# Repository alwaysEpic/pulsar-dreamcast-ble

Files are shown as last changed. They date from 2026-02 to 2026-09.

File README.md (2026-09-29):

# Pulsar Dreamcast BLE





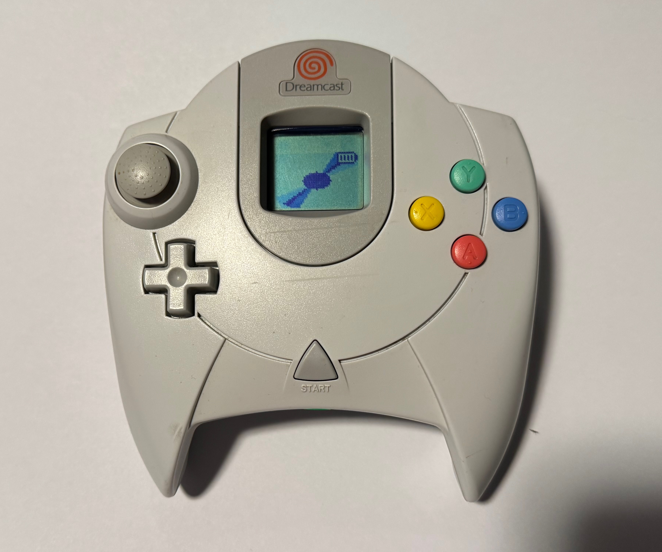
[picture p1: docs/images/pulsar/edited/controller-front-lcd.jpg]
Dreamcast controller with the Pulsar adapter's VMU LCD showing the rotating pulsar


Use your Dreamcast controller wirelessly with any Bluetooth device. Pulsar speaks the Dreamcast's Maple Bus protocol natively and presents itself as a standard Xbox One S BLE gamepad — just plug in, pair, and play.

### ⚡ [**Buy Pulsar — Dreamcast wireless controller adapter**](https://pulsar.alwaysagog.com/buy)

A complete wireless Dreamcast controller, Pulsar on its own, or the parts to build one —
at **[pulsar.alwaysagog.com](https://pulsar.alwaysagog.com/)**. Prefer to build it
yourself? [Start here](docs/build/xiao.md); everything you need is in this repo.

> **Where to get Pulsar firmware.** The only official sources are this repository's
> [Releases](https://github.com/alwaysEpic/pulsar-dreamcast-ble/releases) page and the
> updater at [pulsar.alwaysagog.com/update](https://pulsar.alwaysagog.com/update).
> Firmware ships as `.uf2`, `.hex`, or a signed OTA package — never as a `.zip`, `.exe`, or
> anything you run on a PC. Copies of this repo on other GitHub accounts that offer a
> "download" have been found carrying malware. Don't run them.

## Features

- All Dreamcast inputs: A/B/X/Y, Start, D-pad, analog stick, analog triggers
- Guide/Xbox button via a trigger + Start chord (opens the Steam overlay, Game Bar, etc.)
- Works with any BLE HID host (PC, iOS, Android, Switch, Dreamcast via iBlueControlMod)
- Two switchable identities for broad host compatibility: **Xbox** (default), or a plain **generic BLE HID gamepad** (labeled "Dreamcast" — neutral identity, not controller emulation)
- VMU LCD display: profile splash, rotating pulsar with battery indicator, mode splashes
- Host integration service: a program on the host can draw on the VMU LCD and read and write the docked VMU's saves over BLE — an open, documented protocol ([spec](docs/host_integration.md))
- 60Hz controller polling with continuous BLE reporting
- Pairing persists across power cycles (flash-based bonding)
- Battery powered (~7-8 hrs on 500mAh, ~14-16 hrs on 1000mAh) with sleep/wake support
- 3D-printable VMU-shaped enclosure included

## Compatibility

### Controllers
- Standard Dreamcast controller (first-party tested)

### Hosts

**Tested:**
- Steam Deck (as Xbox gamepad)
- macOS — browser + Steam (as Xbox gamepad)
- Windows — Steam (as Xbox gamepad)
- Linux — xpadneo (as Xbox gamepad)
- Dreamcast (via [iBlueControlMod](https://handheldlegend.com/products/dreamcast-ibluecontrolmod-bluetooth-mod) adapter)

**Should work (untested):**
- iOS, Android (as BLE HID gamepad)
- PlayStation, Nintendo Switch (as generic controller)

## Supported Boards

One firmware, three boards. They play identically; what differs is what they can show you and
how you flash them.

| Board | | Status light | Battery | Rumble | Flashing |
|---|---|---|---|---|---|
| **XIAO** | Hand-wired DIY build — the one this guide walks through | Onboard RGB | Voltage estimate | — | USB (UF2) |
| **Pulsar v1** | Designed carrier with a XIAO mounted on it | 5-LED bar (status + battery) | IP5306 gauge, 4 levels | Yes | Wireless (OTA) |
| **DK** | nRF52840-DK, bench only | Kit LEDs | — | — | Debug probe |

Pulsar v1 runs the same XIAO module as the DIY build, so the two share their silicon — the
carrier adds integrated power management, the LED bar, and a rumble motor around it. Its
fabrication files are not published, but the design is described in the
[bill of materials](docs/bill_of_materials.md) and all three boards' pin assignments are in
[pin mapping](docs/pin_mapping.md).

## Three paths — pick yours

Each board has its own guide, written to be followed start to finish.

| | Guide | For |
|---|---|---|
| 🔧 | **[Build the XIAO adapter](docs/build/xiao.md)** | The hand-wired DIY build. Perfboard, a boost converter, two resistors and two diodes. Soldering required, and it permanently modifies a controller |
| 🧪 | **[Bench setup on an nRF52840-DK](docs/build/dk.md)** | Development and debugging. No soldering, and no permanent change to a controller if you cut an extension cable instead |
| 📦 | **[Install an assembled Pulsar v1](docs/build/pulsar-v1.md)** | You bought one. Photo-by-photo: open the controller, fit Pulsar, route the cable, close it up |

Once it is together, the [user guide](docs/users_guide.md) covers all three boards, and
Pulsar v1 owners have a dedicated [owner's manual](docs/pulsar_v1_manual.md).

## Build Your Own

A summary of the **XIAO** build. The step-by-step version — cable identification, the 5 V
diode-OR, pre-power checks and first-boot behaviour — is in
**[docs/build/xiao.md](docs/build/xiao.md)**.

### What You Need

- Seeed XIAO nRF52840
- Dreamcast controller
- 5V boost converter (for battery mode)
- 2x 10kΩ resistors
- LiPo battery
- USB cable (for UF2 flashing) or debug probe (for development)

See the full [bill of materials](docs/bill_of_materials.md) for details.

### Wiring

Wiring Diagram

Connect SDCKA and SDCKB from the controller cable to the XIAO with 10kΩ pull-ups to 3.3V. The controller needs 5V power via a diode OR circuit (USB + boost converter). See [pin mapping](docs/pin_mapping.md) for the complete wiring reference.

> **Meter your cable before you solder.** The colour-to-pin table is the canonical Maple
> pinout, not a promise about the cable in your hand — third-party and later-revision
> controllers differ, and getting it wrong puts 5 V on a data line. The
> [build guide](docs/build/xiao.md#2-identify-the-cable-conductors) walks through checking
> it with a multimeter, and explains why the diode OR is there and which way round the
> diodes go.

### Flash

Pre-built firmware is available on the [Releases](https://github.com/alwaysEpic/pulsar-dreamcast-ble/releases) page.

**UF2 (recommended — no debug probe needed):**

The XIAO ships with a UF2 bootloader that includes the Nordic SoftDevice. Just double-tap the reset button — the board mounts as a USB drive (`XIAO-BOOT`) — then copy the `.uf2` file:

```bash
cp pulsar-dreamcast-ble-xiao.uf2 /Volumes/XIAO-BOOT/
```

The board auto-resets and runs the firmware.

**SWD (for development — requires J-Link or nRF52840 DK):**

If you need RTT debug logging, flash via SWD instead. The SoftDevice must be flashed separately first — see [flash commands](docs/flash-commands.md) for the full workflow.

### Pair and Play

1. Power on the adapter — it starts advertising immediately
2. On your host device, scan for **"Xbox Wireless Controller"**
3. Pair and you're done — bonding is saved automatically

**Sync button:**
- Short press → wake / request reconnect
- Hold 2s → pairing mode (keeps the current bond until a new host pairs)
- Hold 3.5s **while holding the controller's Start** → firmware update (OTA) mode
- Tap, tap, then hold 3.5s → the same update mode, no controller needed
- **Tap once, then hold 3.5s → browser configuration mode ([remap your buttons](docs/users_guide.md#remapping-buttons-from-your-browser))**
- Hold 7s → sleep (`BYE` splash, then powers off)
- Triple-press → switch profile (Xbox ⇄ Dreamcast identity)

**Guide / Xbox button:** pull both triggers and hold Start (~⅓ second) to send the Guide button — opens the Steam overlay / Big Picture, the Xbox Game Bar, etc. Works on both profiles.

The VMU LCD shows the active profile on connect, a rotating pulsar with battery indicator while in use, a home icon when you press the Guide chord, and splashes for pairing (`SYNC`) and sleeping (`BYE`).

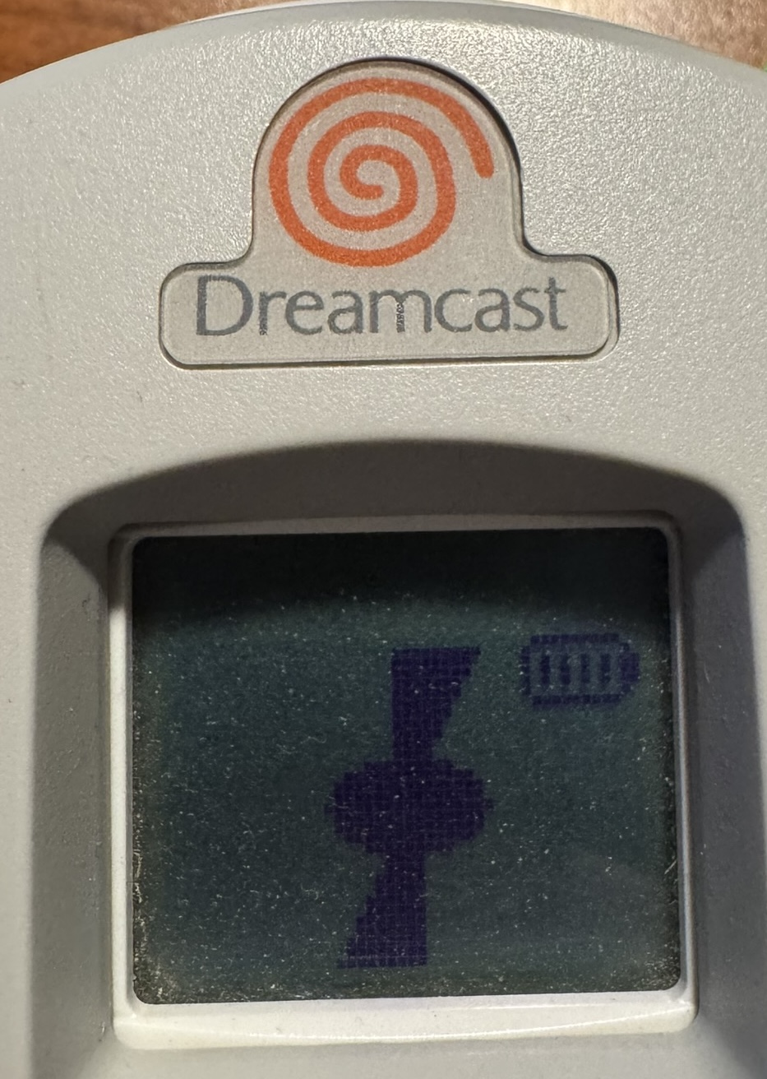
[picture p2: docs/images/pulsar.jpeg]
Rotating pulsar animation on the VMU LCD


See the [user guide](docs/users_guide.md) for all screens, profile choice, and troubleshooting.

### Enclosure

A 3D-printable VMU-shaped case is included in [`hardware/enclosure/`](hardware/enclosure/). See [hardware/enclosure/README.md](hardware/enclosure/README.md) for print tips and attribution.

<table>
  <tr>
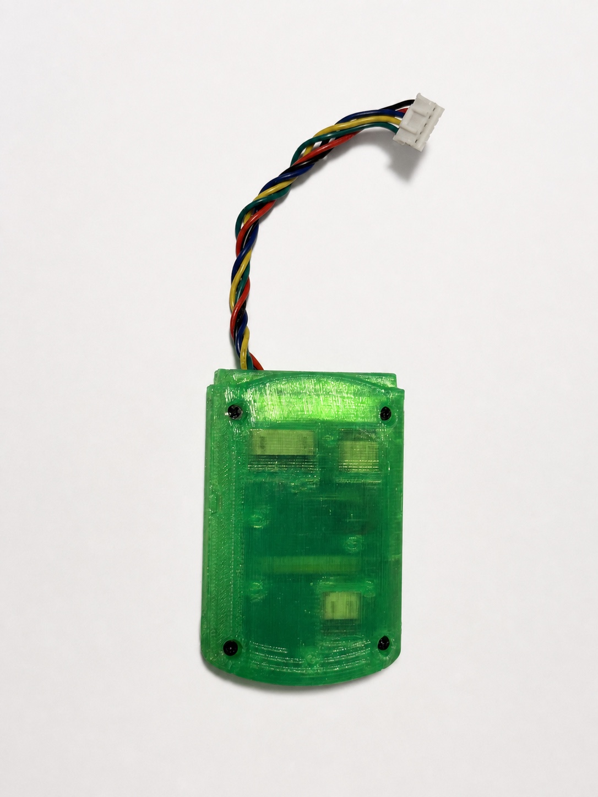
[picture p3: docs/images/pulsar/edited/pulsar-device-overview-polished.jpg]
Assembled Pulsar adapter, front
    <td></td>
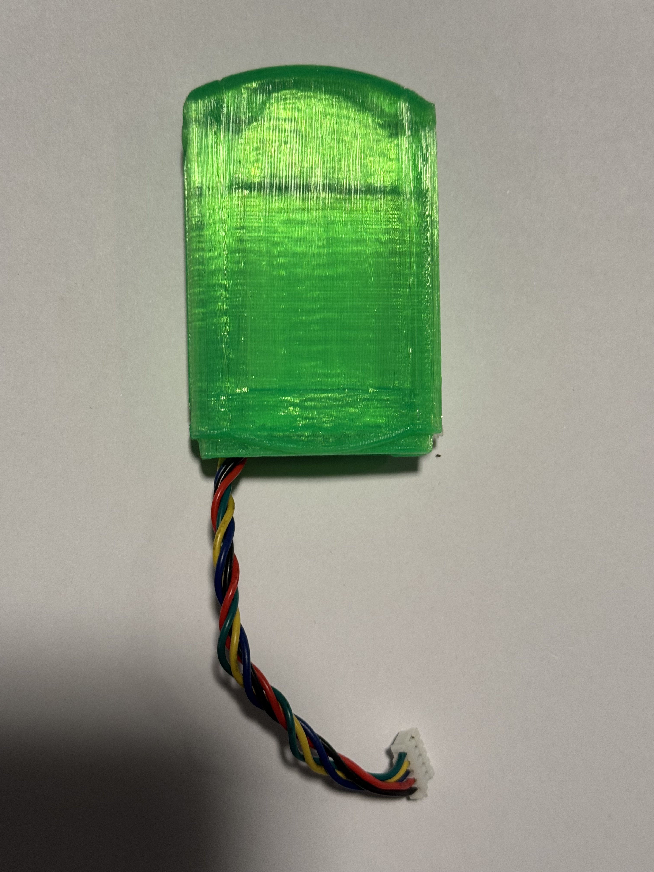
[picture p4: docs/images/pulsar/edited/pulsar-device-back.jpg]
Assembled Pulsar adapter, back with controller cable
    <td></td>
  </tr>
  <tr>
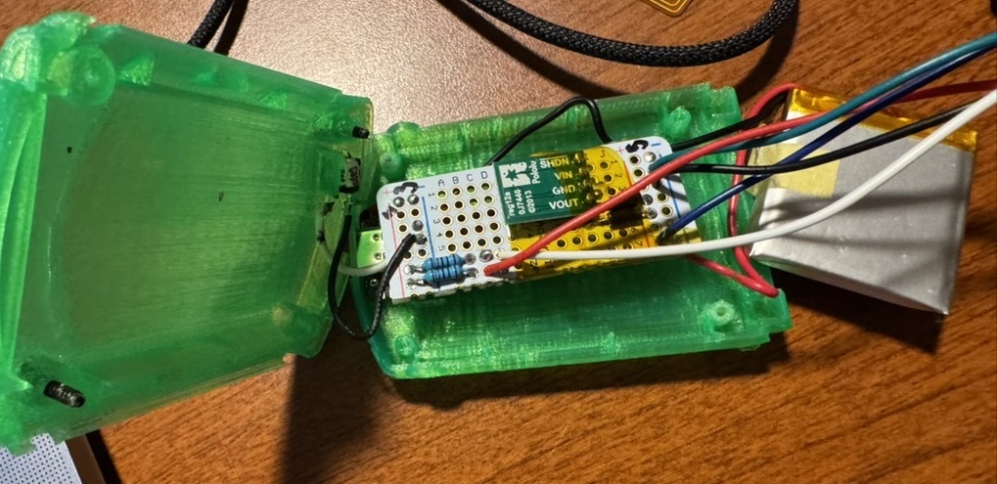
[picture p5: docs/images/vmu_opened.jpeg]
Inside the enclosure
    <td></td>
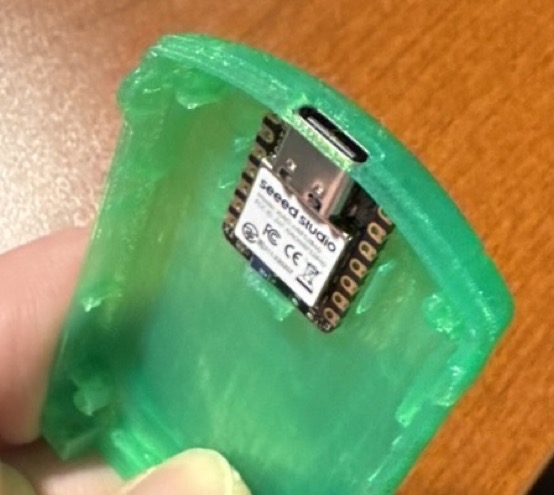
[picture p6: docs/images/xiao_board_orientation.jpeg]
XIAO board orientation
    <td></td>
  </tr>
</table>

## For Developers

### Building from Source

Requires Rust stable with `thumbv7em-none-eabihf` target:

```bash
rustup target add thumbv7em-none-eabihf
cargo install cargo-embed
```

**XIAO** (must use `--release` — debug builds break Maple Bus timing):
```bash
# Production
cargo embed --release --no-default-features --features board-xiao

# Development (with RTT debug logging)
cargo embed --release --no-default-features --features board-xiao,rtt
```

**DK** (RTT always enabled):
```bash
cargo embed --release
```

**Pulsar v1** (ships as a signed OTA package; SWD is for bring-up only):
```bash
cargo build --release --no-default-features --features board-pulsarv1
```

Each board has a start-to-finish guide under [`docs/build/`](docs/build/).

### Testing

The `maple-protocol` crate is pure Rust with no embedded dependencies — tests run on the host:

```bash
cd maple-protocol && cargo test
```

### Architecture

The project is split into two crates:

- **`maple-protocol/`** — Pure protocol library: controller state parsing, packet construction, Xbox HID report generation. No hardware dependencies, fully host-testable.
- **`src/`** — Firmware: Maple Bus GPIO bit-banging, BLE stack (Nordic SoftDevice S140), board support, button handling, power management.

The GPIO implementation bulk-samples both data lines at ~7.9 MS/s (≈4 samples per 500 ns bit) to capture the 2 Mbps Maple Bus protocol, then decodes in software. This is an nRF52840-specific approach — other chips (e.g., RP2040 with PIO) could implement the same protocol differently. See [maple_bus_protocol.md](docs/maple_bus_protocol.md) for the full protocol reference.

### Running Checks

```bash
./scripts/ci.sh
```

Runs formatting, the protocol tests, clippy for all three boards, every release build, and
then checks each ELF's timing invariants. `./scripts/check.sh [dk|xiao|pulsarv1]` is the ~2 s
inner loop to run after every change; `ci.sh` is the gate before a commit.

## Documentation

[`docs/MOC.md`](docs/MOC.md) indexes everything. The main entries:

| Document | Description |
|---|---|
| [Build guides](docs/build/) | One per board: [XIAO](docs/build/xiao.md), [DK](docs/build/dk.md), [Pulsar v1](docs/build/pulsar-v1.md) |
| [User Guide](docs/users_guide.md) | Using the adapter, across all three boards |
| [Owner's Manual](docs/pulsar_v1_manual.md) | For an assembled Pulsar v1 |
| [Bill of Materials](docs/bill_of_materials.md) | Parts list for building your own |
| [Pin Mapping](docs/pin_mapping.md) | Complete wiring reference for all three boards |
| [Flash Commands](docs/flash-commands.md) | Flashing and debugging cheat sheet |
| [Maple Bus Protocol](docs/maple_bus_protocol.md) | Protocol reference and implementation details |
| [Host Integration](docs/host_integration.md) | The BLE service a host uses to drive the VMU's screen and saves |
| [Input Quality Testing](docs/input_quality_testing.md) | Measuring latency and packet loss |
| [Battery Optimization](docs/battery_optimization.md) | Power management strategy |
| [Learnings](docs/learnings.md) | Implementation lessons learned |

## Releases

Pre-built firmware is available on the [Releases](https://github.com/alwaysEpic/pulsar-dreamcast-ble/releases) page. Each release includes:

- **`pulsar-dreamcast-ble-xiao.uf2`** — XIAO firmware, drag-and-drop via UF2 bootloader
- **`pulsar-dreamcast-ble-xiao.hex`** — XIAO firmware, for flashing via J-Link/SWD
- **`pulsar-dreamcast-ble-dk.hex`** — DK firmware, for flashing via J-Link

3D scan archives are also attached to releases.

Pulsar v1 units update over the air from
[pulsar.alwaysagog.com/update](https://pulsar.alwaysagog.com/update); the packages are signed
and the device refuses anything else. There are no other download locations. If a copy of this
repo somewhere else offers a `.zip` or a Windows program, it isn't ours — see the note at the top.

## Contributing

Contributions are welcome! See [CONTRIBUTING.md](CONTRIBUTING.md) for build instructions, project structure, and how to submit changes.

## License

This project is licensed under the [GNU General Public License v3.0 or later](LICENSE). 3D model files have separate licensing — see [hardware/enclosure/README.md](hardware/enclosure/README.md).

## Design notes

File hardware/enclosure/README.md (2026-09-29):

# 3D Models & Enclosure Files

This directory contains 3D models for a VMU-shaped enclosure for the Dreamcast BLE adapter.

## Which shell do I print?

Two different builds live in `Edited_VMU_stls/`, and they are not interchangeable — the
hand-wired XIAO build and the Pulsar v1 carrier are different shapes inside.

| Folder | For | Notes |
|---|---|---|
| `dreamcast_vmu_*.stl` (loose, at the top of `Edited_VMU_stls/`) | **[The hand-wired XIAO build](../../docs/build/xiao.md)** | Front plus three back variants — plain, `_cutout`, and `_w_cutout` — differing in the opening for your wiring. Print the front and whichever back suits how you routed the cable |
| `PulsarFit_703035/` | **Pulsar v1 carrier**, 703035 cell | The baseline fit: a 7.0 × 30 × 35 mm, ~800 mAh pouch. Clearance at the dome crown is ~0.5 mm, so it wants that cell. Ships a `PRINT_PLATE.stl` with the parts laid out |
| `PulsarFit_bigcell/` | **Pulsar v1 carrier**, larger cells | Same rear and plunger; the **front** hollows the dome to a constant 1.0 mm wall, raising crown clearance to ~1.5 mm so taller pouches fit. Includes `pulsar_bigcell.3mf` — the slicer project with orientation, supports and settings the STLs alone do not carry |
| `PulsarFit_bigcell_cable_relief/` | **Pulsar v1 carrier**, big cell, cable-corner relief | ⚠️ **Experimental — not yet fit-tested.** Adds a filleted relief cut at the cable corner of *both* halves, for a pinch between the shell corner and the controller's connector housing. Print it only if you hit that pinch. Includes `pulsar_bigcell_cable_relief.3mf` |

> The cable-relief variant was cut in a live modelling session rather than by the build
> scripts, so re-running `blender_files/build_pulsar_vmu*.py` reproduces the shells
> **without** it. Treat those STLs as the source of truth for that variant.

Every Pulsar-fit family shares the same `pulsar_vmu_button_plunger.stl`.

## Contents

- **`blender_files/`** — Blender source files for the modified VMU enclosure (by alwaysEpic)
- **`Edited_VMU_stls/`** — Modified STL exports ready for printing (by alwaysEpic); see the
  table above for which folder matches your build
- **`VMU_ShellAssembly.step`** — STEP assembly file
- **`pulsar_pcb.stl`**, **`Pulsar.step`** — the carrier board as a mesh/solid, for fit-checking only. Not manufacturing data; no board can be fabricated from them.
- **`cable_hole_plug.stl`** — Cable hole plug by [byt3swap](https://github.com/byt3swap/dreamwave-enhanced) (used with permission)

## Printing Tips

The front and back halves print best at roughly a 45-degree angle with a few supports. This gives cleaner surfaces and avoids overhangs on the curved shell edges.

## Attribution

- **Modified enclosure** (Blender files, edited STLs) by [alwaysEpic](https://github.com/alwaysEpic) — modelled against the VMU scans below. If you use or remix these, please credit the author.
- **VMU 3D scans** by [Wesk](https://bitbuilt.net/forums/threads/dreamcast-vmu-scan.3988/) — the reference this enclosure was built from.
- **Cable hole plug** by [byt3swap](https://github.com/byt3swap/dreamwave-enhanced) — used with permission

## License

These files are **not** covered by the project's GPL-3.0 licence.

The Blender sources and edited STLs are the author's own modelling work — the Pulsar cutouts, pockets, plunger, tolerances, and print splits — and are offered under [CC BY 4.0](https://creativecommons.org/licenses/by/4.0/): use, modify, and redistribute them with attribution.

That grant covers only the author's own modelling work. `cable_hole_plug.stl` is byt3swap's and is included by permission; its terms are theirs, not ours.

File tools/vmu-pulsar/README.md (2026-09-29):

# VMU pulsar animation

The rotating pulsar on the VMU LCD is rendered in Blender and baked to a 1-bit
frame table, `src/vmu/pulsar_frames.rs`. Nothing here runs at build time; the
generated file is committed.

```bash
cd tools/vmu-pulsar
/Applications/Blender.app/Contents/MacOS/Blender -b -P render_pulsar.py -- "$PWD/renders" 12
uv run --with pillow --with numpy python bake_frames.py renders ../../src/vmu/pulsar_frames.rs renders/preview.gif
```

`renders/` is ignored. `preview.gif` plays the frames at the firmware's rate
(~300 ms, `VMU_ANIM_INTERVAL` polls) in VMU LCD colours.

- **Frame count** is `ROTATION_FRAMES` in `src/vmu.rs`. It must match the render,
  and the firmware rate is fixed, so more frames means a slower spin.
- **Geometry** (tilt, beam width, fade) lives in `render_pulsar.py`.
- **Composition** (dither, star disc, sky, flash) lives in `bake_frames.py`.

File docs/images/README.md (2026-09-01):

# Images

Photos of the Dreamcast BLE adapter build.

## Assembly Photos

| File | Description |
|---|---|
| `vmu_front.jpeg` | Enclosure front — controller cable exits bottom |
| `vmu_back.jpeg` | Enclosure back — screw holes visible |
| `vmu_opened.jpeg` | Enclosure opened — perfboard, Pololu boost, pull-up resistors |
| `vmu_opened2.jpeg` | Enclosure opened — alternate angle showing battery and wiring |
| `xiao_board_orientation.jpeg` | XIAO board seated in enclosure front — USB-C and sync button visible |
| `vmu_in_controller.jpeg` | Adapter installed in Dreamcast controller VMU slot — front view |
| `vmu_in_controller2.jpeg` | Adapter installed — side angle showing Dreamcast logo |
| `back_fit.jpeg` | Controller back shell — VMU enclosure fit with wiring routed |
| `vmu_slot_holes.jpeg` | VMU slot closeup — arrow showing cable routing |
| `controller_modification.jpeg` | Controller shell modification — arrows showing trimmed plastic for cable clearance |
| `larger_wiring_example.jpeg` | Perfboard wiring — XIAO, boost converter, battery, controller cable |
| `breadboard_wiring.jpeg` | DK development breadboard — pull-ups and controller cable connections |

## Install Photos

`install/` — the photo-by-photo sequence for
[fitting a Pulsar v1 into a controller](../build/pulsar-v1.md). Same exports the site's
install page uses.

| File | Description |
|---|---|
| `controller-back-screws.webp` | The six screw positions on the controller's back shell |
| `controller-open-cable-connected.webp` | Controller open, original cable still connected |
| `dreamcast-cable-removed.webp` | Original cable and strain relief lifted out |
| `second-accessory-slot.webp` | The empty second accessory slot |
| `pulsar-installed-overview.webp` | Pulsar seated in slot 2, cable routed to the right-hand opening |
| `pulsar-cable-connected.webp` | Pulsar's plug seated in the controller connector — plug orientation |
| `back-cover-cable-guard-before.webp` | Inside of the back shell, cable guard still present |
| `back-cover-cable-guard-removed.webp` | The same shell after a clean break |
| `cable-cover-and-routing.webp` | Printed cable cover fitted around the Pulsar cable |

## Wiring Diagrams

See [`../wiring/`](../wiring/) for the Fritzing diagram and breadboard export.

## Metadata

Every image here is published. **Before adding one, strip its metadata and verify:**

```bash
python3 scripts/image_metadata.py strip docs/images   # lossless — drops APP segments only
python3 scripts/image_metadata.py scan  docs          # exits 1 if any GPS remains
```

Stripping is lossless — JPEG scan data is untouched and only whole APP segments are
dropped, so there is no requantisation. A non-default `Orientation` is preserved; drop it
and the affected images rotate.

**Verify by parsing the file, not by asking an indexer.** On macOS, `mdls -name
kMDItemLatitude` reads the Spotlight index rather than the image and returns `(null)` for
anything Spotlight has not indexed — it will happily report a GPS-laden photo as clean.
The script above parses the containers directly (JPEG APP segments, PNG `eXIf`, WebP
`EXIF`/`XMP `) and exits non-zero when a GPS IFD is present.

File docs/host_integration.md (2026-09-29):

# Host Integration Service

A vendor GATT service that lets a host — a console-side dongle, an emulator,
or a script on a laptop — drive the VMU docked in a Pulsar controller: push
frames to its LCD, and read and write the physical memory card's 512-byte
blocks. It first shipped in firmware **0.6.0**; no earlier release carries it.

This is an *open* vendor characteristic set: anything malformed that arrives
on it is dropped in silence rather than erroring the connection. It exists so
a third party can write a sender without our hardware in the room.

## How to tell it is a Pulsar

Look for the service UUID below in the GATT table after connecting — it is
not advertised, so it will not appear in a scan result, only after connect
and discovery. It is present identically under **both** gamepad personalities
(the Xbox identity and the generic one): they share one GATT table, and the
personality only changes the GAP name, the PnP IDs and the HID report
descriptor. The service, not the identity, is what marks a Pulsar. The third
personality, `Pulsar Configure` (browser remapping), is a different GATT
table and does not carry this service.

## Service and characteristics

| Name | UUID | Properties | Security | Max length |
|---|---|---|---|---|
| `HostService` | `7EDF0001-3536-4A03-82D0-8AB9122016C6` | (primary service) | — | — |
| LCD frame | `7EDF0002-3536-4A03-82D0-8AB9122016C6` | Write Without Response | JustWorks | 192 B |
| VMU storage, up | `7EDF0003-3536-4A03-82D0-8AB9122016C6` | Notify | JustWorks | 132 B |
| VMU storage, down | `7EDF0004-3536-4A03-82D0-8AB9122016C6` | Write Without Response | JustWorks | 132 B |

Security is `JustWorks` — encrypted, unauthenticated — the same level as the
HID report characteristics. A host already bonded as a gamepad gets this for
free. Both down characteristics are Write Without Response, which by the ATT
spec never answers, so **a write on an unencrypted link is dropped in
silence** — there is no error to catch. **Pair the controller with the host
first.**

Only the bonded host may use the service. While a bond exists, a different
device that tries to pair outside the pairing window (the 2-second sync hold)
is disconnected, and nothing it writes to this service is acted on. Nothing
is notified on a link that is not encrypted.

This keeps out devices that merely happen to be in range. It is not
authentication: pairing is Just Works (there is no code to confirm), and the
bonded host is recognised by its Bluetooth address. A device that deliberately
impersonates that address can still pair.

The firmware requests an ATT MTU of 247 on connection; what a link actually
gets depends on the host's stack (some grant less). Two thresholds matter:

- **LCD:** a whole 192-byte frame needs a negotiated MTU of at least 195 to fit
  one write. Below that, use the four-write chunked shape described below.
  Both shapes are always accepted, told apart purely by the write's length —
  a sender never has to announce which one it is using.
- **VMU storage:** every `DATA` notification and every `WRITE` phase is 132
  bytes, so the storage protocol needs an MTU of **at least 135**. It has no
  chunked alternative; on a smaller MTU, do not use it.

## LCD frame channel

The VMU LCD is 48×32 pixels, 1 bit per pixel, 192 bytes total: 32 rows of 6
bytes each, MSB = leftmost pixel, and a set bit is a lit (dark) segment. This
is the same layout the Dreamcast itself puts on the Maple bus in a
`BLOCK_WRITE` to function `0x04` — the payload is exactly what a real console
would send to the VMU's LCD.

**Send the frame unrotated.** The VMU sits upside-down in the controller, and
Pulsar corrects for that in firmware before the frame reaches the physical
screen. A sender that pre-rotates ends up upside-down; frames arriving from a
Maple `BLOCK_WRITE` capture, or drawn upright, are already correct.

### Wire shapes

| Shape | Length | Contents |
|---|---|---|
| Whole frame | 192 bytes | The full frame, row-major, as above. |
| Chunk (×4) | 49 bytes | `[row_offset, chunk[48]]` — one 8-row band. |

`row_offset` is one of `0, 8, 16, 24` and must land on that boundary; a chunk
whose offset is not a multiple of 8, or out of range, is dropped. Offset `0`
starts a new frame — writing it clears whatever partial assembly was in
progress, so a sender that drops a chunk mid-frame resynchronises cleanly on
its next pass instead of ever producing a frame stitched from two sources.
The frame becomes visible only once all four chunks have arrived. Send the
chunks in order, `0` first: a set sent `8, 16, 24, 0` never completes, since the
final `0` starts over. A whole-frame write also discards any partial chunk set.

A write of any other length is dropped and never reaches the screen.

**The host owns the screen from its first frame until the link drops.** The
adapter's own animation stops while a host is drawing and resumes after the
disconnect. One exception: while acked VMU writes are draining onto the card
(below), the firmware overlays a small disk icon on the top-left corner of
whatever is on screen, the host's frame included, and removes it when the
drain ends.

Frames **replace**, they are never queued: sending faster than the display
can draw simply loses the frames in between, which is the right behaviour for
a screen. There is no acknowledgement on this characteristic either way — a
frame can be dropped by the radio, or by the VMU's own CRC on the Maple bus,
and nothing reports it back. Send something recognisable and look at the
screen.

### Sample frame

A small asymmetric test pattern — a border plus a filled block in one
corner — so a rotation mistake anywhere in the chain is visible as the block
landing in the wrong corner. 32 rows of 6 bytes, whole-frame shape:

```
FF FF FF FF FF FF
80 00 00 00 00 01
BF C0 00 00 00 01
BF C0 00 00 00 01
BF C0 00 00 00 01
BF C0 00 00 00 01
BF C0 00 00 00 01
BF C0 00 00 00 01
BF C0 00 00 00 01
BF C0 00 00 00 01
80 00 00 00 00 01   (repeats through row 30)
FF FF FF FF FF FF
```

### Reference sender

`scripts/lcd_push.py` is a standalone `uv`-run script (`bleak` + `pillow`)
that connects, negotiates the shape from the actual negotiated MTU, and
streams either a built-in pattern or a 48×32 image:

```
uv run scripts/lcd_push.py --scan                        # find the controller
uv run scripts/lcd_push.py --connected --pattern corner   # macOS, already paired
uv run scripts/lcd_push.py --address <addr> --png art.png --shape chunks
uv run scripts/lcd_push.py --pattern corner --hex         # dump the bytes, no radio
```

On macOS specifically: pair through System Settings first, then use
`--connected` — a paired controller stops advertising, so `--scan`/`--address`
cannot see it; `--connected` asks the OS for the already-connected device by
service UUID instead.

## VMU storage protocol (v1)

Read and write access to the 512-byte blocks of
the VMU physically docked in the controller, over the `…0003`/`…0004` pair.
Block numbers are one byte, `0`–`255`; `255` is the card's root block and
`254` its FAT, in the standard VMU filesystem layout.

**Byte order.** Every payload on this protocol — a `81 DATA` reply, and a `02
WRITE` request where that exists — carries a block's bytes in **image
order**: the order the VMU's own filesystem lays them out in, which is *not*
the raw word order the Maple bus carries them in (the wire reverses each
32-bit word). The firmware converts once, on the way in and out; a reader
does not need to know the wire order exists.

### Down: `…0004`, Write Without Response

| Op | Bytes | Meaning |
|---|---|---|
| `0x01` READ | `[01, blk]` | Request one block. One outstanding at a time — see below. |
| `0x03` STATUS? | `[03]` | Ask for a `STATUS` notification on demand. |
| `0x02` WRITE | `[02, blk, phase, seq]` + 128 B | One of four phases of a block write — see [Writing a block](#writing-a-block). |

Lengths are exact: `READ` is 2 bytes, `STATUS?` 1 byte, `WRITE` 132 bytes.
Anything else is dropped in silence.

A `READ` sent while one is already outstanding (including while its `DATA`
phases are still going out) is silently refused — nothing is sent back, not
even an error. The rule is the sender's to keep: wait for the fourth `DATA`
(or a `DATA` carrying a non-zero result) before issuing the next `READ`.

A `READ` accepted while the pad is in use is **held, not refused**: it is
served once the pad goes idle, and if input resumes mid-read the firmware
recalls it and serves it again at the next idle. Only a `READ` with no VMU
docked is answered at once (`DATA … NO_VMU`).

### Up: `…0003`, Notify

| Op | Bytes | When |
|---|---|---|
| `0x81` DATA | `[81, blk, phase, result]` + 128 B, or just the 4-byte header when `result != 0` | Four per successful `READ`, phases `0`–`3`; one message with no data on failure. |
| `0x83` STATUS | `[83, proto=1, flags, queue_free, epoch u32 LE, card u32 LE]` (12 bytes) | On subscribe, on request (`03`), and whenever `flags`, `queue_free`, `epoch` or `card` change while connected. On reconnect, a change to `flags` or `queue_free` made while the link was down is announced, but a moved `epoch` or `card` is not — send `03`. |
| `0x82` ACK | `[82, blk, seq, result]` (4 bytes) | Answers a completed four-phase `WRITE`, or a phase that broke the rules (`BAD`). |
| `0x84` WRITTEN | `[84, blk, seq, result]` (4 bytes) | Once per acked `seq`, when its fate is known. One in flight as the link drops can be lost: see [Sessions and reconnects](#sessions-and-reconnects). |

Messages go out in a fixed priority: `STATUS` first, then `ACK`s (and
`WRITTEN … SUPERSEDED`), then other `WRITTEN`s in drain order, then `DATA`.
`STATUS` leads because it is one message and a host may be blocked on it
right after connecting; `DATA` is last because a block's phases wait on
nothing, and the pad is idle by definition while a read is being served.

### `flags` (byte 2 of `STATUS`)

| Bit | Name | Meaning |
|---|---|---|
| 0 | `vmu_present` | A VMU is docked and enumerated. |
| 1 | `enabled` | Always `1` at this revision. Reserved for a future setting that turns the service off; until one exists it carries no information. |
| 2 | `draining` | One or more acked writes are staged or being written and not yet confirmed on the card. Always `0` on builds without the write path. |
| 3 | `idle` | The pad has gone at least 1 second with no button change and no stick or trigger movement past a small deadzone. Reads are served only while this is set. |

### `result` codes

| Code | Name | Meaning |
|---|---|---|
| `0` | OK | |
| `1` | FULL | The `WRITE` was refused: no free queue slot, or the card's fingerprint is not yet known (read blocks `255` and `254` first). |
| `2` | NO_VMU | No VMU is docked. |
| `3` | DISABLED | Reserved for the same future setting as `enabled`; never produced at this revision. |
| `4` | FAILED | `DATA`: the block read failed every attempt the firmware allows. `WRITTEN`: the write could not be confirmed within the firmware's attempts — the card refused a phase or the commit, or the read-back did not match or could not be read. This also ends the current generation (below). |
| `5` | DISCARDED | The generation ended (below) before this READ or WRITE could be answered normally. |
| `6` | SUPERSEDED | A different `seq` for the same block replaced this one while it was still staged; nothing was written under the superseded `seq`. |
| `7` | BAD | A `WRITE` phase broke the assembly rules ([Writing a block](#writing-a-block)). |

### Reading a block

1. Subscribe to `…0003`. A `STATUS` notification follows immediately.
2. Check `flags`: bit 0 (`vmu_present`) must be set, and reads only progress
   while bit 3 (`idle`) is set — put the pad down and leave it alone.
3. Write `[0x01, blk]` to `…0004`.
4. Collect four `81 DATA` notifications, `phase` `0`–`3`, each `result == 0`
   with 128 bytes of payload; concatenate `phase * 128 .. +128` in order to
   reassemble the 512-byte block. A single `DATA` with `result != 0` and no
   payload ends the request instead — inspect the `result` code.
5. Only after that (or after a non-zero-result `DATA`) may the next `READ` be
   issued.

**Generations.** `epoch` moves whenever the docked card is no longer known to
be the one being served: a dock or an undock, the controller being lost, the
link dropping (see [Sessions and reconnects](#sessions-and-reconnects)), the
controller's power going down (including sleep), a write that `FAILED`, or the
firmware being unable to confirm the card is the same one after a write was
interrupted. Its first value after boot is arbitrary. If a generation ends
while a `READ` is outstanding or its `DATA` phases are still going out,
whatever was owed becomes a single `DATA … DISCARDED` rather than silence, so a
sender is never left waiting for a fourth phase that will not come. Staged
writes become `WRITTEN … DISCARDED` the same way.

**The card fingerprint.** `card` in `STATUS` is an FNV-1a 32-bit hash, seed
`0x811C9DC5`, taken over block `255`'s 512 bytes and then block `254`'s, both
in image order — it reads `0` until both blocks have been read (or
written) at least once in the current generation. A
host that wants to know it is talking about the same card it already knows
should compare this against its own hash of the same two blocks, computed
the same way.

### Writing a block

**Which builds write.** Pulsar v1 and XIAO builds serve both reads and
writes. The DK build has no VMU storage path at all: it reports no VMU
(`flags` reads `0x02`), answers every `READ` with `DATA … NO_VMU`, keeps
`queue_free` at `0`, and answers every completed `WRITE` with `ACK … NO_VMU`.
A sender should honour `STATUS` rather than assume either.

To write a block:

1. Send four `02 WRITE` phases for the same block and the same `seq` (a
   sender-chosen byte, one value per block write), phase `0` first and in
   order. Phase `0` always starts a fresh assembly, discarding any half-sent
   one. Resending a phase already received overwrites it. Answered
   `ACK … BAD` and discarded: a phase `≥ 4`; phase `1`–`3` with no assembly
   open, or for a different block or `seq`; a phase that skips ahead.
2. Once all four phases are in, the block is staged and answered
   `ACK … OK` — or refused: `NO_VMU` if nothing is docked, `FULL` if the
   queue has no room, is not open, or the card's fingerprint is not yet known
   (read blocks `255` and `254` first).
3. A resend of a `(block, seq)` the firmware still holds — a retry after a lost
   `ACK` — is acknowledged again without being staged twice. A `WRITE` for a
   block that is still staged under a different `seq` replaces it in place,
   keeping its position in the drain order; the replaced `seq` receives
   `WRITTEN … SUPERSEDED` immediately, and the new one its own `ACK` and,
   later, its own `WRITTEN`. If the earlier write has already started going to
   the card, the new one is staged separately and drains after it.
4. Staged blocks drain to the physical card in the order they were first
   staged. Each one receives one `WRITTEN` (unless the link drops as it goes
   out; see below): `OK` once the firmware has
   read the block back from the card and it matched, `FAILED` if that could not
   be achieved (which also ends the generation — every other block still
   staged becomes `DISCARDED`), or `DISCARDED` if the generation ends first for
   any other reason.

The queue holds **8** blocks. `queue_free` in `STATUS` is the number of free
slots and is the flow-control signal: never have more acked-but-unwritten
writes in flight than the last `queue_free` allowed. A slot stays occupied
until its `WRITTEN` has been sent.

**Keep a retry timer.** If the firmware's outgoing buffer is full, a completed
`WRITE` can be dropped with no `ACK` at all. Resend the same `(block, seq)`
until it is acked; step 3 makes that safe while the firmware still holds the
block. Once the `ACK` arrives, stop resending: a resend that lands after the
block's `WRITTEN` has gone out is staged again, written a second time (the same
bytes, so the card is unharmed), and answered with a second `ACK` and
`WRITTEN`. A sender should tolerate that pair rather than rely on never
seeing it. The `WRITTEN` is always the answer that counts: an `ACK … OK` for
a resend after a reconnect can be followed by `WRITTEN … DISCARDED`.

### Sessions and reconnects

A dropped link immediately loses what was in flight: an outstanding `READ`, a
half-sent `DATA`, a half-assembled `WRITE` and any undelivered `ACK`s.

Acked writes keep draining onto the card while the link is down, for up to
30 seconds. Once nothing is left to drain (at once, if the queue was empty), or
when the 30 seconds run out, the generation ends: `epoch` moves, `card` reads
`0`, and anything still staged becomes `WRITTEN … DISCARDED`. Every `WRITTEN`
still owed at the drop, whatever its result, is delivered on the next
connection. The exception is one already handed to the radio: a `WRITTEN` in
flight as the link drops can be lost, and it is not sent again.

So on reconnect, read `STATUS` (send `03`, below). An unchanged `epoch` means
the host reconnected while its writes were still draining, and the generation
carried on. A moved `epoch` means read blocks `255` and `254` again before
writing, then resend whatever came back `DISCARDED`, and anything never acked.

Either way, do not wait on `WRITTEN`s for writes acked before the drop. Once
`STATUS` shows `draining` clear, a write that still has no `WRITTEN` has an
unknown fate: read the block back and compare, or resend it. A resend is safe
(step 3 above): the same bytes are written again and answered with a fresh
`WRITTEN`.

`STATUS` is sent when the host *writes* the CCCD to enable notifications. A
host that relies on a subscription restored from the bond may get no `STATUS`
until something changes, so **send `[03]` after every connect**.

## Reference scripts

Both are standalone `uv`-run Python (no project virtualenv needed):

```
uv run scripts/lcd_push.py --connected --pattern corner
uv run scripts/vmu_read.py --connected                      # root + FAT
uv run scripts/vmu_read.py --connected --pull                # the whole used working set
uv run scripts/vmu_read.py --connected --blocks 255 --hexdump
```

`vmu_read.py` shares `lcd_push.py`'s connection handling (including the
macOS `--connected` pairing workaround above), decodes `STATUS`/`DATA`,
verifies the root block parses correctly in image order, and cross-checks its
own computed `card` fingerprint against the firmware's. `--pull` walks the
root block, FAT and directory to fetch those plus every user-area block the
FAT marks as used. Neither script exercises the write path (`02 WRITE`);
there is no public reference writer yet, and the write section above is
specified from the firmware's code and tests.

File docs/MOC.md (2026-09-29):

---
type: moc
created: 2026-08-06
tags: [index, public]
---

Map of content for the documentation tree. One line per doc — read this to locate a doc
rather than preloading the folder.

## Build and use

Three boards, three build paths. Pick the one that matches what you have:

- [`build/xiao.md`](build/xiao.md) — **the DIY build.** Hand-wired XIAO nRF52840: parts,
  identifying the cable conductors, the 5 V diode-OR, pull-ups, pre-power checks, UF2
  flashing, first boot, enclosure
- [`build/dk.md`](build/dk.md) — **the bench build.** nRF52840-DK on a breadboard; no
  soldering, external 5 V, SWD flashing and RTT. What behaves differently on this board
- [`build/pulsar-v1.md`](build/pulsar-v1.md) — **installing an assembled Pulsar v1** in a
  controller, photo by photo. Markdown copy of the site's install guide

- [`pulsar_v1_manual.md`](pulsar_v1_manual.md) — owner's manual for an assembled Pulsar v1:
  connecting a controller, buttons, LEDs, charging, updating. Start here for a shipped unit
- [`users_guide.md`](users_guide.md) — the same ground across all three boards (v1, DIY
  XIAO, DK); the reference the manual defers to
- [`flash-commands.md`](flash-commands.md) — UF2, DFU, and probe recipes; build variants
- [`bill_of_materials.md`](bill_of_materials.md) — parts for the XIAO and Pulsar v1 builds
- [`pin_mapping.md`](pin_mapping.md) — pin assignments across all three boards

## Protocol and firmware

- [`maple_bus_protocol.md`](maple_bus_protocol.md) — the Maple Bus reference, consolidated
  from three sources; the authoritative copy
- [`learnings.md`](learnings.md) — lessons from 2 Mbps bit-banged GPIO on the nRF52840,
  written to generalize beyond this project
- [`input_quality_testing.md`](input_quality_testing.md) — measuring packet loss and
  input latency; the issue #5 investigation end to end
- [`test_plan.md`](test_plan.md) — the full adapter test plan
- [`host_integration.md`](host_integration.md) — the vendor GATT service a host uses
  to drive the docked VMU — LCD frames in both wire shapes, and the VMU storage protocol v1

## Power

- [`battery_optimization.md`](battery_optimization.md) — power strategy on a single-cell
  LiPo; measured active runtimes, calculated standby

## Assets

`images/`, `wiring/`, and `signal_references/` — photos, wiring diagrams, and captured
Maple Bus traces referenced by the docs above.

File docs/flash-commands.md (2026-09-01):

# Flash & Debug Reference

Three boards, three routes. Pick by what you have:

| Board | Feature | How it's flashed |
|---|---|---|
| **XIAO** | `board-xiao` | [UF2 over USB](#uf2-flashing-recommended) — no probe needed. Add `,rtt` for debug logging |
| **DK** | `board-dk` | [SWD](#swd-flashing-development) via the onboard J-Link. Includes `rtt` by default |
| **Pulsar v1** | `board-pulsarv1` | [Signed OTA](#pulsar-v1-signed-ota), or SWD for bring-up |

Release builds are mandatory on all three — debug builds miss the Maple Bus timing window.

## UF2 Flashing (Recommended)

The easiest way to flash the XIAO — no debug probe needed. The XIAO ships with a UF2 bootloader that includes the Nordic SoftDevice S140 v7.3.0.

### Flash Pre-Built Firmware

1. Download the `.uf2` file from [Releases](https://github.com/alwaysEpic/pulsar-dreamcast-ble/releases)
2. Double-tap the reset button on the XIAO — it mounts as `XIAO-BOOT`
3. Copy the file to the drive:
   ```bash
   cp pulsar-dreamcast-ble-xiao.uf2 /Volumes/XIAO-BOOT/
   ```
4. The board auto-resets and runs the firmware

### Build and Flash from Source

```bash
# Build (production — no RTT logging)
cargo build --release --no-default-features --features board-xiao

# Build (development — with RTT debug logging)
cargo build --release --no-default-features --features board-xiao,rtt

# Convert ELF → HEX → UF2
rust-objcopy -O ihex \
  target/thumbv7em-none-eabihf/release/pulsar-dreamcast-ble \
  target/pulsar-dreamcast-ble.hex

python3 uf2conv.py \
  -c -f 0xADA52840 \
  -o target/pulsar-dreamcast-ble.uf2 \
  target/pulsar-dreamcast-ble.hex

# Double-tap reset, then copy
cp target/pulsar-dreamcast-ble.uf2 /Volumes/XIAO-BOOT/
```

**uf2conv.py** is from [Microsoft's UF2 repo](https://github.com/microsoft/uf2/tree/master/utils). Download `uf2conv.py` and `uf2families.json` into the same directory.

### Restore Stock Bootloader

If the bootloader has been overwritten (e.g., by SWD flashing), restore it with a J-Link:

```bash
curl -LO https://github.com/adafruit/Adafruit_nRF52_Bootloader/releases/download/0.10.0/xiao_nrf52840_ble_bootloader-0.10.0_s140_7.3.0.hex

nrfjprog --program xiao_nrf52840_ble_bootloader-0.10.0_s140_7.3.0.hex --chiperase --verify --reset
```

This restores both the UF2 bootloader and SoftDevice S140 v7.3.0 in a single flash.

---

## SWD Flashing (Development)

For development with RTT debug logging. Requires a J-Link probe or nRF52840 DK.

### Environment Setup

```bash
rustup target add thumbv7em-none-eabihf
cargo install cargo-embed
```

### SoftDevice

The Nordic S140 SoftDevice must be flashed once before the application. Download v7.3.0 from [Nordic's website](https://www.nordicsemi.com/Products/Development-software/S140/Download).

```bash
nrfjprog --eraseall
nrfjprog --program s140_nrf52_7.3.0_softdevice.hex --verify
```

### Building & Flashing

**XIAO** — must use `--release` (debug builds break Maple Bus timing):
```bash
# Development (with RTT logging)
cargo embed --release --no-default-features --features board-xiao,rtt

# Production (no RTT — smaller binary, slightly lower power)
cargo embed --release --no-default-features --features board-xiao
```

**DK** (default target, always includes RTT):
```bash
cargo embed --release
```

### Build Only (no flash)
```bash
# DK (includes RTT by default)
cargo build --release

# XIAO development (with RTT)
cargo build --release --no-default-features --features board-xiao,rtt

# XIAO production (no RTT)
cargo build --release --no-default-features --features board-xiao
```

---

## Pulsar v1 (Signed OTA)

Pulsar v1 carries a Nordic Secure DFU bootloader, so it updates wirelessly and only accepts
firmware signed with the project's release key. Building the application is the same as any
other board:

```bash
# Production
cargo build --release --no-default-features --features board-pulsarv1

# With RTT (bring-up only — see the note below)
cargo build --release --no-default-features --features board-pulsarv1,rtt
```

**Putting a unit into update mode:** hold sync past 3.5s with the controller's **Start** held.
Three fast flashes confirm, and it reboots advertising as `PulsarDFU`. It refuses on a low
battery unless charging (`CHRG` on the VMU). The gesture does not clear your pairing.

> **No button or pin-reset entry on this board, and no UF2 volume.** `sdk_config.h` sets both
> `NRF_BL_DFU_ENTER_METHOD_BUTTON` and `NRF_BL_DFU_ENTER_METHOD_PINRESET` to `0`; entry is
> GPREGRET `0xB1` only, written by the firmware gesture. Double-tapping reset does nothing and
> no `XIAO-BOOT` drive appears — that is the design, not a fault. Practically: the gesture
> needs a controller attached (it checks Start), and an absent or invalid application
> auto-enters DFU at power-on, so a failed update recovers itself rather than bricking.

> **The web updater cannot talk to an Adafruit-bootloader board.** Chrome's Web Bluetooth
> blocklist permanently excludes the legacy DFU service UUID (`00001530-…`) by name, so the
> UF2 boards are unreachable from a browser no matter what. Nordic Secure DFU (`0xFE59`) is
> not blocklisted, which is why retail units carry that bootloader instead. XIAO and DK builds
> use UF2 or SWD.

**Browser requirements for the web route.** Web Bluetooth is not universal, and the common
failure is a page that loads fine and never offers a device:

| Browser | Status |
|---|---|
| Chrome / Edge / Opera, Windows or macOS | Works as shipped |
| **Brave** | **Disabled by default** — enable `Web Bluetooth API` in `brave://flags`, then relaunch. Brave gates it deliberately as a privacy decision |
| Chrome on Linux | Requires `chrome://flags/#enable-experimental-web-platform-features`, plus BlueZ 5.41+ |
| Firefox, Safari (incl. iOS/iPadOS) | Not implemented, no workaround in-browser |

Web Bluetooth also requires a secure context and a user gesture, so the page must be served
over HTTPS and the chooser has to be opened by a click.

**Signed packages are produced by the maintainer** and served from the update page. Because
the bootloader verifies a signature, a locally built binary will not install over the air —
use SWD for local work on a Pulsar v1, or a XIAO build for iteration.

> **RTT does not work on this board.** There is no debug probe on a retail unit, so `rtt`
> compiles but you cannot read it. The HID side channels exist for exactly this reason —
> `gauge-debug`, `connparam-debug`, `poll-period-debug`, and `maple-fail-debug` smuggle
> telemetry out through unused report bytes, readable with `scripts/hid_capture.py`. They are
> mutually exclusive; see `Cargo.toml` for the invocation of each.

**Owner builds.** Nothing here prevents you running your own firmware on hardware you own:
the signature check lives in the bootloader, and the bootloader can be replaced over SWD with
one carrying your own key. That route is yours to take — the release key only governs which
firmware the *official* update channel can install.

## Debugging

### RTT (Real-Time Transfer)

RTT logging is gated behind the `rtt` feature flag. The DK board always includes it. For XIAO, add `rtt` to the features list:

```bash
cargo embed --release --no-default-features --features board-xiao,rtt
```

`cargo embed` opens RTT automatically after flashing. To attach to an already-running device:
```bash
probe-rs attach --chip nRF52840_xxAA target/thumbv7em-none-eabihf/release/pulsar-dreamcast-ble
```

### Panic Logging

On panic, the firmware writes the panic message to flash (`0xF1000`) and resets. On the next boot (with RTT enabled), the stored panic is printed and cleared. This helps diagnose crashes without needing to reproduce them with a debugger attached.

### GDB
```bash
probe-rs gdb --chip nRF52840_xxAA target/thumbv7em-none-eabihf/release/pulsar-dreamcast-ble
```

---

## Recovery

### Chip Locked / Unresponsive
```bash
nrfjprog --recover
```

### Re-flash Everything (SWD)
```bash
nrfjprog --eraseall
nrfjprog --program s140_nrf52_7.3.0_softdevice.hex --verify
cargo embed --release
```

### Re-flash Everything (UF2)
Restore the bootloader first (see above), then double-tap reset and copy the `.uf2` file.

### Probe Not Found
- Unplug and replug USB
- Check `probe-rs list` for connected probes
- Kill stale processes: `ps aux | grep -iE 'jlink|probe-rs|nrf' | grep -v grep`

---

## Useful Commands

```bash
# Check connected probes
probe-rs list

# Device info
nrfjprog --deviceversion

# Read flash memory
nrfjprog --memrd 0x00027000 --n 16

# Soft reset
nrfjprog --reset

# Erase app only (preserves SoftDevice, bootloader, and stored data pages).
# Do NOT erase up to 0x100000: 0xF4000+ is the bootloader, 0xFE000 the MBR
# params page, 0xFF000 its settings page — wiping those needs a full reflash.
nrfjprog --erasepage 0x27000-0xF1000
```

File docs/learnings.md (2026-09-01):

# Maple Bus Implementation Learnings

Key lessons from implementing Maple Bus communication on the nRF52840 at 2Mbps. These apply broadly to any high-speed GPIO protocol on a microcontroller.

---

## 1. Bulk Sampling Beats Real-Time Edge Detection

At 2Mbps, each bit lasts 500ns. Trying to detect edges and make decisions within that window is fragile — any function call, branch mispredict, or interrupt can miss data.

**Solution:** Capture raw GPIO samples into a large static buffer as fast as possible, then decode offline. This separates "is the signal there?" from "can we decode it?" and makes debugging much easier.

Bulk sampling runs at the measured ~7.9 Msamples/s, giving ~4 samples per 500ns bit period — enough oversampling to recover edges for post-processing.

## 2. Every Microsecond Counts in the Hot Path

A single `rprintln!()` call costs ~15-20µs via RTT — that's 30-40 bits lost. The controller responds within ~100µs of a request, so any debug logging between TX and RX will miss the entire response.

**Rule:** Zero logging in the TX→RX→decode path. Log before TX and after decode, never in between.

## 3. Function Call Overhead Kills Timing

Returning from a `wait_for_start()` function and then calling `bulk_sample()` introduced enough delay to miss the first clock edges. Even a handful of nanoseconds matters when the controller starts transmitting immediately after the start pattern.

**Solution:** Combine detection and sampling in a single function. The moment the start pattern is detected, begin sampling inline — no function returns, no setup overhead.

## 4. Static Buffers, Not Stack Allocation

Allocating the sample buffer on the stack (`[u32; 24576]` = 24,576 u32 samples = 96 KiB) takes measurable time. By the time the stack frame is set up, the controller's response is already in progress.

**Solution:** Use `static mut` buffers — pre-allocated at link time, zero runtime cost.

## 5. Phase Alignment Is Critical

Maple Bus alternates which line is clock and which is data:
- Phase 1: A falls → sample B
- Phase 2: B falls → sample A

If the first detected edge is B falling instead of A falling, every subsequent bit is shifted by one position. The result looks almost right but every byte is wrong.

**Solution:** After detecting the start pattern, skip any B edges until the first A fall. This guarantees correct phase alignment.

## 6. Release Builds Are Mandatory

Embassy's `Flex::set_high()` / `set_low()` are `#[inline]` wrappers around single OUTSET/OUTCLR register writes. In a release build, these inline to ~1 instruction each. In a debug build, `#[inline]` is ignored — each pin toggle becomes 4+ nested function calls, destroying TX timing. The controller won't recognize the malformed request.

```bash
# Correct — TX timing works:
cargo embed --release --no-default-features --features board-xiao

# Broken — controller won't respond:
cargo embed --no-default-features --features board-xiao
```

This was the root cause of the XIAO board not working — the DK happened to always be built with `--release`.

## 7. Check Wiring with Initial State

Before any communication, read both pins as inputs:
```
Expected idle: A=1, B=0
A=0, B=1 → Wires are swapped
A=0, B=0 → Controller not powered or not connected
A=1, B=1 → Pull-up problem or pin short
```

## 8. Pull-Ups Are Non-Negotiable

Both SDCKA and SDCKB need external pull-ups to 3.3V. 10kΩ works reliably and saves a bit of current over 4.7kΩ. Without external pull-ups, floating lines cause false edge detection and unreliable communication. Internal pull-ups (~13kΩ) are too weak and vary with temperature.

## 9. Ground the Sense Pin

Dreamcast controllers won't respond at all unless the GND/Sense pin (green wire) is connected to ground. This catches people every time.

## 10. Check for Pin Shorts on Perfboard

Flux residue or solder bridges (especially under castellated-pad boards like the XIAO) can short pins to power rails. Symptoms:
- `Initial state A=1 B=1` (B should be 0)
- Board resets when grounding a data wire (shorted directly to 3.3V, not through pull-up)

**Diagnostic:** Short each data wire to GND one at a time. Board stays alive + pin reads LOW = correct (current through pull-up). Board resets = pin shorted to power rail.

## 11. Power Routing Matters

The XIAO's 3.3V regulator can't supply enough current for the boost converter + controller (~200mA+). Feeding the Pololu VIN from the 3.3V rail causes brownouts. The battery must feed the boost converter directly.

## 12. Input Pipeline: Signal, Not Channel

The controller state flows from Maple Bus poll → `Signal` → BLE notify task. Embassy's `Signal` is last-writer-wins (only holds one value), which matches the industry standard for gamepad HID — every major controller (Xbox, PlayStation, Switch Pro, BlueRetro) sends state snapshots, not event queues.

A `Channel` (FIFO queue) was considered but rejected: analog stick jitter fills the queue every poll, and the BLE task would process stale queued states, adding 32-64ms of latency for stick movements. Channels solve a problem that doesn't exist for gamepads.

**Optimizations applied (in order of impact):**

1. **Only signal on change** — reduces the window where a button press can be overwritten by identical idle-state polls. Analog jitter no longer constantly overwrites the signal.
2. **Wake BLE task immediately on state change** — use `select` between timer and signal instead of fixed 8ms sleep, so the BLE task reads new state within ~1ms instead of up to 8ms.

**Future option if needed:** Button edge accumulation — track a bitmask of buttons pressed since the last BLE read, OR it into the signaled state. This catches press+release within one poll cycle, but adds complexity and only helps when the BLE task is delayed past 16ms (rare with optimizations #1 and #2). The Maple Bus poll at ~60 Hz (~16-17 ms loop) already means sub-16ms taps are missed at the hardware level, matching original Dreamcast behavior.

## 13. Voltage-Based Battery Percentage Is Good Enough

A 10-point LiPo discharge curve lookup table with linear interpolation is the industry standard for embedded gamepads. Xbox controllers only report 4 levels. Meshtastic uses an 11-point table nearly identical to ours.

**Key findings from discharge testing (500mAh LiPo, FNB58 meter):**

- Linear voltage mapping is misleading — battery sat at "57%" for over an hour during the 3.7-3.9V plateau
- The protection circuit cuts off at ~3300mV under load, not 3.0V — the battery never reaches the theoretical minimum
- Voltage recovery after sleep or load removal causes readings to temporarily increase, confusing users

**Solutions applied:**
- Lookup table calibrated to measured cutoff (0% = 3300mV)
- 8x hardware oversampling (SAADC) for noise reduction
- Monotonic decrease constraint — percentage never goes up unless charging is detected

**What we didn't do (and why):**
- Fuel gauge IC (MAX17048) — adds hardware complexity, only +/-5% vs our +/-10-15%, not worth it without a custom PCB
- Rolling average — the monotonic decrease constraint handles the main noise source (voltage bounce) without the complexity
- Reading during radio idle — marginal benefit, the 8x oversampling handles transients

## 14. Flash-Based Panic Logging

`panic-reset` silently resets with no diagnostic information. Writing the panic message to a dedicated flash page before reset costs almost nothing (a few microseconds of NVMC writes) and provides critical debugging data on the next boot.

**Implementation notes:**
- Must use raw NVMC register writes — the SoftDevice async flash API is not available in a panic handler
- Use a fixed flash page well away from SoftDevice and application data (0xF1000; originally 0xFC000, moved 2026-08-04 below the bootloader)
- Always erase the page after reading to prevent stale data and limit flash wear
- nRF52840 flash is rated for ~10,000 erase cycles per page — not a concern

## 15. Poll/Connection-Interval Beat Makes Short Captures Lie

The poll cadence (~15 ms, device crystal) and the BLE connection interval
(~15 ms, host clock) are nominally equal, so their relative phase slides at
ppm-scale drift — and the doubled-interval fraction (a poll's notify missing
its connection event) swings with that phase. Measured on one binary, within
one connection, in 5 s windows over 180 s: **2.5% to 18.5%**, wandering on a
~30-60 s quasi-period (crystal drift is temperature-wandering, so the beat is
not a crisp frequency). The user-visible symptom is the issue #5 one: a 30 ms
gap at ~2.5 rot/s skips an octant.

**Consequences:**
- A 10 s capture samples one random slice of the beat and cannot compare
  builds — an afternoon of A/B ladder flashes (v228-v232, 2026-08-10) produced
  "differences" from 2.9% to 12.2% that were entirely this process. Validation
  captures need ≥120 s, and the number that matters is the windowed timeline,
  not one aggregate.
- The radio-quiet gate reduces collisions but has a recurring adverse-phase
  band it cannot dodge by skipping alone. Candidate fixes: re-phase the poll
  anchor when the skip rate runs hot, or detune the poll period off the
  connection interval so the adverse band sweeps through quickly instead of
  lingering.
- Confounders priced during the same session: back cover on ≈ +1.5-2.5 points
  (RF attenuation, and it is the shipping config), VMU docked ≈ +1.3 points
  (LCD animation traffic). The 1.3-4.0% "baseline band" printed by
  `hid_capture.py` predates all three effects and reads as cover-off,
  clean-phase luck.

---

## Quick Reference

| Problem | Symptom | Solution |
|---|---|---|
| Debug prints in hot path | Garbage data, missed bits | Remove all logging between TX and RX |
| Stack allocation delay | First edge missed | Use static buffer |
| Function return delay | First edge is B not A | Combine wait + sample in one function |
| Wrong phase start | Bytes shifted by 1 bit | Skip B edges until first A fall |
| Debug build | Controller never responds | Always use `--release` |
| Wires swapped | Initial state A=0, B=1 | Check Red→SDCKA, White→SDCKB |
| No pull-ups | False edges, unreliable reads | 10kΩ external pull-ups to 3.3V |
| Sense pin floating | Zero response from controller | Connect GND/Sense to ground |
| Pin short on perfboard | A=1, B=1 or board resets | Test each data wire to GND individually |

---

## Expected Working Output

```
Initial bus state (as inputs): A=1 B=0
TX: DeviceInfoRequest
RX: Frame=0x0500201C cmd=0x05 len=28
RX: OK!
Controller detected!
  Functions: 0x00000001
```

- **A=1, B=0** = correct idle state
- **cmd=0x05** = Device Info Response
- **len=28** = full 28-word payload (standard controller)
- **Functions: 0x00000001** = controller function code

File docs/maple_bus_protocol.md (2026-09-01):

# Maple Bus Protocol Reference

Consolidated from three sources:
- **[mc.pp.se]** http://mc.pp.se/dc/maplewire.html - Wire protocol details
- **[gmanmodz]** https://gmanmodz.com/2019/08/16/bit-banging-the-dreamcast-controller/ - Bit-banging implementation
- **[wiki]** https://dreamcast.wiki/Maple_bus - Complete protocol reference

---

## Physical Layer

### Pin Assignments

| Pin | Name | Color | Function |
|-----|---|---|---|
| 1 | SDCKA | Red | Clock/Data line A |
| 2 | +5V | Blue | Power |
| 3 | GND | Black | Ground (cable shield ties here) |
| 4 | Sense | Green | Tied to GND |
| 5 | SDCKB | White | Clock/Data line B |

Pinout per the canonical Maple-bus reference ([mc.pp.se](https://mc.pp.se/dc/controller.html)),
matching the KiCad symbol. See `pin_mapping.md`, which is authoritative for this table.

**Wire colours vary on third-party cables — meter your actual cable before trusting
them.** Pins 3 and 4 are both at ground potential either way, so a 5 V measurement
against either is valid; pins 1 and 5 are data lines and carry no power.

### Voltage Levels

| Source | Power | Signal Logic |
|---|---|---|
| [mc.pp.se] | +5V | +5V / 0V |
| [wiki] | 5V | 3.3V TTL |

**Note:** mc.pp.se describes 5V signaling, but wiki says 3.3V TTL. The Dreamcast itself uses 3.3V logic with 5V power. For nRF52840 (3.3V), this should be compatible.

### Idle State

**All sources agree:** Both SDCKA and SDCKB are pulled HIGH through weak pull-up resistors when idle.

- [mc.pp.se]: "When the bus is idle, both wires contain a high signal"
- [gmanmodz]: "Both data lines start at the high position"
- [wiki]: "Both lines on the Bus are pulled HIGH through weak pullup resistors"

---

## Timing

### Bit Timing

| Parameter | [mc.pp.se] | [wiki] | [gmanmodz] |
|---|---|---|---|
| Phase duration | 0.5µs | ~160ns (host), ~250ns (peripheral) | - |
| Bit period | 0.5µs (500ns) | - | - |
| Data rate | 2 Mbps | 2 Mbps (host), 0.5-1.3 Mbps (peripheral) | ~2 Mbps* |
| Edge transition (between lines) | - | ~125ns min | - |
| Edge transition (same line) | - | ~225ns min | - |

**Key insight from [wiki]:** Peripherals transmit slower than the host (~250ns/phase vs ~160ns/phase).

\* [gmanmodz] writes "1 MB/s", but the bus is 2 Mbps (500ns/bit, one bit per phase) — the source conflates megabits and megabytes. All rates here are normalized to Mbps.

### Response Timing

| Parameter | Value | Source |
|---|---|---|
| Inter-chunk delay | 110-130µs between 4-word blocks | [wiki] |
| Device polling rate | 50Hz (PAL) / 60Hz (NTSC) | [wiki] |

---

## Start Pattern (Sync Sequence)

All three sources describe the same pattern:

### Sequence (Host sending to peripheral)

```
Initial state: SDCKA=HIGH, SDCKB=HIGH (idle)

1. SDCKA → LOW (immediately)
2. SDCKB toggled 4 times (HIGH→LOW cycles) while SDCKA stays LOW
3. SDCKB → HIGH
4. SDCKA → HIGH
5. SDCKB → LOW

Final state: SDCKA=HIGH, SDCKB=LOW (ready for Phase 1)
```

### Timing Diagram

```
         ___                           _____________
SDCKA:      \__________...____________/

         _______   ___   ___   ___   ___________
SDCKB:          \_/   \_/   \_/   \_/           \____

         idle  | A low | 4x B toggle | A,B rise | B low
```

### Detection (Receiver)

- [mc.pp.se]: "Four consecutive down flanks on pin 5 [SDCKB]" signals incoming frame
- [gmanmodz]: Uses interrupt on falling edge to detect start

### Bit Interpretation

[mc.pp.se]: "Interpreted as normal data transfer cycles, the sync appears as the bit sequence 100001, but with all bits but the first sent in phase 2."

---

## End Pattern (Terminate Sequence)

### Sequence

From [wiki]:
```
1. SDCKA → HIGH
2. SDCKB → HIGH then LOW
3. SDCKA toggled 2 times
4. SDCKB → HIGH

Final state: SDCKA=HIGH, SDCKB=HIGH (idle)
```

From [mc.pp.se]:
```
Bit sequence "100" sent as: Phase 2, Phase 1, Phase 1
Detection: Two consecutive Phase 1 cycles signal transmission end
```

---

## Data Transmission

### Phase Alternation

The protocol alternates which line is clock and which is data:

| Phase | Clock Line | Data Line | Clock Action |
|---|---|---|---|
| 1 | SDCKA | SDCKB | A falls → sample B |
| 2 | SDCKB | SDCKA | B falls → sample A |

**Critical insight from [mc.pp.se]:**
> "a receiving circuit need not concern itself with phases at all; a negative flank on any of the pins will always mean a valid bit on the other pin."

### Phase 1 Detailed (A=clock, B=data)

From [mc.pp.se]:
```
Start:  A=HIGH, B=LOW
1. B takes data bit value (B may go HIGH or stay LOW)
2. A driven LOW (falling edge = clock signal, data is now valid)
3. B stabilizes briefly
4. B driven HIGH (prepares B to be clock in next phase)
End:    A=LOW, B=HIGH (ready for Phase 2)
```

### Phase 2 Detailed (B=clock, A=data)

```
Start:  A=LOW, B=HIGH
1. A takes data bit value
2. B driven LOW (falling edge = clock signal)
3. A stabilizes briefly
4. A driven HIGH (prepares A to be clock in next phase)
End:    A=HIGH, B=LOW (ready for Phase 1)
```

### Data Sampling Rule

**When you see a falling edge on either pin, sample the OTHER pin immediately.**

---

## Bit/Byte/Word Ordering

### Bit Order

- [mc.pp.se]: MSB first (opposite of RS232)
- Bits transmitted: b7, b6, b5, b4, b3, b2, b1, b0

### Byte Order in Words

- [mc.pp.se]: "byte order reversal" - LSB transmitted first
- [wiki]: "little-endian bytes, MSB first"

For a 32-bit word `0xAABBCCDD`:
```
Transmission order: DD, CC, BB, AA (LSB first)
Within each byte: MSB first (bit 7 → bit 0)
```

### CRC Byte

- Single byte, MSB first
- **NOT** subject to byte reversal (it's just one byte)

---

## Frame Structure

### Frame Word (First Word of Packet)

| Byte Position | Field | Description |
|---|---|---|
| Byte 0 (LSB, sent first) | Length | Payload word count (0-255) |
| Byte 1 | Sender | Source address |
| Byte 2 | Recipient | Destination address |
| Byte 3 (MSB, sent last) | Command | Command code |

As 32-bit value: `(command << 24) | (recipient << 16) | (sender << 8) | length`

### Complete Packet Structure

```
[Start Pattern] [Frame Word] [Payload Words 0..N-1] [CRC Byte] [End Pattern]
```

### CRC Calculation

Bytewise XOR of all bytes in the packet (frame word + all payload words):
```
crc = 0
for each word in packet:
    crc ^= (word >> 0) & 0xFF
    crc ^= (word >> 8) & 0xFF
    crc ^= (word >> 16) & 0xFF
    crc ^= (word >> 24) & 0xFF
```

---

## Addressing

### Port/Device Addresses

| Player | Host | Main Peripheral | Sub-1 | Sub-2 | Sub-3 | Sub-4 | Sub-5 |
|---|---|---|---|---|---|---|---|
| 1 | 0x00 | 0x20 | 0x01 | 0x02 | 0x04 | 0x08 | 0x10 |
| 2 | 0x40 | 0x60 | 0x41 | 0x42 | 0x44 | 0x48 | 0x50 |
| 3 | 0x80 | 0xA0 | 0x81 | 0x82 | 0x84 | 0x88 | 0x90 |
| 4 | 0xC0 | 0xE0 | 0xC1 | 0xC2 | 0xC4 | 0xC8 | 0xD0 |

For our adapter (Player 1):
- Host (us): `0x00`
- Main controller: `0x20`
- VMU in slot 1: `0x01`
- VMU in slot 2: `0x02`

---

## Command Codes

### Common Commands

| Code | Name | Direction | Payload | Response |
|---|---|---|---|---|
| 0x01 | Device Info Request | Host→Device | 0 words | 0x05 |
| 0x05 | Device Info Response | Device→Host | 28 words | - |
| 0x09 | Get Condition | Host→Device | 1 word (function) | 0x08 |
| 0x08 | Data Transfer (Condition) | Device→Host | 3+ words | - |

### Device Info Request (0x01)

```
Frame: cmd=0x01, recipient=0x20, sender=0x00, length=0
Payload: none
```

### Device Info Response (0x05)

```
Frame: cmd=0x05, recipient=0x00, sender=0x20, length=28
Payload:
  Word 0: Function codes bitmask
  Word 1-3: Function definitions
  Word 4: Region code, direction, description start
  Words 5-27: Description, producer info, power consumption
```

### Get Condition (0x09)

```
Frame: cmd=0x09, recipient=0x20, sender=0x00, length=1
Payload:
  Word 0: Function code (0x00000001 for controller)
```

### Condition Response (0x08)

```
Frame: cmd=0x08, recipient=0x00, sender=0x20, length=3
Payload:
  Word 0: Function code
  Word 1: Buttons (active LOW - pressed = 0)
  Word 2: Triggers and analog stick
```

---

## Function Codes

| Code | Function |
|---|---|
| 0x00000001 | Controller |
| 0x00000002 | Storage (VMU) |
| 0x00000004 | Screen (VMU LCD) |
| 0x00000008 | Timer (VMU clock) |
| 0x00000100 | Vibration (Rumble Pack) |

---

## Special Sequences

### Reset Sequence

```
SDCKA → LOW
SDCKB toggled 14 times
SDCKA → HIGH
```

### Light Gun Detection

```
SDCKA → LOW
SDCKB toggled 8 times
SDCKA → HIGH
```

---

## Our Implementation (nRF52840 at 64MHz)

### Timing Budget

| Parameter | Cycles | Time |
|---|---|---|
| 1 bit | 64 | 1µs |
| Half bit (one phase) | 32 | 0.5µs |
| Start pattern | ~256 | ~4µs |
| Controller response delay | 4000-6400 | 60-100µs |
| Data stable window | ~15 | ~240ns |

Bulk sampling runs at the measured ~7.9 Msamples/s, giving ~4 samples per 500ns bit — enough resolution for reliable post-processing.

### Approach: Bulk Sampling

Real-time edge detection at 2Mbps is fragile — any function call, branch, or interrupt can miss the ~240ns stable window. Instead, we capture raw GPIO samples into a 96KB static buffer as fast as possible, then decode offline:

The snippet below is illustrative pseudocode; the production capture loop is hand-written inline asm with pinned registers and `.p2align 2` so the cycle count (and thus the sample rate) is fixed across builds.

```rust
// Tight sampling loop — no decisions, just capture
for i in 0..24576 {
    samples[i] = p0_in.read().bits();
}
// Decode later: find edges, extract bits, verify CRC
```

This is the same approach used by raphnet's AVR-based Dreamcast adapter. It separates signal capture from decode logic, making both more reliable and easier to debug.

### Key Implementation Details

- **Combined wait + sample** — Start pattern detection and sampling happen in one function. No function return delay between detecting the trigger and beginning capture.
- **Phase-aligned decoding** — Skip B edges until the first A fall to guarantee correct phase. Without this, every byte is shifted by 1 bit.
- **40-edge analysis window** — `find_first_edges()` analyzes 40 edges for late-start detection. Reducing to 10 causes decode failures.
- **`--release` builds required** — Embassy GPIO calls must inline for correct TX timing. Debug builds break communication entirely.
- **Static buffer** — `static mut [u32; 24576]` avoids stack allocation delay.

### Expected Waveform

For a Device Info Response from the controller:
- Response delay: 50-160µs after request ends
- Start pattern: ~4µs (A LOW, B toggles 4x, A HIGH, B LOW)
- Data: 29 words × 32 bits × 500ns/bit = ~464µs
- Inter-chunk gaps: 110-130µs between 4-word blocks
- Total response: ~500-600µs

### Controller Response Variance

| Controller Type | Response Delay |
|---|---|
| Official Sega | ~56 µs |
| Third-party | up to 159 µs |

---

## Community Implementations

Other Maple Bus implementations that informed this project:

- **[raphnet](https://www.raphnet.net/programmation/dreamcast_usb/index_en.php)** (AVR) — Pioneered the bulk sampling approach. Found that data is stable for only ~240ns (not 250ns as documented). 16MHz minimum for reliable reads.
- **[ismell/maplebus](https://github.com/ismell/maplebus)** (FPGA) — Controller must respond within 1ms. USB 2.0 latency makes PC-based solutions difficult; dedicated hardware is more reliable.
- **[Gmanmodz](https://github.com/Gmanmodz/Dreamcast-Controller-Emulator)** (PIC32) — Emulates a controller TO the Dreamcast (opposite direction). PIC32 at 200MHz gives ~200 instructions per bit.

See [learnings.md](learnings.md) for detailed implementation lessons from this project.

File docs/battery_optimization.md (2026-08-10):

# Battery & Power Optimization

Power management strategy for the XIAO nRF52840 Dreamcast BLE adapter running on a single-cell LiPo (tested with 500mAh, recommended 1000mAh).

> **Scope: every figure on this page was measured on a XIAO nRF52840 build.** Retail
> Pulsar V1 hardware carries a different power topology — a separate always-on regulator
> and an IP5306 fuel gauge in place of the XIAO's voltage-curve estimate — so its standby
> figures are **not** the ones below and are characterized separately.

---

## Power Budget

| State | Current Draw | Source | Notes |
|---|---|---|---|
| Active gaming | ~57-67 mA | Measured (FNB58) | Boost converter + controller + BLE radio |
| BLE advertising (slow) | ~0.5-2 mA | Estimated | 500ms interval, boost off |
| System Off | ~5-8 µA | Datasheet | QSPI flash in DPD, pins disconnected |

### Measured Battery Life (500mAh LiPo)

Tested with FNB58 USB power meter, active BLE connection with occasional controller input:

- **Idle connected draw:** ~57 mA
- **Active input draw:** ~67 mA
- **Sleep drain:** ~2% overnight, at the resolution limit of the gauge — consistent with
  self-discharge, but the measurement is not precise enough to separate the two.

Measured draw figures yield ~7-8 hours of active gaming on 500mAh, scaling to ~14-16 hours on 1000mAh.

### Estimated Battery Life by Capacity

| Battery | Active Gaming | Sleep Standby |
|---|---|---|
| 500 mAh | ~7-8 hours | weeks+ (calculated, not measured) |
| 1000 mAh | ~14-16 hours (estimated) | weeks+ (calculated, not measured) |

**On the standby column:** active-gaming hours are measured; standby is *arithmetic* from
the ~5-8 µA System Off datasheet figure, which implies far longer than any test has run.
Overnight testing cannot distinguish a µA-class sleep current from self-discharge, so
treat standby as a lower bound on a correctly-configured board, not a verified result.

Note: The LiPo discharge curve is nonlinear. The battery spends a long time in the 3.7-3.9V plateau then drops quickly below 3.5V. Actual runtime may vary with controller usage intensity.

---

## Battery Percentage Estimation

Voltage-based percentage using a 10-point LiPo discharge curve lookup table with linear interpolation between entries. This is the industry standard approach for embedded devices — Xbox controllers only report 4 discrete levels, and projects like Meshtastic use similar tables.

### Lookup Table

| Voltage | Percentage |
|---|---|
| 4100 mV | 100% |
| 4000 mV | 80% |
| 3900 mV | 60% |
| 3800 mV | 40% |
| 3700 mV | 30% |
| 3600 mV | 20% |
| 3500 mV | 10% |
| 3400 mV | 5% |
| 3300 mV | 0% |

- **100% = 4100mV** — the BQ25101 charger often terminates before reaching 4200mV. Reporting 100% at 4.1V matches user expectations (same approach as phones/laptops)
- **0% = 3300mV** — the battery protection circuit shuts down at this voltage under load (measured empirically: device dies at ~3.3V)
- **8x SAADC oversampling** — hardware-averaged ADC reads for noise reduction
- **Monotonic decrease** — reported percentage never increases unless USB charging is detected, eliminating confusing voltage-recovery bounces after sleep or load changes
- **60-second read interval** — uses `Instant` comparison for drift-free timing

### Accuracy

Realistic accuracy is +/-10-15% in the flat middle region (3.7-3.9V), better at extremes. This is consistent with other voltage-based approaches and adequate for a battery indicator. A fuel gauge IC (e.g., MAX17048, around $2.80) would improve to +/-5% but only makes sense on a custom PCB.

---

## Optimizations Implemented

### 1. Boost Gating on BLE Connection (saves ~45 mA idle)

The 5V boost converter + Dreamcast controller draws ~45 mA and serves no purpose when there's no BLE host connected. The boot flow now:

1. Boot → BLE advertise (boost OFF, no controller polling)
2. BLE connects → enable boost → detect controller → start polling
3. BLE disconnects → disable boost → stop polling → advertise again
4. Timeout → System Off

### 2. QSPI Flash Deep Power Down (saves ~2-5 mA in all states)

The XIAO's P25Q16H QSPI flash draws several mA in standby. We don't use it. At startup, a GPIO bit-bang SPI sequence sends the DPD command (0xB9), then disconnects the QSPI pins. CS (P0.25) stays driven HIGH to prevent accidental wake from bus noise.

This was the root cause of unexpectedly high System Off current (milliamps instead of microamps).

### 3. REG1 DCDC Enable (free efficiency gain)

The XIAO has the inductor for REG1 DCDC (confirmed via Zephyr devicetree). Enabling it (`config.dcdc.reg1 = true`) saves ~2-3 mA during radio TX/RX. REG0 is NOT enabled (VDDH tied to VDD, no inductor).

### 4. Pin Disconnect in Sleep States

GPIO state survives System Off on the nRF52840. Every unused pin is explicitly disconnected (input, no pull, Hi-Z) before entering System Off to prevent current leakage. Eight pins are disconnected; three are kept driven (QSPI CS HIGH, boost SHDN LOW, charge ISET LOW).

During BLE advertising (boost off), Maple Bus pins are also disconnected via `MapleBus::set_low_power()`. The external 10kΩ pull-ups hold both lines at 3.3V with zero current.

### 5. HighDrive Mode for TX

`OutputDrive::HighDrive` gives ~121ns rise time vs ~363ns standard drive. No power cost — purely signal quality improvement that enables reliable communication and potentially allows higher-resistance pull-ups in the future.

### 6. USB VBUS Detection

When USB power is present, the controller runs directly from USB 5V via Schottky diode OR circuit (2x 1N5817). The boost converter stays off and the battery charges at 100mA with nothing drawing from it. Tethered play is effectively free.

### 7. Tiered Advertising

| Phase | Interval | Duration | Purpose |
|---|---|---|---|
| Fast reconnect | 20 ms | 5 seconds | Instant reconnect to bonded host |
| Slow reconnect | 500 ms | 55 seconds | Low-power reconnect window |
| Sync mode | 20 ms | 60 seconds | Active pairing (user-initiated) |
| Timeout | — | — | System Off after all phases expire |

### 8. Controller Detection Timeout

If BLE connects but no controller is found within 60 seconds, the device enters System Off. This prevents the overnight drain scenario where a host auto-reconnects via BLE with no controller plugged in, leaving the boost converter running indefinitely.

### 9. Inactivity Sleep

After 10 minutes with no BLE connection (controller disconnected, host gone), the device enters System Off. Wake via sync button press (GPIO SENSE).

### 10. RTT Feature Gate (saves flash size + minor power)

RTT debug logging is gated behind an `rtt` Cargo feature. DK builds always include it. XIAO production builds omit it — all `log!()` calls compile to nothing, reducing binary size and eliminating string formatting overhead. Development builds opt in with `--features board-xiao,rtt`.

### 11. Flash-Based Panic Logging

On panic, the firmware writes the panic message to a dedicated flash page (`0xF1000`) using raw NVMC register writes (no SoftDevice dependency), then resets. On the next boot with RTT enabled, the stored panic is printed and the page is cleared. This replaces the silent `panic-reset` behavior with something debuggable.

---

## Hardware: USB 5V Passthrough

Two 1N5817 Schottky diodes in an OR configuration route either USB VBUS or boost output to the controller 5V rail. When USB is present, the higher voltage wins (~4.7V after diode drop) and the boost shuts down. Firmware detects USB via the nRF52840 `POWER.USBREGSTATUS` register.

---

## Commercial Comparison

| Controller | Battery | Life | Avg Draw |
|---|---|---|---|
| Xbox One S | 2x AA (~2400 mAh) | 40 hr | ~60 mA |
| DualSense | 1560 mAh | 6-12 hr | ~100 mA |
| Switch Pro | 1300 mAh | 40 hr | ~32 mA |
| 8BitDo Pro 2 | 1000 mAh | 20 hr | ~50 mA |
| **This project** | **500 mAh** | **~7-8 hr** | **~60 mA** |
| **This project** | **1000 mAh** | **~14-16 hr** | **~60 mA** |

Our draw is dominated by the 5V boost converter + Dreamcast controller (~45 mA). The nRF52840 + BLE radio is only ~15 mA of the total.

---

## Possible Next Steps

- **Slave latency** — Setting BLE slave_latency to 2-4 could save ~200-300 µA during idle connected periods. Deferred due to BLE host-compatibility risk (e.g. with the iBlueControlMod Dreamcast BLE receiver adapter). Only effective if combined with skipping notifications when state is unchanged, which may break Xbox HID compatibility.
- **Dedicated PCB** — Eliminates perfboard losses and enables SMD components. Validated part choices (corrected from earlier notes):
  - **Boost: TPS61099DRVR** (TI TPS61099x family, WSON-6/DRV adjustable boost configured for 5.0V, 300mA class, ~1µA Iq, ~90% eff). NOTE: there is no real orderable "TPS61099x50" PN; the TPS61099x suffix matters. TI's fixed 5.0V member is TPS610997, but the datasheet orderable list shows that member as DSBGA/YFF, not WSON/DRV. Use TPS61099DRVR for the WSON package and set 5.0V with the feedback divider from TI's 5V example (~1MΩ VOUT-to-FB, 249kΩ FB-to-GND). **Critical:** the firmware's ~45mA boost-gating saving depends on true output disconnect, so the selected SMD boost must have verified shutdown disconnect behavior or the carrier must add a load switch (high-side P-FET or load-switch IC, e.g. TPS22919) on the 5V rail driven by the enable line. A load switch remains useful for controlled slew, output discharge, and protection even if the boost has true shutdown.
  - **OR diodes: power Schottky (SS14, 1A, JLC Basic — or low-Vf PMEG2010), NOT BAT54.** BAT54 is a small-signal Schottky (Vf ≈ 0.8V @ 100mA); at the ~50mA rail load it drops *more* than the 1N5817 it would replace. Earlier "~0.23V" figure only holds at low current.
- **Fuel gauge IC** — MAX17048 (Analog/Maxim, I2C, DFN-2x2, JLCPCB `C2682616`, ~$2.80) for +/-5% battery accuracy vs current +/-10-15%. Only practical on a custom PCB.
- **TX power reduction** — Lowering BLE TX from 0dBm to -4dBm would save ~1mA with no perceptible range impact at gamepad distances. Deferred pending range testing through plastic enclosure.

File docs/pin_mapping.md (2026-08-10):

# Pin Mapping

## XIAO nRF52840 (Primary Build)

| Function | Pin | Notes |
|---|-----|---|
| SDCKA (Red) | P0.05 (D5) | Maple Bus clock/data A |
| SDCKB (White) | P0.03 (D1) | Maple Bus clock/data B |
| Sync Button | P1.15 (D10) | Pairing, name toggle, wake from sleep |
| Boost SHDN | P0.28 (D2) | 5V boost converter enable |
| Battery ADC | P0.31 (AIN7) | Via P0.14 enable gate |
| RGB LED | P0.26/P0.30/P0.06 | R/G/B, active low |

Both data lines need 10kΩ pull-up resistors to 3.3V. The controller is powered at 5V — signals are 3.3V TTL.

## Pulsar V1 (MapleLink carrier — XIAO nRF52840)

The `board-pulsarv1` target. Same XIAO module, different carrier: SDCKA moved to **D0**, power is
the IP5306 over I²C (no discrete boost / charger / ADC-divider), status is a 5× WS2812 bar, plus a
rumble motor. Pins reconstructed from the board netlist.

| Function | Pin | Notes |
|---|-----|---|
| SDCKA (Red) | P0.02 (D0) | Maple Bus clock/data A — **moved from D5** |
| SDCKB (White) | P0.03 (D1) | Maple Bus clock/data B |
| Sync Button | P1.15 (D10) | Pairing, wake from sleep |
| I²C SDA | P0.04 (D4) | IP5306 (charge / boost / gauge) |
| I²C SCL | P0.05 (D5) | IP5306 |
| IP5306 INT | P1.11 (D6) | Charge-event IRQ (unused — battery is polled) |
| WS2812 data | P0.28 (D2) | 5-LED status bar (PWM2 — PWM0 is Maple TX) |
| Rumble EN | P0.29 (D3) | → R5 → Q1 → ERM motor (PWM1) |
| Status RGB | P0.26/P0.30/P0.06 | Onboard; blue (P0.06) is the sync LED |

Both Maple lines need 10 kΩ pull-ups; the I²C lines have 5.1 kΩ pull-ups (R1/R2). Power (charge,
5 V boost, coarse 25/50/75/100 % fuel gauge) is all over I²C — there are **no** boost-SHDN /
ADC-divider / BQ25101-STAT pins as on the discrete carrier.

## nRF52840 DK (Development)

| Function | Pin | Notes |
|---|-----|---|
| SDCKA (Red) | P0.05 | Maple Bus clock/data A |
| SDCKB (White) | P0.06 | Maple Bus clock/data B |
| Sync Button | P0.25 | Button 4, active low |
| Sync LED | P0.13 | LED1 |
| Status LEDs | P0.14-P0.16 | LED2-LED4 |

Same pull-up requirement. The DK needs an external 5V supply for the controller (the DK only outputs 3.3V).

## Dreamcast Controller Cable

The Dreamcast controller cable has 5 pins:

| Pin | Color | Function |
|-----|---|---|
| 1 | Red | SDCKA (data/clock A) → nRF P0.05 |
| 2 | Blue | +5V power |
| 3 | Black | GND (cable shield ties here) |
| 4 | Green | Sense — tied to GND |
| 5 | White | SDCKB (data/clock B) → nRF P0.03 |

Pinout per the canonical Maple-bus reference ([mc.pp.se](https://mc.pp.se/dc/controller.html));
matches the KiCad symbol. The Sense line (pin 4) is tied to GND. **Wire colors vary on
third-party cables — meter your actual cable before trusting the colors.**

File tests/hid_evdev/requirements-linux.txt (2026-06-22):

# Extra deps for the UHID/evdev end-to-end test (test_evdev_mapping.py).
# Linux only — needs /dev/uhid and the libevdev C library. Installed in CI.
-r requirements.txt
libevdev>=0.5

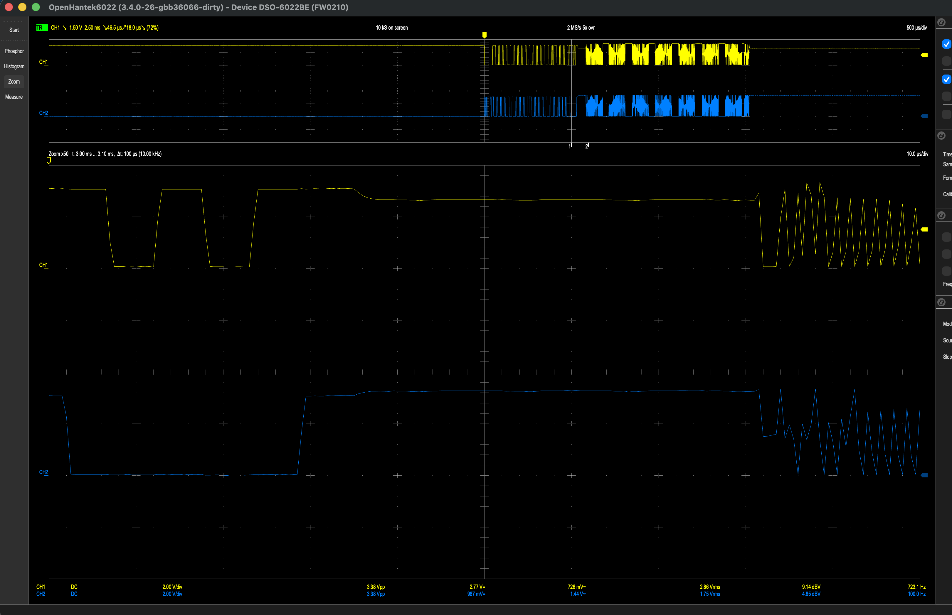
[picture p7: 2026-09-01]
docs/signal_references/start_pattern_and_response_overview.png

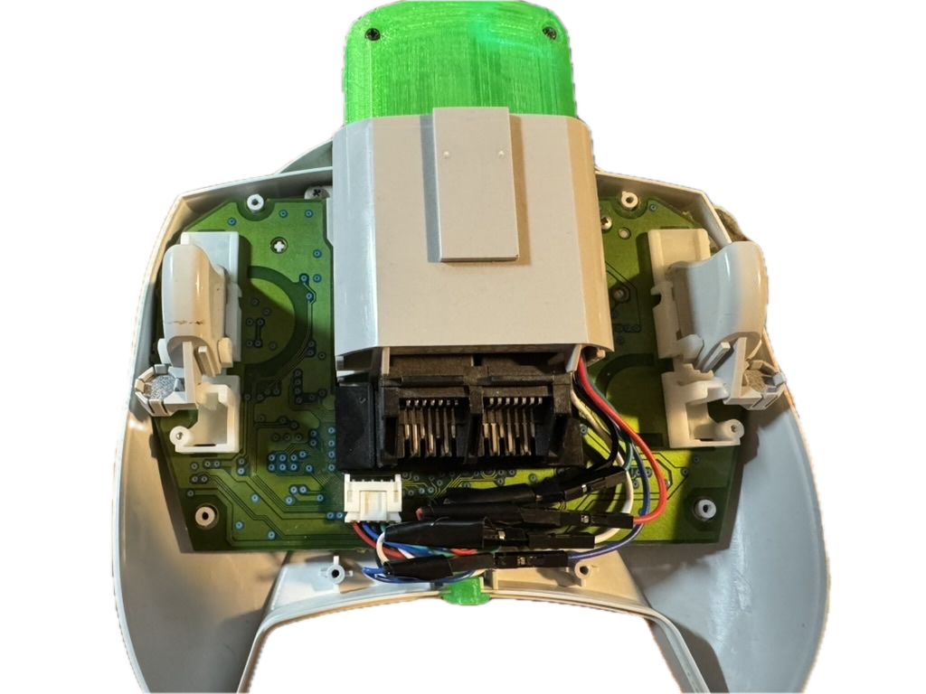
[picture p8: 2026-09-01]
docs/images/back_fit.png

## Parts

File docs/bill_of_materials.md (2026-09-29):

# Bill of Materials

The firmware supports three boards. Two of them you can build yourself and this document
lists what to buy; the third is the designed carrier, described here so you can understand
how it works and what it changes.

| Board | Build it yourself? | Section |
|---|---|---|
| **XIAO** | Yes — the primary DIY build | [XIAO Build](#xiao-build-primary) |
| **DK** | Yes — bench/development only | [DK Build](#dk-build-development) |
| **Pulsar v1** | No — the designed carrier | [Pulsar v1](#pulsar-v1-designed-carrier) |

## XIAO Build (Primary)

| Component | Quantity | Notes | Link |
|---|---|---|---|
| Seeed XIAO nRF52840 | 1 | Non-Sense version works | [Seeed Studio](https://www.seeedstudio.com/Seeed-XIAO-BLE-nRF52840-p-5201.html) |
| Dreamcast controller | 1 | Only tested with OEM controller | |
| Pololu U1V11F5 5V boost | 1 | Has SHDN pin for power gating | [Pololu](https://www.pololu.com/product/2562) |
| 1N5817 Schottky diodes | 2 | USB/boost OR circuit for 5V rail | [DigiKey](https://www.digikey.com/en/products/detail/diodes-incorporated/1N5817-T/22052) |
| 10kΩ resistors | 2 | Pull-ups for SDCKA and SDCKB (4.7kΩ also works) | |
| LiPo battery (1000mAh) | 1 | 3.7V, JST PH 2.0mm, ~8 hr runtime | [DigiKey](https://www.digikey.com/en/products/filter/battery-packs/89) |
| Perfboard | 1 | Used: Adafruit Perma-Proto quarter-size | [Adafruit](https://www.adafruit.com/product/589) |
| Wire | — | 30 AWG or similar | |
| Dreamcast controller cable | 1 | For tapping Maple Bus lines | |

## Programming / Debug (Optional)

The XIAO can be flashed via USB using the built-in UF2 bootloader — no debug probe needed. See [flash commands](flash-commands.md) for the UF2 workflow.

The hardware below is only needed for RTT debug logging or if you need to restore the bootloader:

| Component | Quantity | Notes | Link |
|---|---|---|---|
| nRF52840 DK | 1 | Used as J-Link programmer | [Nordic](https://www.nordicsemi.com/Products/Development-hardware/nrf52840-dk) |
| SWD breakout board | 1 | 2x5 1.27mm to breadboard-friendly pins | [Adafruit](https://www.adafruit.com/product/2743) |
| SWD cable (10-pin 1.27mm) | 1 | 150mm, connects DK to breakout | [Adafruit](https://www.adafruit.com/product/1675) |

## DK Build (Development)

| Component | Quantity | Notes | Link |
|---|---|---|---|
| nRF52840 DK | 1 | Built-in J-Link, no extra programmer needed | [Nordic](https://www.nordicsemi.com/Products/Development-hardware/nrf52840-dk) |
| Dreamcast controller | 1 | | |
| 10kΩ resistors | 2 | Pull-ups for SDCKA and SDCKB (4.7kΩ also works) | |
| Jumper wires | 4+ | 5V, GND, SDCKA, SDCKB | |
| 5V power supply | 1 | For controller (DK only outputs 3.3V) | |

## Pulsar v1 (Designed Carrier)

Pulsar v1 is a purpose-built carrier PCB with a **Seeed XIAO nRF52840 mounted on it** — the
same module as the DIY build, so both run identical silicon. The carrier replaces the
hand-wired power section with integrated parts and adds two things the DIY build has no room
for. It is described here to explain the design; the fabrication package is not published, so
this is a reference rather than a shopping list.

| Function | Part | What it replaces / adds vs. the DIY build |
|---|---|---|
| MCU | Seeed XIAO nRF52840 | Same module, socketed onto the carrier instead of perfboard |
| Charge, boost, gauge | IP5306 PMIC | Replaces the Pololu boost + BQ25101 charger + ADC divider with one part. Provides the 5 V controller rail and a four-level fuel gauge over I²C |
| Status and battery | 5× WS2812 chain | Replaces the single onboard RGB. LED 0 is status, LEDs 1–4 are the battery gauge |
| Haptics | ERM motor via transistor | New — the DIY build has no rumble |
| Controller | JST PH 2.0 mm, 5-pin | Maple cable: SDCKA, SDCKB, 5 V, ground |
| Battery | JST PH 2.0 mm, 2-pin | LiPo cell. PH rather than a smaller series because charge and boost currents exceed the 1 A rating of the finer pitches |
| Rumble motor | JST PH 2.0 mm, 2-pin | Motor lead, with a flyback diode |

What this changes in practice, versus the XIAO build: a four-level gauge instead of a
continuous voltage estimate, a battery bar instead of a status-only LED, working rumble, and
wireless firmware updates instead of USB drag-and-drop. Everything about how it plays is the
same. Pin assignments for all three boards are in [pin mapping](pin_mapping.md).

## Tools & Supplies

| Item | Notes |
|---|---|
| Soldering iron + solder | For perfboard assembly and wire connections |
| Wire strippers | For 30 AWG wire |
| Hi-temp masking tape (Kapton) | Useful for insulating connections and holding parts during assembly |
| Multimeter | For verifying connections and checking voltages |
| Heat shrink tubing | For insulating solder joints on the controller cable |

## Optional

| Component | Notes | Link |
|---|---|---|
| VMU enclosure (3D printed) | See print tips in hardware/enclosure/ | [hardware/enclosure/README.md](../hardware/enclosure/README.md) |

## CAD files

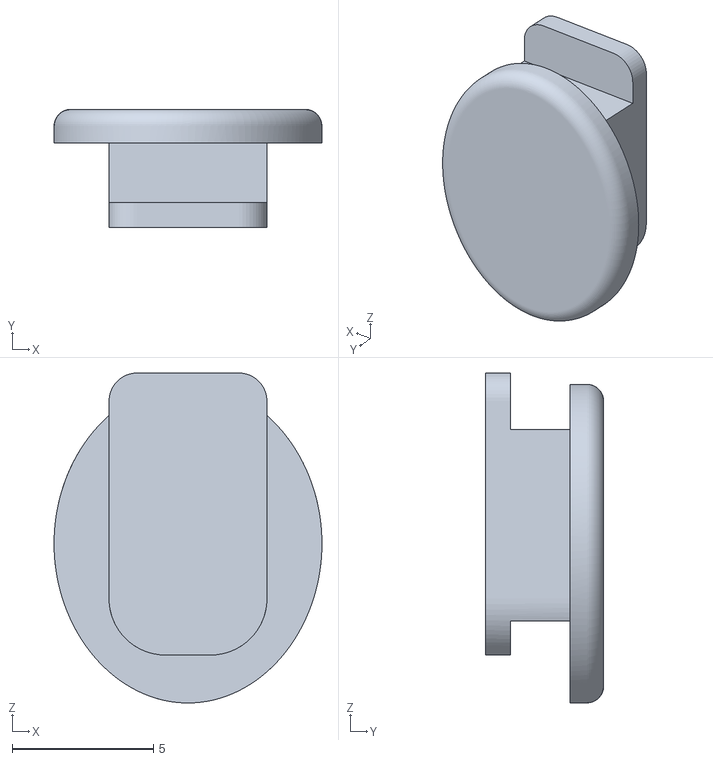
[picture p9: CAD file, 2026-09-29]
hardware/enclosure/cable_hole_plug.stl
9.50 x 4.20 x 11.7

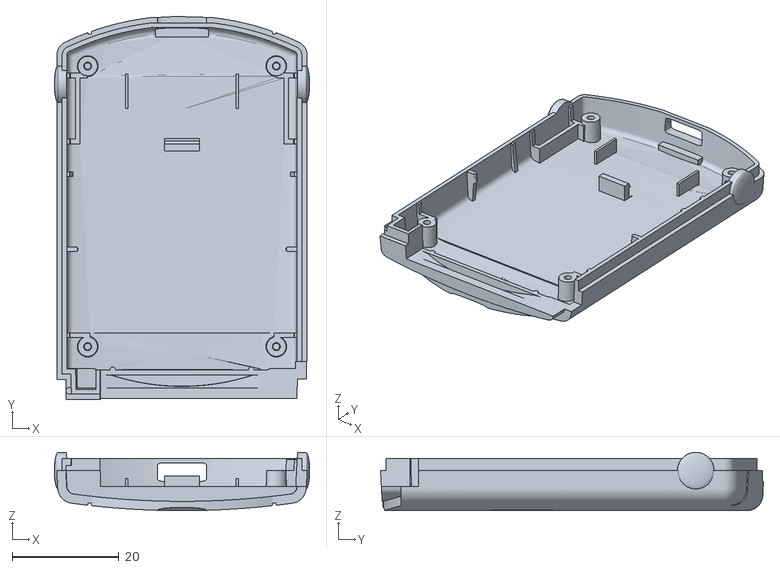
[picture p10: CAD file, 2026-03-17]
hardware/enclosure/Edited_VMU_stls/dreamcast_vmu_back_cutout.stl
47.9 x 71.9 x 11.0

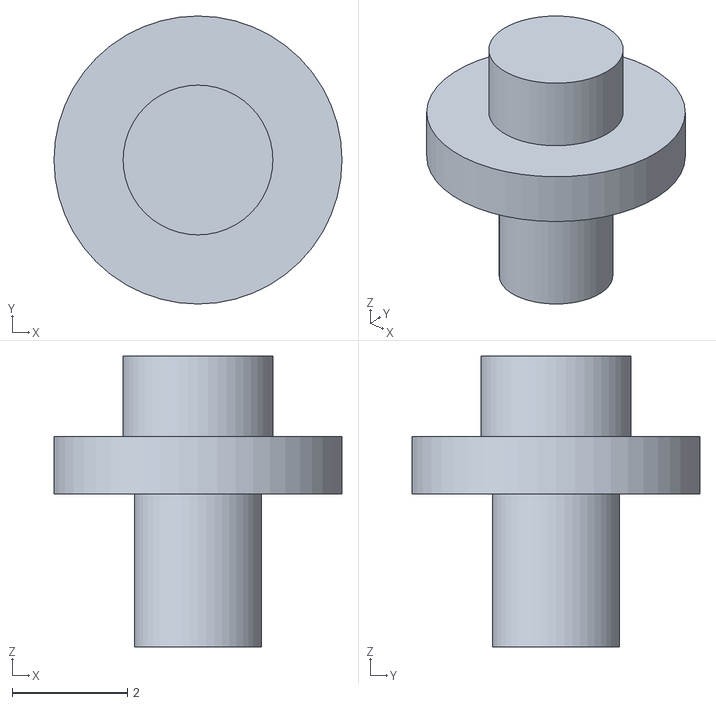
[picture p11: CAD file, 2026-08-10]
hardware/enclosure/Edited_VMU_stls/PulsarFit_703035/pulsar_vmu_button_plunger.stl
5.00 x 5.00 x 5.05

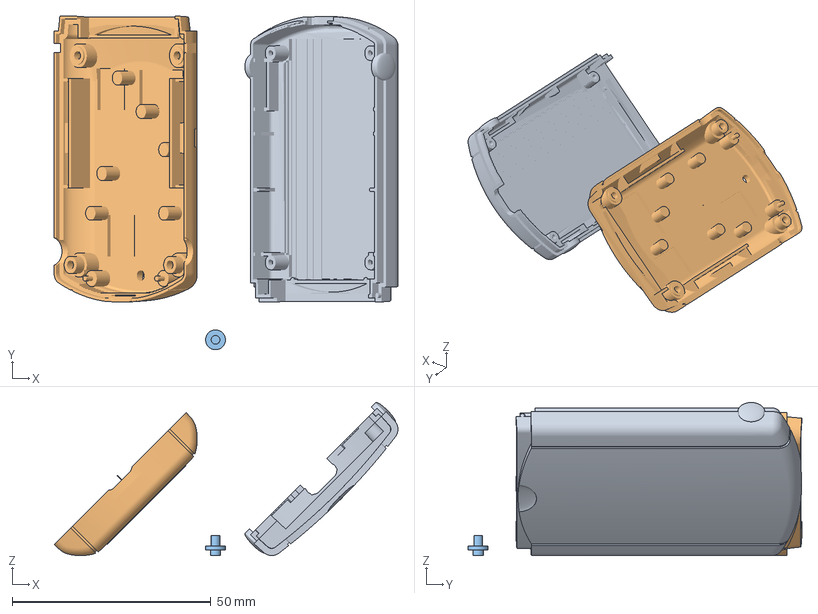
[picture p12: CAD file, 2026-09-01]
hardware/enclosure/Edited_VMU_stls/PulsarFit_bigcell/pulsar_bigcell.3mf
86.5 x 83.9 x 38.5 mm
pulsar_vmu_front_bigcell.stl
pulsar_vmu_rear.stl
pulsar_vmu_button_plunger.stl

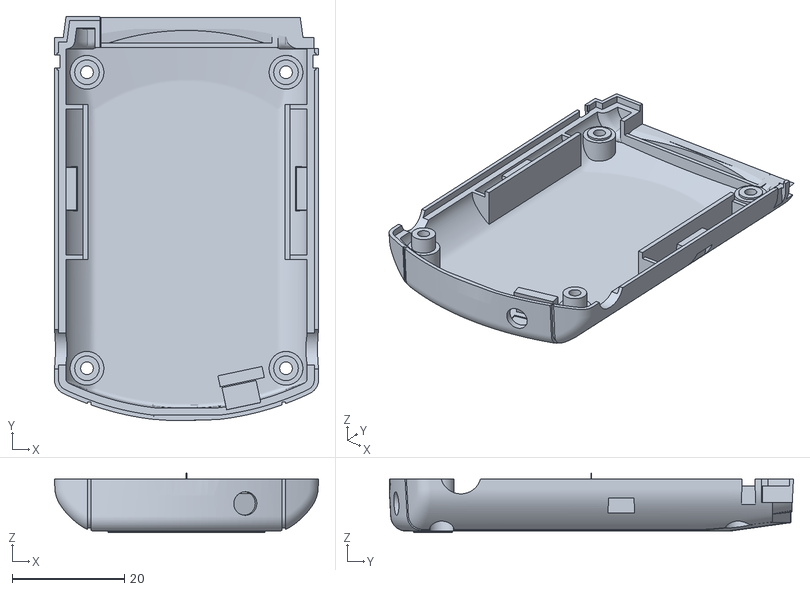
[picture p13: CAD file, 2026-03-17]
hardware/enclosure/Edited_VMU_stls/dreamcast_vmu_back_w_cutout.stl
47.0 x 71.9 x 10.5

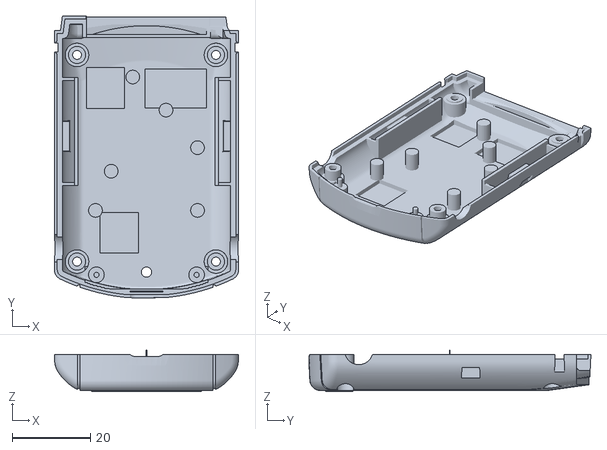
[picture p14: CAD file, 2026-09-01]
hardware/enclosure/Edited_VMU_stls/PulsarFit_bigcell_cable_relief/pulsar_vmu_rear_cable_relief.stl
47.0 x 71.9 x 10.5

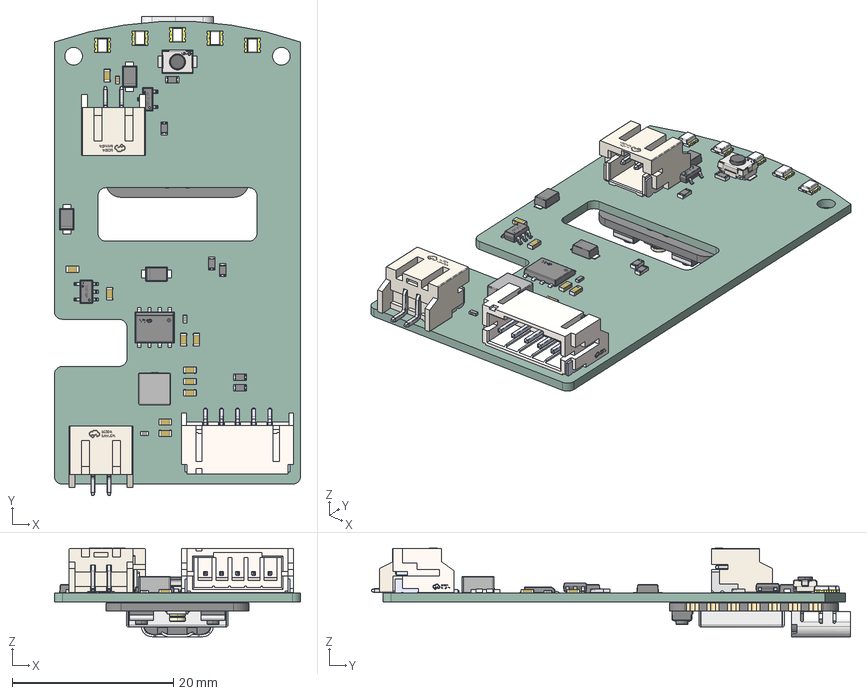
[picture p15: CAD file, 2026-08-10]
hardware/enclosure/Pulsar.step
30.6 x 59.5 x 11.0 mm
C0603_L1.6-W0.8-H0.8 x 10
R0603 x 6
SOD-123FL_L2.8-W1.8-H1.1-LS3.6 x 3
CONN-SMD_P2.00_S2B-PH-SM4-TB-LF-SN x 2
LED-SMD_4P-L2.0-W1.8_XL-0807RGBC-WS2812B x 5
SW-SMD_L3.9-W2.9-H2.0-LS4.8
L0402_L1.0-W0.5-H0.5_BEAD x 2
SOT-23-3P_L2.9-W1.3-H1.0-LS2.4-P0.95
C0402_L1.0-W0.5-H0.5
IND-SMD_L4.0-W4.0_XGL4020
SOT-23-5_L2.9-W1.6-H1.1-LS2.8-P0.95
CONN-SMD_PH-5AWT
ESOP-8_L4.9-W3.9-P1.27-LS6.0-BL-EP2.0
CONN-SMD_113991054
MapleLink_PCB

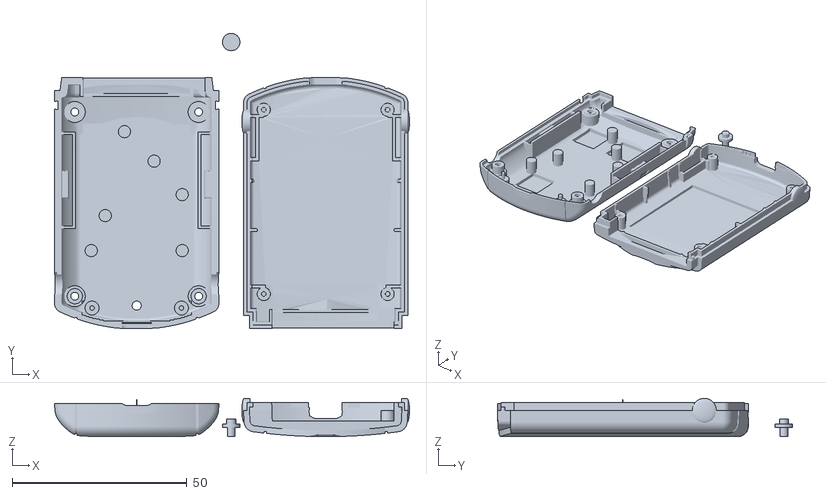
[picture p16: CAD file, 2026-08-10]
hardware/enclosure/Edited_VMU_stls/PulsarFit_703035/pulsar_vmu_PRINT_PLATE.stl
101.5 x 84.4 x 11.0

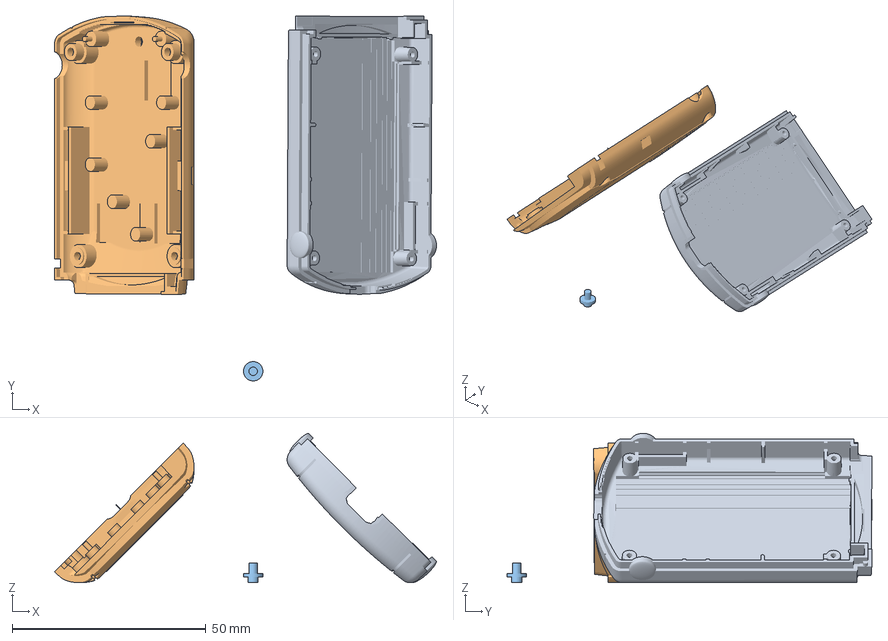
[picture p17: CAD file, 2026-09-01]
hardware/enclosure/Edited_VMU_stls/PulsarFit_bigcell_cable_relief/pulsar_bigcell_cable_relief.3mf
98.6 x 94.1 x 38.5 mm
pulsar_vmu_front_bigcell_cableexit.stl
pulsar_vmu_rear_cableexit.stl
pulsar_vmu_button_plunger.stl

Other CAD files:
hardware/enclosure/VMU_ShellAssembly.step
hardware/enclosure/Edited_VMU_stls/PulsarFit_bigcell_cable_relief/pulsar_vmu_front_bigcell_cable_relief.stl
hardware/enclosure/Edited_VMU_stls/PulsarFit_703035/pulsar_vmu_front.stl
hardware/enclosure/Edited_VMU_stls/PulsarFit_bigcell/pulsar_vmu_front_bigcell.stl
hardware/enclosure/Edited_VMU_stls/dreamcast_vmu_front.stl
hardware/enclosure/Edited_VMU_stls/PulsarFit_bigcell/pulsar_vmu_rear.stl
hardware/enclosure/pulsar_pcb.stl
hardware/enclosure/Edited_VMU_stls/dreamcast_vmu_back.stl
hardware/enclosure/Edited_VMU_stls/PulsarFit_703035/pulsar_vmu_rear.stl
hardware/enclosure/blender_files/dreamcast_vmu_back.blend
hardware/enclosure/blender_files/dreamcast_vmu_back2.blend
hardware/enclosure/blender_files/dreamcast_vmu_back3.blend
hardware/enclosure/blender_files/dreamcast_vmu_back4.blend
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

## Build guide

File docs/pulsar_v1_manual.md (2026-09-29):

# Pulsar v1 — Owner's Manual

Your Pulsar is a Dreamcast controller adapter. It reads a real Dreamcast controller over
the Maple Bus and presents it to your computer, phone, or console as a standard Bluetooth
gamepad. No dongle, no drivers.

This manual covers **Pulsar v1** — the assembled unit in the VMU-shaped shell. If you built
your own on a XIAO or an nRF52840-DK, see [`users_guide.md`](users_guide.md) instead, which
covers all three boards.

---

## 1. Connecting your controller

Pulsar ships in one of two ways. Check which one you have before going further.

### If your unit came with a controller

It is already wired. Plug the adapter's lead into the controller if it isn't already, and
skip to [First-time pairing](#2-first-time-pairing).

### If you bought the adapter on its own

Your unit ships with a 5-pin JST lead fitted to its **CN1** port, with bare flying leads at
the far end. You supply the Dreamcast controller and join the two. **This is a soldering
job and it permanently modifies the controller** — the cable gets cut. Budget half an hour,
and use a controller you're willing to alter.

You will need: a multimeter, a soldering iron, wire strippers, heat-shrink or tape.

**Step 1 — cut the controller cable.** Cut it a comfortable working distance from the
controller, keeping the length you want between the controller and the adapter. Keep the
controller end; the plug end is not used.

**Step 2 — identify the five conductors with a meter.** The cable carries five conductors
plus a shield. The Maple pinout is:

| Pin | Typical color | Function |
|-----|---|---|
| 1 | Red | SDCKA — data/clock A |
| 2 | Blue | +5 V power |
| 3 | Black | Ground (the cable shield ties here) |
| 4 | Green | Sense — tied to ground |
| 5 | White | SDCKB — data/clock B |

> **Meter your actual cable. Do not trust the colors.** Third-party and later-revision
> Dreamcast controllers use different color codes, and the table above is the canonical
> Maple pinout, not a promise about the cable in your hand. Buzz each conductor from the
> cut end back to the controller's connector to establish which is which.

**Step 3 — splice.** Join each conductor to the matching wire on the adapter's lead.
Insulate every joint individually, then sleeve the bundle. Keep the splice slim — it has to
sit inside the shell without straining the cable exit.

**Step 4 — check before you power it.** With nothing plugged in, check continuity end to
end on all five conductors, and check for shorts *between* adjacent conductors. A short
between +5 V and ground, or between either data line and power, can damage the adapter or
the controller. This check takes two minutes and is worth every one of them.

**Step 5 — plug into CN1** and pair. If the controller is never detected, come back to
[Troubleshooting](#11-troubleshooting).

---

## 2. First-time pairing

**Pair first, then the controller wakes up.** This is the reverse of most adapters and it
is the single most common source of confusion, so it's worth reading before you start.

Pulsar does not power the controller until a Bluetooth host is connected. An adapter
sitting on your desk plugged into a charger spends that energy on its battery instead of
running a controller nobody is using. So until you pair, **the controller is unpowered and
a docked VMU is blank. That is normal, not a fault.**

1. **Wake the adapter** with a short press of the sync button.
2. On first power-on it enters **pairing mode automatically** (nothing is bonded yet) and
   stays discoverable for 60 seconds. If it has been paired before, hold sync for
   **2 seconds** to enter pairing mode.
3. On your host, open Bluetooth settings and look for **"Xbox Wireless Controller."**
4. Select it to pair.
5. The controller comes alive as the connection completes — a docked VMU chirps and flashes
   as it boots, and the status LED turns green.

The adapter remembers your host and reconnects on its own from then on. Just press sync to
wake it.

**Pulsar holds one pairing at a time**, like an Xbox controller, and while paired it turns
away any other device that tries to pair. Pairing mode does not forget your current host: let the 60 seconds lapse and the adapter goes straight back to it.
The old pairing is replaced only once a new host finishes pairing — and from then on the old
host still lists the adapter and won't reconnect to it, so forget the adapter there before
pairing it back.

A brief drop at the edge of range does not reset the controller: the adapter keeps it and the
VMU powered for 10 seconds after the link drops, so a quick reconnect carries on.

---

## 3. Button mapping

| Dreamcast | Sends as |
|---|---|
| A | A |
| B | B |
| X | X |
| Y | Y |
| Start | Menu |
| D-pad (all 8 directions) | D-pad |
| Left trigger | Left trigger (analog) |
| Right trigger | Right trigger (analog) |
| Analog stick | Left stick |

The Dreamcast pad has one analog stick, so there is no right stick.

### The Guide button

The Dreamcast pad has no Guide button, so it's a chord: **pull both triggers and hold Start
for about a third of a second.**

This opens the Steam overlay, Big Picture, or the Xbox Game Bar, depending on your host.
It's deliberately a hold rather than a tap so it can't fire mid-game, and it deliberately
avoids the face buttons so it never collides with the Dreamcast's own
`A+B+X+Y+Start` soft-reset combo. While you hold it, the triggers and Start are suppressed,
so the host sees only Guide.

On the **Dreamcast** profile the same chord arrives as plain **Button 11** — bind that to
Guide in Steam Input if you want the overlay there.

---

## 4. The sync button

One button, several gestures. The LED blinks while you hold, and **blinks faster once you pass
2 seconds**, so you can see the next step coming and release in time.

| Gesture | What happens |
|---|---|
| **Short press** | Wake, or ask to reconnect |
| **Hold 2 s** | Pairing mode for 60 s — keeps the current pairing until a new host pairs. Refused while a VMU save is being written |
| **Triple-press** | Switch profile (Xbox ⇄ Dreamcast), then reboot |
| **Hold 3.5 s, with the controller's Start held** | Firmware update mode |
| **Tap, tap, then hold 3.5 s** | Firmware update mode, no controller needed |
| **Tap once, then hold 3.5 s** | [Browser configuration mode](#remapping-your-buttons) — remap buttons |
| **Hold 7 s** | Sleep — shows `BYE`, then powers down. Waits for a [VMU save](#6-the-vmu-display) still being written |
| **Hold 15 s** | Sleep now, even mid-save — the blocks not yet written are lost |

Entering update mode does **not** clear your pairing. Only a new host finishing pairing
replaces it.

The three tap-then-hold gestures differ only in **how many taps come before the hold**: one
tap is configuration, two is the controller-free update, and three short presses with no
hold is the profile toggle. Start the hold within about two seconds of the first tap.

### Profiles

Two identities, switched with a triple-press.

| Profile | Advertises as | Use it for |
|---|---|---|
| **Xbox** (default) | Xbox Wireless Controller | Almost everything — macOS, Windows, Steam, Linux (xpadneo), BlueRetro, BLE receivers |
| **Dreamcast** | Dreamcast Wireless Controller | A plain generic HID gamepad, for hosts where you'd rather not appear as an Xbox pad |

**Use Xbox unless you have a reason not to.** The Dreamcast profile is *not* Dreamcast
controller emulation — it's an ordinary generic BLE gamepad, and only the Bluetooth name is
Dreamcast-branded. Pick it to avoid Xbox button prompts in games, or for a host that
prefers a neutral HID device.

After switching, **forget the adapter on your host and pair again** — most hosts cache the
button layout against the old pairing. The choice is saved and survives a restart.

### Remapping your buttons

**Firmware 243 or later.** You can change what every control sends, from a browser, with
nothing to install. The map is stored on Pulsar itself, applies to **both profiles**, and
travels with the controller to every host you pair with.

**Tap sync once, then press it again and hold through 3.5 seconds.** Pulsar resets,
disconnects from your host and advertises as **`Pulsar Configure`** for 60 seconds. Open
<https://pulsar.alwaysagog.com/configure> in **Chrome or Edge on a computer, or Chrome on
Android**, and connect to it there. Safari and Firefox cannot do this — they do not support
Web Bluetooth.

Press a control and you will see it register live. Changes preview on the adapter before
you commit them, so you can feel a layout before keeping it — then **save to adapter** to
make it stick.

> Nothing is written until you save, so if the session ends mid-preview — you disconnect,
> the 60 seconds lapse, or the battery dies — Pulsar goes back to the last map you saved,
> with your pairing untouched.

---

## 5. The LED bar

Five LEDs behind the shell window. The first carries status; the other four are the battery
gauge. They're deliberately dim to avoid glare.

| LED 0 | Meaning |
|---|---|
| Blue sweep across the bar | Starting up |
| Dim red | Looking for the controller |
| Dim green | Controller connected |
| Dim amber | Writing a save to the VMU — leave it docked |
| Blue, blinking | Sync button held, or in pairing mode |
| Blue, blinking faster | You're past 2 seconds — keep holding and it sleeps |
| Five quick flashes | Profile switched, rebooting |
| All dark | Asleep, or idle and waiting for a host |

**LEDs 1–4 are the battery gauge**, in magenta — a different color from the status LED so
the two can't be confused. They stay lit through status changes, so losing the controller
doesn't blank your battery reading. **LED 1 in dim red means the battery is empty** — beside
a red status LED, that is a cell too low to power the controller, not a faulty controller.
Charge it.

A lit bar means the battery is connected. It does not tell you the controller has power —
that only happens once a host connects.

---

## 6. The VMU display

Dock a VMU and the adapter draws on it while connected: a profile splash when you connect,
holding about 30 seconds, then a rotating pulsar with a battery indicator. Pairing shows
`SYNC`; going to sleep shows `BYE`.

<table>
  <tr>
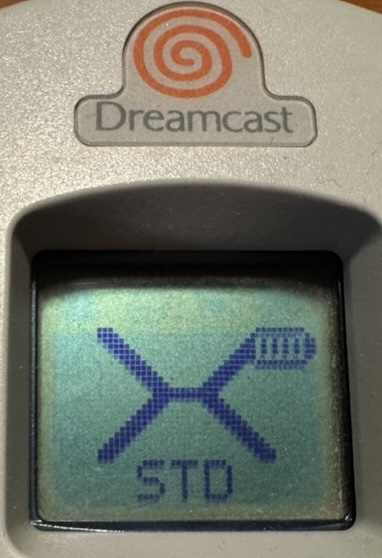
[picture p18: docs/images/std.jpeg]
Xbox profile splash
    <td align="center"><br>Xbox profile</td>
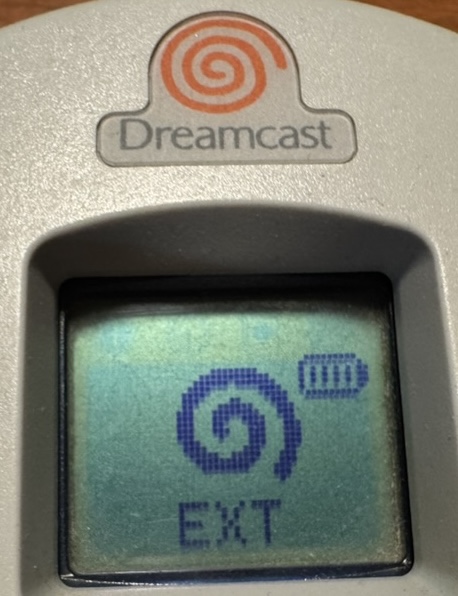
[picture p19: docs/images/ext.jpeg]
Dreamcast profile splash
    <td align="center"><br>Dreamcast profile</td>
    <td align="center">Rotating pulsar<br>In session</td>
  </tr>
  <tr>
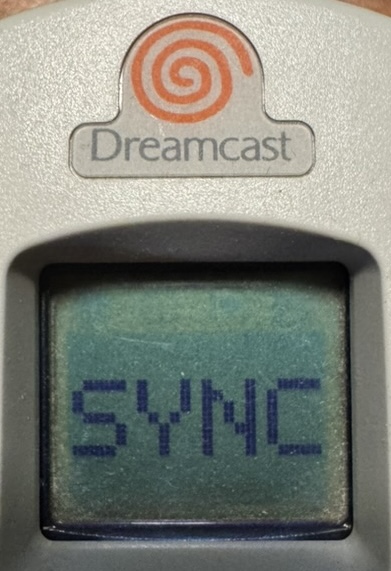
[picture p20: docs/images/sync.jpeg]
SYNC splash
    <td align="center"><br>Pairing</td>
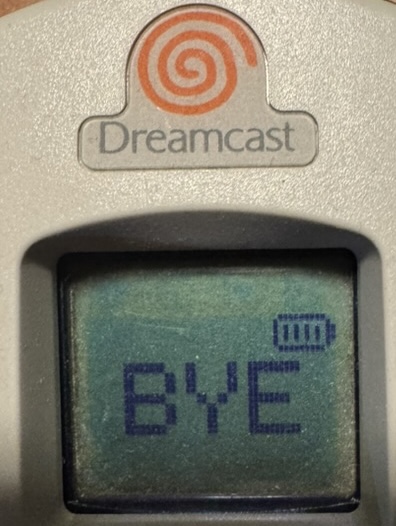
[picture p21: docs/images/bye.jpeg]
BYE splash
    <td align="center"><br>Sleeping</td>
    <td></td>
  </tr>
</table>

A dark VMU tells you nothing on its own — a powered VMU that nobody has written to looks
exactly like an unpowered one. The chirp on connect is the reliable sign it has power.

Animating the display costs roughly 5–10% of battery life against running with no VMU
docked.

**Programs on your host can use the VMU too** — draw their own screen, and read and write
your saves — over a Bluetooth service Pulsar publishes for anyone to build against
([host_integration.md](host_integration.md)). Reads happen only while the pad is put down.
While a save is being written, a small **disk icon** shows in the LCD's top-left corner and
the status LED turns amber: **don't pull the VMU until it clears.** Sleep waits for the save
to finish, and pairing mode is refused until it does; hold sync 15 seconds to sleep anyway.

---

## 7. Battery and charging

Charge over **USB-C** on the adapter itself. A phone charger or USB power brick is ideal.

The gauge reports in **four steps — 25 / 50 / 75 / 100%** — shown on LEDs 1–4 and on the
VMU, and reported to your host over Bluetooth (so it appears in your Bluetooth settings and
in games that show controller battery). It moves in visible jumps rather than sliding down
gradually. That's the gauge's resolution, not a fault.

> **Some laptops won't charge it, especially MacBooks.** A laptop port that looks for a USB
> device may cut power to a sleeping adapter, which has its USB peripheral switched off. If
> charging seems not to happen from a laptop, use a wall charger, or keep the adapter awake
> while it's plugged in.

**While it is charging, the VMU's battery icon shows a lightning bolt instead of the level
bars.** That is not a fifth level — it replaces the reading, and the level comes back the
moment you unplug. A charger holds the battery's voltage up, so any level measured while
charging reads high; the bolt says the number would be misleading rather than showing you a
wrong one. If the icon is completely empty, charge it now.

Once charging finishes with the cable still in, the gauge reads **full**. (The chip reads a
rested full battery as 75 %; Pulsar shows 100 % when the charger says it is done.)

---

## 8. Sleep and wake

The adapter sleeps to save battery when:

- you hold sync for **7 seconds**;
- **60 seconds** pass after power-on with no Bluetooth connection;
- **60 seconds** pass with Bluetooth connected but no controller detected;
- **60 seconds** pass after the controller is disconnected while Bluetooth is connected;
- **10 minutes** pass with no input from the controller while connected.

**To wake it, press sync.** It restarts and reconnects to your paired host.

Charging works normally while it sleeps. If you're storing it for a while, charge it first
and expect to top it up before the next session.

---

## 9. Updating the firmware

Pulsar v1 updates **wirelessly, from a web page** — no cables, no drivers, no software to
install.

1. Charge the adapter, or plug it in. Updates are refused **below 50% battery** unless it's
   charging; the VMU shows `CHRG` if so.
2. Enter update mode: hold sync past **3.5 seconds while holding the controller's Start**.
   Three fast flashes confirm it. No controller attached? **Tap sync twice, then hold past
   3.5 seconds**, starting the hold within about two seconds of the first tap.
3. The adapter reboots and advertises as **`PulsarDFU`** — not its usual name.
4. Open the update page in a supported browser and follow it through.

Updates are signed, so the adapter only accepts official firmware.

> **Updating to v0.6.0: pair again, once.** Old pairings are not carried across this update.
> The adapter will not reconnect on its own, even though your host may still list it as
> paired. Forget it in the host's Bluetooth settings, hold sync for 2 seconds, and pair fresh.
> It may appear as a new device; remove the old entry. Later updates keep your pairing.

### Your browser has to support Web Bluetooth

If the update page never shows a device chooser, this is almost always why.

| Browser | Works? |
|---|---|
| **Chrome / Edge / Opera** on Windows or macOS | Yes |
| **Brave** | Yes, but you must enable it first — `brave://flags` → **Web Bluetooth API** → Enabled → relaunch |
| **Chrome on Linux** | Needs `chrome://flags/#enable-experimental-web-platform-features`, plus BlueZ 5.41+ |
| **Firefox** | No — unsupported on every platform |
| **Safari**, including iPhone and iPad | No — Apple does not implement the API |

On an iPhone or iPad there is no way to make Safari work. Update from a computer, or use a
Web Bluetooth browser such as Bluefy.

> **There is no reset button, and no USB drive.** Double-tapping anything does nothing, and
> no drive will appear on your computer. The sync gestures above are the only way into
> update mode — this is deliberate.
>
> **An interrupted update is not a brick.** If the firmware ends up missing or incomplete,
> the adapter enters update mode by itself at power-on and waits. Plug it in, reload the
> page, try again.

---

## 10. What this unit does not do

- **No rumble.** The board can drive a rumble motor, but **no motor is fitted** to units at
  this revision. Rumble commands from your host arrive and are ignored, harmlessly.
- **No right stick.** The Dreamcast controller doesn't have one.
- **One host at a time.** Pairing to a new device replaces the old pairing.

---

## 11. Troubleshooting

**The controller and VMU are dead until I connect a host**
Expected — see [First-time pairing](#2-first-time-pairing). The adapter powers the
controller only once a Bluetooth host connects. Connect your host: the VMU chirps and the
status LED goes green. If it stays dark *after* connecting, keep reading.

**The status LED stays red — the controller is never found**
First look at LED 1. If it is dim red, the battery is too low to power the controller:
charge it and try again. Otherwise, check the lead is fully seated at both ends. On a self-wired unit, re-check your splice:
continuity end to end on all five conductors, and no shorts between them. A miswired data
line looks exactly like a dead controller.

**I can't find "Xbox Wireless Controller" in Bluetooth**
Hold sync for 2 seconds to force pairing mode — it's only discoverable for 60 seconds at a
time. Stay within about 10 m. If this host paired with it before, forget the adapter there
first, then pair fresh.

**It won't reconnect after updating to v0.6.0**
Expected, once. Forget the adapter on your host, hold sync 2 seconds, and pair fresh — see
[§9](#9-updating-the-firmware).

**It won't reconnect after I paired it to something else**
Pulsar holds one pairing. Forget it on the device you're trying to return to, then hold sync
2 seconds and pair again.

**Connected, but no input**
Give the host a few seconds after connecting to finish discovering the controller. Then
press a button on the Dreamcast pad to confirm it's responding.

**The buttons are mapped wrong**
Try the other profile — triple-press sync — then forget the adapter on your host and pair
fresh, since most hosts cache the layout. Also check whether your host is remapping things
itself (Steam Input, accessibility shortcuts).

**Flycast's mapping screen leaves the stick "Up"/"Left" rows blank**
Cosmetic. Use the Xbox profile for SDL-based emulators. After "Reset to default," Flycast
labels only the Down/Right rows but binds the *full* axis to both directions — the stick
works fully in game. Don't hand-map the blank rows.

**The battery indicator jumps in big steps**
Normal — the gauge has four levels, so it steps 100 → 75 → 50 → 25.

**It keeps going to sleep**
See [Sleep and wake](#8-sleep-and-wake) for the five timeouts. Press sync to wake it.

**The update page never finds the adapter**
Check your browser first — see the table in [Updating the
firmware](#9-updating-the-firmware); Brave needs a flag and Firefox and Safari can't do it
at all. Then confirm the adapter is actually in update mode: it advertises as `PulsarDFU`,
not under its usual name.

---

## Reference

- [`users_guide.md`](users_guide.md) — the full guide, covering the DIY XIAO and DK builds too
- [`pin_mapping.md`](pin_mapping.md) — complete pinouts for every board
- [`maple_bus_protocol.md`](maple_bus_protocol.md) — how the Dreamcast controller is actually read

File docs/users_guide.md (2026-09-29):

# Dreamcast Wireless Controller Adapter - User Guide

## What You Need

- Controller wired with Pulsar device
- A Bluetooth Low Energy capable device (phone, tablet, PC, or Dreamcast with BLE receiver like iBlueControlMod)

## Which board do you have?

The same firmware runs on three boards. They behave identically as a gamepad — everything in
Button Mapping, Profiles, and the VMU Display applies to all of them — but they differ in
what they can *show* you and how you update them. Where a section below is board-specific,
it says so.

| | **Pulsar v1** | **XIAO** (DIY) | **DK** (bench) |
|---|---|---|---|
| What it is | The designed carrier board, with a XIAO nRF52840 module mounted on it | A XIAO nRF52840 wired up by hand on perfboard or a breadboard | Nordic nRF52840-DK dev kit |
| Status light | 5-LED bar: LED 0 status, LEDs 1–4 battery | The XIAO's onboard RGB (one LED) | Discrete kit LEDs |
| Battery gauge | IP5306 fuel gauge, four levels | Voltage estimate from the battery ADC | None — no battery |
| Rumble | Motor output (CN3), **no motor fitted as shipped** | No | No |
| Charging | Onboard, USB-C | Onboard, via the XIAO's USB-C | Not applicable |
| Firmware update | Wireless (OTA) | USB drag-and-drop (UF2) | Debug probe |
| Sleep | Deep sleep (System Off) | Deep sleep (System Off) | Halts instead of sleeping |

Pulsar v1 and the DIY build share the same XIAO module, so they run the same silicon — the
carrier adds power management, the LED bar, and the motor output around it.

## First-Time Pairing

1. **Power on** the adapter. The status light blinks briefly, then shows *searching* while it
   looks for the controller — red on Pulsar v1 and XIAO, LED4 on the DK.
2. Once the controller is detected, the status light turns green (LED3 on the DK).

> **Pulsar v1 waits for your host before it powers the controller.** The adapter only
> switches on the controller's 5 V supply once a Bluetooth host is connected, so that a
> plugged-in adapter sitting idle charges its battery instead of running the controller.
> Until you pair, the controller is unpowered and a docked VMU is blank — that is normal.
> The moment your host connects, the VMU chirps as it powers up and the status light goes
> green. So on this board, expect to pair *first* and see the controller come alive
> *after*, which is the reverse of steps 1 and 2 above.
3. The adapter automatically enters **pairing mode** on first boot (since no device is bonded yet). It will be discoverable for 60 seconds.
4. On your host device, open Bluetooth settings and look for **"Xbox Wireless Controller"**.
5. Select it to pair. The LED will turn solid to indicate a connection.

That's it! The adapter remembers your device and will reconnect automatically in the future.

## Reconnecting

After the first pairing, the adapter reconnects automatically:

1. Power on the adapter.
2. Turn on Bluetooth on your host device.
3. The adapter will find and connect to your previously paired device within a few seconds.

No need to re-pair each time.

A short drop — walking to the edge of range, a host that blinks its Bluetooth — does not
power-cycle the controller. The adapter keeps the controller, VMU and rumble pack powered for
10 seconds after the link drops, so a quick reconnect picks up where it left off.

## Button Mapping

| Dreamcast | Xbox Equivalent |
|---|---|
| A | A |
| B | B |
| X | X |
| Y | Y |
| Start | Menu |
| D-pad Up | D-pad Up |
| D-pad Down | D-pad Down |
| D-pad Left | D-pad Left |
| D-pad Right | D-pad Right |
| Left Trigger | Left Trigger |
| Right Trigger | Right Trigger |
| Analog Stick | Left Stick |

The Dreamcast controller has one analog stick, which maps to the left stick. The right stick is not available.

### Guide / Xbox Button (chord)

The Dreamcast pad has no Guide button, so it's a chord: **pull Left Trigger + Right Trigger and hold Start together (about a third of a second).** This sends the **Guide (Xbox) button** — e.g. it opens the **Steam overlay** / Big Picture, or the Xbox Game Bar.

- It's deliberately a *hold* so it won't fire by accident during play, and it's kept off the face buttons so it never collides with the Dreamcast/GDEMU `A+B+X+Y+Start` reset combo. While held, the triggers and Start are suppressed so the host sees only Guide.
- The chord works on **both profiles.** On **Xbox** it's the real native Guide button (the Steam overlay opens automatically). On **Dreamcast** it comes through as a plain **Button 11** — bind that to "Guide" in Steam Input (or your host's controller settings) if you want the overlay shortcut there.

## Sync Button

| Action | Result |
|---|---|
| Short press | Wake / request reconnect |
| Hold 2s | Pairing mode (60s) — keeps the current bond until a new host pairs. Refused while a [VMU save](#host-programs-the-screen-and-your-saves) is being written |
| Hold 3.5s **+ controller Start** | Firmware update mode (OTA) — *Pulsar v1 only*. Refused while a [VMU save](#host-programs-the-screen-and-your-saves) is being written |
| Tap, tap, then hold 3.5s | Same update mode, **no controller needed** — *Pulsar v1 only* |
| **Tap once, then hold 3.5s** | **Browser configuration mode** — [remap buttons](#remapping-buttons-from-your-browser). Refused while a [VMU save](#host-programs-the-screen-and-your-saves) is being written |
| Hold 7s | Sleep — shows `BYE`, releases into deep sleep (the DK halts instead). Waits for any [VMU save still being written](#host-programs-the-screen-and-your-saves) |
| Hold 15s | Sleep **now**, even mid-save — the blocks not yet written are lost |
| Triple-press | Switch profile (Xbox ⇄ Dreamcast) and reboot. Refused while a [VMU save](#host-programs-the-screen-and-your-saves) is being written |

The three tap-then-hold gestures are told apart by the **number of taps before the hold**:
one tap is configuration, two is controller-free update, three short presses (no hold at
all) is the profile toggle. Begin the hold within about two seconds of the first tap, or it
counts as an ordinary hold.

The sync LED blinks faster once you pass 2s, so you can see the next step coming before you reach it. Release at that point to pair; keep holding to sleep.

**Firmware update** has two routes. The usual one needs both hands: hold the sync button past 3.5s *while* the Dreamcast controller's **Start** button is held. Three fast flashes confirm it. It is refused **below 50% battery** unless you are charging — the display shows `CHRG` if so. It is also refused while a VMU save is being written: no flashes, and the display shows `SAVE` (unless a program owns the screen) — try again once the disk icon is gone. Holding past 3.5s with Start down does **not** clear your pairing.

The second route needs no controller at all: **tap the sync button twice, then hold it past 3.5s**. Begin the hold within about two seconds of the first tap, or it counts as an ordinary hold. Two taps rather than three keeps it distinct from the profile toggle, which is three *short* presses. This exists so an adapter with nothing plugged in — or with a controller that has stopped responding — can still be updated.

This gesture is for **Pulsar v1**, which updates wirelessly. On a XIAO or DK build the gesture does nothing useful — those boards are reflashed over USB or a probe instead. See [Updating the firmware](#updating-the-firmware).

Entering pairing mode does **not** forget the host you already have. Change your mind — let
the 60 seconds lapse, or just walk away — and the adapter goes back to the host it was paired
with and reconnects as though nothing happened. The bond is replaced only once a new host
actually finishes pairing.

Once a new host does pair, the **old** host still has the adapter in its Bluetooth list, and
that entry is now stale. Forget the adapter there — same as any single-bond controller (Xbox,
etc.). While the 60-second window is open the old host cannot reconnect on the pairing it
already has; if it keeps interrupting, turn its Bluetooth off until the new host is paired.

**If the computer forgets the adapter first**, the adapter does not know: it still holds its
side of the pairing and keeps quietly trying to reconnect to a device that has stopped
answering, then sleeps to save battery. It will **not** re-appear in the Bluetooth list on its
own. Hold sync for 2 seconds to offer it up again — and start the computer's scan *before* the
gesture, because the adapter is only discoverable for 60 seconds after it.

### Profiles

Two identities, switchable with a triple-press. **Use Xbox by default** — it now works essentially everywhere tested: macOS (browser + Steam), Windows (+ Steam), Linux (xpadneo), BlueRetro, and BLE receivers.

The **Dreamcast** profile is **not** a Dreamcast-controller emulation — it's just a plain, **generic BLE HID gamepad**; the only "Dreamcast" thing about it is the Bluetooth name. Pick it if you'd rather not present as an Xbox controller (e.g. to avoid Xbox button prompts in games) or for a host that prefers a neutral HID gamepad.

| Profile | Best for | Bluetooth name |
|---|---|---|
| **Xbox** (default) | macOS (browser + Steam), Windows (+ Steam), Linux (xpadneo), BlueRetro, iBlueControlMod / BLE receivers — anything that recognizes an Xbox controller | Xbox Wireless Controller |
| **Dreamcast** | A plain, generic BLE HID gamepad (neutral identity — only the Bluetooth name is Dreamcast-branded) — Android, simple HID consumers, or hosts where you'd rather not present as Xbox | Dreamcast Wireless Controller |

After switching, forget the adapter on your host and pair again so it picks up the new HID layout. The profile is saved to flash.

## Remapping Buttons From Your Browser

**Firmware 243 or later.** You can change what every Dreamcast control sends. The saved map
lives on the adapter, applies to **both profiles**, and follows the controller to every host
you pair with — there is nothing to install on the host and nothing to re-do when you switch
computers.

### Entering configuration mode

**Tap sync once, then press it again and hold through 3.5 seconds**, until the adapter
resets. It disconnects from your host and advertises as **`Pulsar Configure`** for 60
seconds.

This is a separate, unbonded identity: while it is in configuration mode the adapter is not
a gamepad, has no bond, and will not appear as a controller. Anything that ends the session
— finishing, disconnecting, letting the 60 seconds lapse, or losing power — resets it
straight back to normal operation with your existing pairing intact.

### Making changes

Open the configure page in **Chrome or Edge on a computer, or Chrome on Android** (it uses
Web Bluetooth, which Safari and Firefox do not implement), connect to `Pulsar Configure`,
and you get a live view of the controller: press a button and you see it register. Changes
**preview live** on the adapter before you commit them, so you can try a layout and feel it
working. Nothing is written to flash until you choose to save.

> **Only the durable map survives.** A preview is exactly that — if the session ends while
> you are previewing, the adapter reverts to the last map you saved. Save before you walk
> away.

### On the other boards

Remapping is board-independent — it is the same firmware, and a XIAO or DK build enters
configuration mode with the same gesture and is configured the same way.

## VMU Display

The adapter draws on the VMU LCD while connected — a profile splash on every connect, then a rotating pulsar with battery indicator. Mode transitions get their own splash.

<table>
  <tr>
    <td align="center">Xbox profile splash<br>Xbox profile (boot)</td>
    <td align="center">Dreamcast profile splash<br>Dreamcast profile (boot)</td>
    <td align="center">Rotating pulsar<br>In-session</td>
  </tr>
  <tr>
    <td align="center">SYNC splash<br>Pairing mode</td>
    <td align="center">BYE splash<br>Sleeping</td>
    <td></td>
  </tr>
</table>

The profile splash holds for ~30 seconds after connect, then transitions to the rotating pulsar with battery indicator.

> **Battery note:** the VMU advances the pulsar animation about 4 times per second (every
> ~260 ms), plus extra writes on splash transitions. This costs roughly 5–10% of battery life vs. running with no LCD activity. Worth it for the visual feedback, but worth knowing.

### Host programs: the screen and your saves

The adapter also offers a Bluetooth service that lets a program on the host reach the docked
VMU: draw its own screen on the LCD, and read and write the memory card's save blocks. With
no such program running, nothing changes — the adapter draws its own screens as above. The
service is published for anyone to build against in
[host_integration.md](host_integration.md), with reference scripts that push a frame and read
a card.

What you will notice when a program uses it:

- **Its screen wins.** A host's frame replaces the pulsar while that host is connected, and
  the adapter's own animation returns when the link drops.
- **Reads wait for you to put the pad down.** The card is only read while the controller has
  been untouched for about a second, so a transfer never costs you an input mid-game.
- **Saves show a disk icon.** While a save is being written to the card, a small disk icon
  sits in the top-left corner of the LCD and the status LED turns amber
  ([LED Indicators](#led-indicators)). **Don't pull the VMU while it's showing.**
- **Saves finish before sleep.** A save already accepted keeps being written for up to 30
  seconds if the link drops, and the 7-second sleep hold waits for it — `BYE` appears once
  the card is up to date. Hold for 15 seconds to sleep regardless; the blocks not yet
  written are lost. The 2-second pairing hold, the update and configuration gestures and the
  profile triple-press are all refused until the save is done.
- **Only your paired host gets in.** While the adapter is paired, another device that tries
  to pair with it is disconnected. To pair something new, hold sync for 2 seconds first.

## Battery & Charging

The adapter monitors the LiPo battery and reports the level over Bluetooth (visible in your host device's Bluetooth settings or supported games), and draws it on the VMU.

A single-cell LiPo runs from about 4.2 V charged down to about 3.3 V empty. The firmware's
own curve treats **≥ 4.10 V as 100% and ≤ 3.30 V as 0%**, the measured cutoff — so the
reported level reaches empty a little above the cell's absolute floor, deliberately.

How the level is measured depends on the board:

| Board | How it reads | What you see |
|---|---|---|
| **Pulsar v1** | IP5306 fuel gauge over I²C | Four levels (25 / 50 / 75 / 100%). LEDs 1–4 of the bar light in magenta, one per level — a deliberately different colour from the status LED so the two meanings can't be confused. |
| **XIAO** | Battery ADC against a LiPo discharge curve | A continuous percentage. The single onboard RGB has no room for a gauge, so it shows status only — read the level on the VMU or your host. |
| **DK** | No battery, no gauge | Nothing. The board reports no battery at all rather than a fake reading. |

Because the Pulsar v1 gauge moves in 25% steps, its indicator jumps between four states
rather than sliding down gradually. That's the gauge, not a fault.

On Pulsar v1:

- **An empty gauge is dim red on LED 1**, not a dark bar — so "the battery is flat" can't be
  mistaken for "no gauge". A cell too low to power the controller shows this beside the red
  searching light: charge it, the controller is fine.
- **The gauge is lit while searching for the controller** too, from two seconds into the
  search, so a flat cell is visible even when nothing answers on the bus.
- **A finished charge reads 100 %** while the cable is still in. The chip's own gauge reads a
  rested full cell as 75 %; the adapter shows full once the charger reports it has finished.

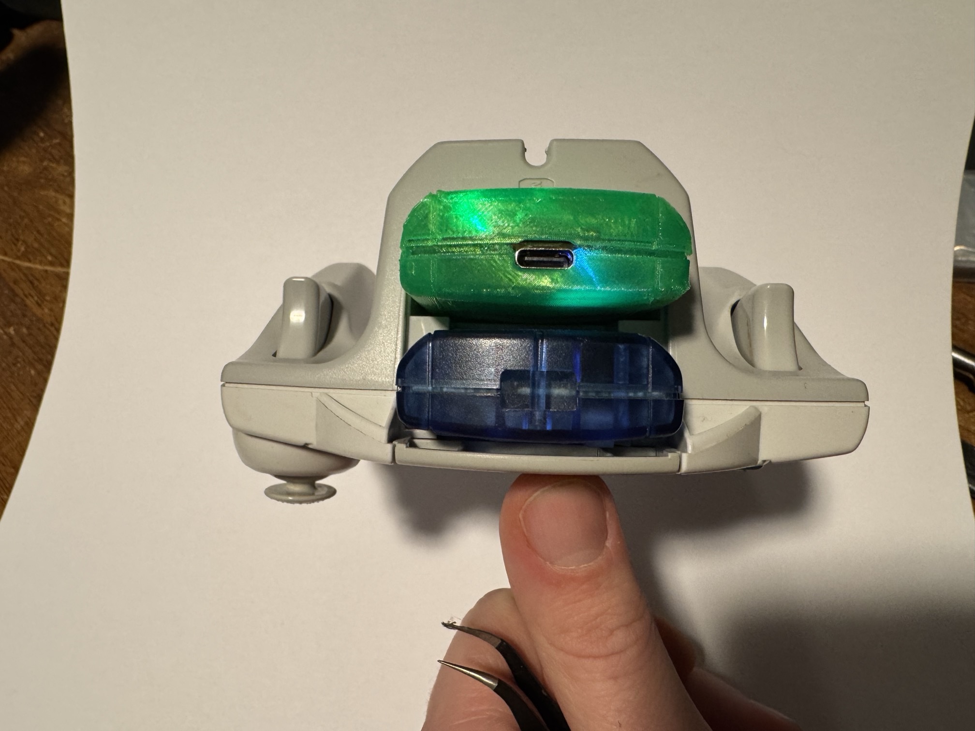
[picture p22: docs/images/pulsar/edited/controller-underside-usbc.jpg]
USB-C port reachable through the slot opening on the controller underside, with a VMU in the second slot


*The USB-C port faces out through the slot opening on the controller's underside — the
adapter charges in place, and a VMU in the second slot is unaffected.*

### The charging bolt

While a charger is attached, the VMU's battery icon shows a **lightning bolt inside the
outline instead of the level bars**. It is not an extra level — it replaces the reading, and
the level returns the moment charging stops.

This is deliberate. A charging pack's terminal voltage is pulled up by the charger, so the
level read while charging is optimistic — a battery reading "full" that empties as soon as
you unplug. Showing the bolt says *the reading is not meaningful right now* rather than
quietly showing a wrong one.

When the battery is genuinely critical the icon empties completely, which is the cue to
plug in.

Charge the battery over USB-C — on Pulsar v1 that's the carrier's own port, on a DIY build it's the XIAO's. A USB power brick or phone charger is recommended. **Note:** Some laptops (especially MacBooks) have smart USB ports that may reduce or cut power when the adapter is in deep sleep, since the USB peripheral is off and the laptop doesn't detect a device. If you notice the battery not charging from a laptop, either use a standard USB charger or keep the adapter awake while plugged in.

## Rumble

**No board rumbles at this revision.** Pulsar v1's carrier has a motor output (CN3) and the
firmware drives it, but **no motor is fitted to units as shipped** — CN3 is left empty.
Rumble commands from the host arrive and are ignored, which is harmless.

The XIAO and DK builds have no motor output at all. On every board the Xbox profile still
advertises rumble support, because the report is part of the identity the host expects, not
a per-board capability.

## Sleep & Wake

The adapter enters deep sleep to save battery in these situations:

1. **Manual sleep** -- hold the sync button for 7 seconds.
2. **No Bluetooth connection** for 60 seconds after power-on (advertising timeout).
3. **Controller not found** for 60 seconds after Bluetooth connects (detection timeout).
4. **Controller disconnected** for 60 seconds while BLE is connected (re-detect timeout).
5. **No controller input** for 10 minutes while connected (inactivity timeout).

When asleep, the nRF52840 itself draws microamps, but **the board around it draws more** —
the LED rail and the power path stay powered, and the figure has not been characterized on
Pulsar v1 yet. Treat deep sleep as low power, not as zero: expect a unit left for weeks to
need charging. The battery charges normally from USB while asleep.

**To wake up:** Press the sync button. The adapter performs a full restart and will reconnect to your paired device.

The **DK** has no battery and no power management, so it halts on the sleep gesture instead of entering deep sleep — the goodbye splash still runs, which is what makes the flow testable on the bench.

## Updating the firmware

> **Updating to v0.6.0: you will need to pair again, once.**
>
> v0.6.0 changes how the adapter presents itself over Bluetooth (so it works with the 8BitDo
> USB Wireless Adapter 2), and old pairings are not carried across. The same was true of
> updates from v0.3.0 or earlier. After updating, the adapter will not reconnect to your
> host on its own, and the host may still list it as paired. Forget the adapter in your
> host's Bluetooth settings, hold sync for 2 seconds, and pair fresh. It may appear as a new
> device; remove the old entry. This is a one-time step — later updates keep your pairing.

How you update depends on the board:

**Pulsar v1 — wireless.** Hold sync past 3.5s with the controller's **Start** held; three fast
flashes confirm it and the adapter reboots into update mode advertising as `PulsarDFU`. It is
refused **below 50% battery** unless you're charging, showing `CHRG` on the VMU — charge first
and retry — and while a VMU save is being written, showing `SAVE` — wait for the disk icon to
clear and retry. The update is signed, so the adapter only accepts official firmware.

> **There is no reset-button route into update mode on Pulsar v1, and no USB drive.**
> Double-tapping reset does nothing, holding a button while powering on does nothing, and no
> `XIAO-BOOT` volume will appear. Both button entry and pin-reset entry are deliberately
> switched off in this board's bootloader — the sync + Start gesture is the only way in.
>
> Two consequences worth knowing before you need them:
>
> - **You do not need the controller attached.** The sync + Start gesture checks that Start is
>   held, but the tap-tap-hold chord — two taps, then hold past 3.5s — reaches update mode on
>   its own. Older firmware had only the first route, so an adapter with nothing plugged in
>   could not be updated by hand at all.
> - **A failed or interrupted update is not a brick.** If the firmware is missing or
>   incomplete, the adapter enters update mode on its own at power-on and waits to be
>   re-flashed. Plug it in, reload the update page, and try again.

#### Your browser has to support Web Bluetooth

The update page talks to the adapter over Bluetooth from the browser, and not every browser
allows that. If the page never shows a device chooser, this is almost always why.

| Browser | Works? |
|---|---|
| **Chrome / Edge / Opera** on Windows or macOS | Yes, out of the box |
| **Brave** | Yes, **but you must turn it on first** — see below |
| **Chrome on Linux** | Needs `chrome://flags/#enable-experimental-web-platform-features` enabled, plus BlueZ 5.41 or newer |
| **Firefox** | No — not supported on any platform |
| **Safari**, including iPhone and iPad | No — not supported, and not planned |

**Brave** ships with Web Bluetooth switched off deliberately, as a privacy choice. To enable
it: open `brave://flags`, search for **Web Bluetooth API**, set it to **Enabled**, and relaunch
the browser. Without that step the page loads normally and simply never finds your adapter,
with no error to explain why — which is exactly what makes it worth checking first.

**On an iPhone or iPad there is no way to make Safari work**, because Apple does not implement
the API. Update from a computer, or use a third-party Web Bluetooth browser such as Bluefy.

**XIAO — USB drag-and-drop.** Double-tap the reset button; the board mounts as a USB drive
called `XIAO-BOOT`. Copy the `.uf2` file onto it and it reboots into the new firmware.

> **The web updater will not find a XIAO build — use the USB route.** This is not a fault in
> your browser or your board. A DIY XIAO runs the stock Adafruit bootloader, which speaks an
> older update protocol whose Bluetooth service Chrome blocks permanently, by name, as a
> matter of policy. No browser will ever reach it. Pulsar v1 carries a different bootloader
> specifically so the web route works there.

**DK — debug probe.** Flash over the onboard debugger with your usual tool.

Release builds are required on every board. Debug builds miss the Maple Bus timing window and
the controller will not be read reliably.

## LED Indicators

Every board shows the same *states*; what lights up differs.

**Pulsar v1 — five-LED bar.** LED 0 carries status; LEDs 1–4 are the battery gauge and stay
lit through status changes, so losing the controller doesn't blank your battery reading. The
colours are deliberately dim to avoid glare through the shell window.

| LED 0 | Meaning |
|---|---|
| Dim red | Searching for controller |
| Dim green | Controller found / connected |
| Dim amber | Writing a save to the VMU — leave it docked |
| All dark | Sleeping, or idle and waiting for a host to connect |

LED 1 lit dim red is the gauge reading empty — charge the battery.

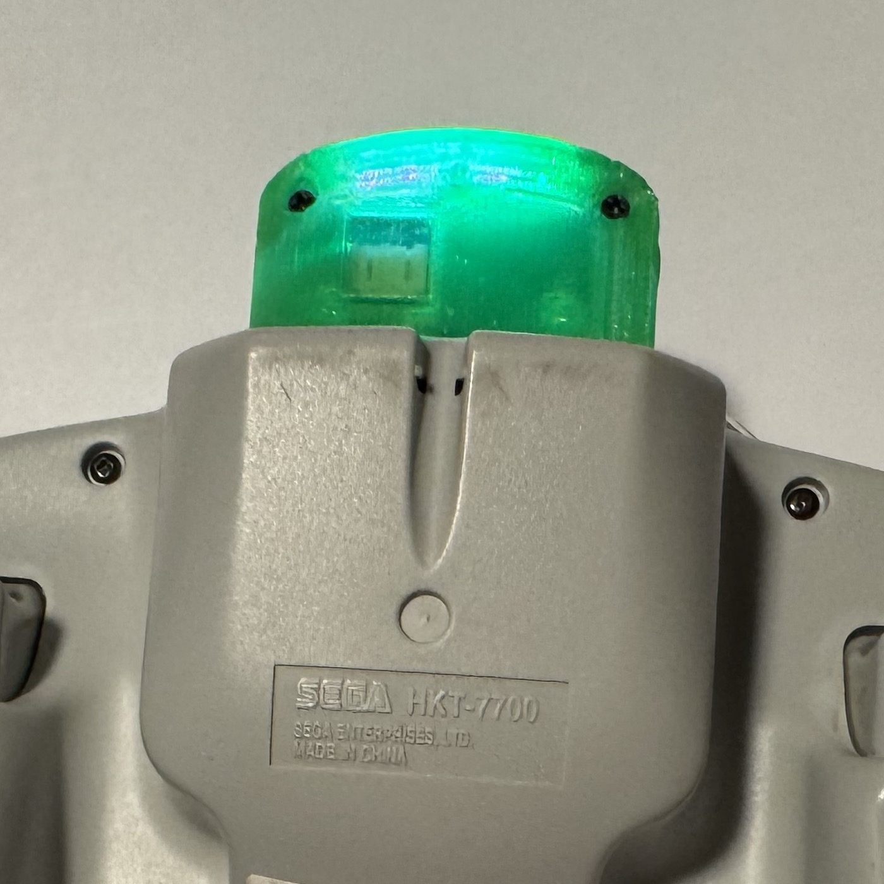
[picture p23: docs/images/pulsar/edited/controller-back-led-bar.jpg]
Adapter in the VMU slot, status LED lighting the shell green


*The status LED lighting the shell from the VMU slot (green = connected). The magenta
gauge LEDs sit behind the same window.*

**XIAO — onboard RGB (one LED).** No battery gauge; the level is on the VMU and your host.

**DK — discrete kit LEDs.** LED4 searching, LED3 connected, LED2 flickers on Maple TX
activity. LED1 is the sync LED.

| State | XIAO (RGB) | DK | Meaning |
|---|---|---|---|
| Starting up | Green blink ×3 | — | Boot |
| Searching | Solid red | LED4 on | Looking for the controller |
| Connected | Solid green | LED3 on | Controller found |
| Saving | Amber (red + green) | — (the DK does not write to a VMU) | Writing a save to the VMU |
| Pairing mode | Fast blue blink | Sync LED blinking | Discoverable for 60s |
| Sync held | Blink | Sync LED blink | Button held, action pending |
| Past sync point | Faster blink | Faster blink | Approaching sleep |
| Profile switched | 5 quick flashes | 5 quick flashes | Confirmed, about to reboot |
| Off | Off | Off | Sleeping or idle |

The sync LED behaviour (blink while held, faster past the 2s point, five flashes on profile
switch) is the same on all three boards — on Pulsar v1 and XIAO it's the blue channel of the
status light, on the DK it's LED1.

## Troubleshooting

**Controller and VMU are dead until I connect a host (Pulsar v1)**
- Expected. The adapter only powers the controller once a Bluetooth host is connected, so an
  idle adapter charges instead of running the controller. Connect your host: the VMU chirps as
  it powers up and the status light goes green. If it stays dark *after* connecting, work
  through the entry below.

**Controller not detected (status stays on *searching* — red, or LED4 on the DK)**
- On Pulsar v1, look at LED 1 first: dim red there means the battery is too low to power the controller. Charge it.
- Check that the controller cable is securely connected to the adapter.
- Make sure the controller is receiving 5V power.
- Try unplugging and re-plugging the controller.

**Double-tapping reset does nothing / no USB drive appears (Pulsar v1)**
- Expected. This board has no reset-button route into update mode and no `XIAO-BOOT` volume — button and pin-reset entry are both disabled in its bootloader. Use the sync + Start gesture instead. See [Updating the firmware](#updating-the-firmware).

**The update page never shows a device chooser (Pulsar v1)**
- Check the browser first. **Brave** has Web Bluetooth off by default — enable **Web Bluetooth API** in `brave://flags` and relaunch. **Firefox and Safari** don't support it at all, including on iPhone and iPad. **Chrome on Linux** needs `chrome://flags/#enable-experimental-web-platform-features`. Chrome, Edge, and Opera on Windows or macOS work as-is. See [Updating the firmware](#updating-the-firmware).
- If the browser is fine, make sure the adapter is actually in update mode — it advertises as `PulsarDFU`, not under its usual name.

**The web updater never finds my adapter (XIAO build)**
- Expected, and not fixable from your side. A DIY XIAO runs the Adafruit bootloader, whose update service Chrome blocks by policy. Update it over USB with the `.uf2` file instead.

**I can't get into update mode — no controller attached (Pulsar v1)**
- Use the controller-free chord instead: tap sync twice, then hold it past 3.5s, starting the hold within about two seconds of the first tap. If the firmware itself is broken or missing, the adapter enters update mode on its own at power-on without any gesture.

**It won't reconnect after a firmware update**
- Expected after updating to v0.6.0 (or from v0.3.0 or earlier) — the pairing does not survive that update, even if your host still lists the adapter as paired. Forget the adapter on your host, hold sync for 2 seconds, and pair fresh. See [Updating the firmware](#updating-the-firmware).

**Battery indicator jumps in big steps (Pulsar v1)**
- Normal. The IP5306 gauge reports four levels, so the bar moves 100 → 75 → 50 → 25 rather than sliding down continuously.

**Rumble does nothing**
- Expected on every board at this revision. Pulsar v1 has a motor output but ships with no
  motor fitted; XIAO and DK have no motor output at all. Rumble commands are accepted and
  ignored. See [Rumble](#rumble).

**Can't find "Xbox Wireless Controller" in Bluetooth**
- The adapter may not be in pairing mode. Hold the sync button for 2 seconds to enter pairing mode.
- Make sure you're within Bluetooth range (about 10 meters / 30 feet).
- On some devices, you may need to "forget" the old pairing first, then hold sync for 2 seconds to re-pair.

**Previously paired device can't reconnect after syncing to a new device**
- Go to Bluetooth settings on the old device and select "Forget This Device" for the adapter.
- Then hold the sync button for 2 seconds on the adapter to enter pairing mode and pair fresh.

**Connected but no input**
- Some hosts need a moment after connecting to discover services. Wait a few seconds after the connection is established.
- Try pressing buttons on the Dreamcast controller to verify it's responding.

**Adapter keeps going to sleep**
- Press the sync button to wake it up.
- The adapter sleeps after 60 seconds without a Bluetooth connection, 60 seconds if Bluetooth connects but no controller is detected, or after 10 minutes of no controller input. Keep interacting with the controller to prevent the inactivity timeout.

**Inputs feel wrong or mapped incorrectly**
- Try the other profile: triple-press sync to switch between Xbox and Dreamcast. After switching, forget the adapter on your host and pair fresh — most hosts cache the HID layout per-bond.
- Some hosts remap buttons in their own settings (Steam Input, accessibility shortcuts). Check there too.

**Flycast's mapping screen shows the stick "Up"/"Left" rows blank**
- Use the **Xbox** profile for SDL-based emulators (Flycast, RetroArch); the Dreamcast stick maps to the left analog stick.
- After "Reset to default," Flycast may label only the **Down**/**Right** rows ("Left Stick Y+/X+") and leave **Up**/**Left** blank. That's cosmetic — it binds the *full* axis to both directions, so the stick works fully in-game. No need to reset again or hand-map the blank rows.

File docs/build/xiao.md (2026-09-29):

# Build it yourself — the XIAO adapter

The hand-wired build. A Seeed XIAO nRF52840, a boost converter, two resistors and two
diodes on a scrap of perfboard, wired into a cut Dreamcast controller cable. It plays
identically to a Pulsar v1; what it gives up is the LED bar, the fuel gauge, rumble, and
wireless updates.

**This permanently modifies a controller — the cable gets cut.** Budget an evening for a
first build, and use a controller you are willing to alter.

| | |
|---|---|
| Skills | Soldering, reading a multimeter |
| Permanent change | The controller cable is cut |
| Flashing | USB, drag-and-drop — no debug probe needed |
| Time | 2–3 hours for a first build |

Other paths: [nRF52840-DK on the bench](dk.md) (no soldering, no controller modification)
· [installing an assembled Pulsar v1](pulsar-v1.md).

---

## 1. What you need

Full details and links are in the [bill of materials](../bill_of_materials.md). The short
list:

| Part | Qty | Notes |
|---|---|---|
| Seeed XIAO nRF52840 | 1 | The plain version. **Not** the "Sense" — you do not need the IMU/mic, and it costs more |
| Dreamcast controller | 1 | First-party is the only one tested |
| Pololu U1V11F5 5 V boost | 1 | Chosen for its `SHDN` pin — the firmware gates the controller's 5 V rail with it |
| 1N5817 Schottky diode | 2 | The USB/boost OR — see [§3](#3-the-5-v-rail-and-why-it-catches-people) |
| 10 kΩ resistor | 2 | Bus pull-ups. 4.7 kΩ also works |
| LiPo battery, 1000 mAh | 1 | 3.7 V, JST PH 2.0 mm. ~14–16 h; a 500 mAh gives ~7–8 h |
| Perfboard | 1 | Adafruit Perma-Proto quarter-size fits the printed shell |
| Tactile pushbutton | 1 | The sync button |
| 30 AWG wire | — | |

**Tools:** soldering iron, wire strippers, **multimeter** (not optional — see
[§2](#2-identify-the-cable-conductors)), heat-shrink, Kapton tape.

The XIAO already contains the parts people expect to add: a **USB-C connector**, a
**BQ25101 LiPo charger** with its own status line, a **battery-voltage divider** on an ADC
pin, and an **RGB status LED**. You are not wiring any of those — they are on the module,
and the firmware drives them through pins that never leave the board.

---

## 2. Identify the cable conductors

Cut the controller cable a comfortable working distance from the controller — keep the
length you want between the controller and the adapter. **Keep the controller end**; the
console plug is not used.

The Maple pinout is:

| Pin | Typical colour | Function | Goes to |
|---|---|---|---|
| 1 | Red | SDCKA — data/clock A | XIAO **D5** (P0.05) |
| 2 | Blue | +5 V power | the 5 V rail ([§3](#3-the-5-v-rail-and-why-it-catches-people)) |
| 3 | Black | Ground — the cable shield ties here | GND |
| 4 | Green | Sense — tied to ground | GND |
| 5 | White | SDCKB — data/clock B | XIAO **D1** (P0.03) |

> ### Meter your actual cable. Do not trust the colours.
>
> Third-party and later-revision controllers use different colour codes, and the table
> above is the canonical *Maple pinout* — not a promise about the cable in your hand.
> Getting this wrong puts 5 V onto a data line and can destroy the controller, the XIAO, or
> both.

**How to check, with the cable cut and nothing powered:**

1. Look into the controller's own connector shell — the five contacts are numbered in the
   moulding, or count from the keyed edge.
2. Set the meter to continuity (the beeping mode).
3. Hold one probe on a stripped conductor at the cut end and touch the other to each of the
   five contacts in turn. The one that beeps is that conductor's pin.
4. Write the colour against the pin number as you go. Do all five before soldering anything.
5. Confirm pins 3 and 4 beep against *each other* — sense is tied to ground inside the
   controller. If they do not, stop: you have mis-identified something.

---

## 3. The 5 V rail, and why it catches people

The Dreamcast controller runs on **5 V**. The XIAO is a 3.3 V part and cannot supply it, so
the 5 V comes from one of two places, and the design lets either one feed the rail without
back-feeding the other:

- **USB**, when a cable is plugged in — straight off the XIAO's `5V` pin (VBUS).
- **The boost converter**, when running on battery — 3.7 V up to 5 V.

Wiring both to the same node directly would push USB voltage back into the boost's output
and battery voltage back into VBUS. The two Schottky diodes prevent that. This is a **diode
OR**: each source feeds the rail through its own diode, and neither can see the other.

```
   XIAO 5V pin ──────►│──┐         D1: 1N5817   (band = cathode, ──►│ points to the rail)
   (USB VBUS)         ▲  │
                         ├──── +5 V rail ──── controller cable pin 2 (blue)
   Boost VOUT ───────►│──┘         D2: 1N5817
                      ▲
   Battery + ──── Boost VIN
   Battery − ──── GND ─────────── controller cable pins 3 and 4 (black, green)

   XIAO D2 (P0.28) ─── Boost SHDN          HIGH = boost on
```

**Diode orientation is the one thing to get right.** The banded end (cathode) of both
diodes faces the **controller**, away from the sources. Backwards and the controller simply
never powers up.

Use **Schottky** diodes specifically. The 1N5817 drops ~0.3 V, leaving ~4.7 V at the
controller, which it is happy with. An ordinary 1N4001 drops ~0.7 V and can leave the
controller browning out under load.

### Why the boost has a shutdown pin

`SHDN` is wired to **D2 (P0.28)** and the firmware holds it **LOW at boot** — the boost is
off until a Bluetooth host actually connects. An adapter sitting idle on your desk charges
its battery instead of running a controller nobody is using.

The firmware also checks whether USB is present: if VBUS is there, the controller runs off
USB and the boost stays off entirely.

**Consequence to expect:** with no host connected, the controller is unpowered and a docked
VMU is blank. That is correct behaviour, not a fault. Pair first, and the controller comes
alive after.

---

## 4. Signal wiring

Two Maple data lines, each with a **10 kΩ pull-up to 3.3 V**:

```
   3.3 V ──┬── 10 kΩ ──┬── XIAO D5 (P0.05) ── cable pin 1, SDCKA (red)
           │           │
           └── 10 kΩ ──┴── XIAO D1 (P0.03) ── cable pin 5, SDCKB (white)
```

Take 3.3 V from the XIAO's `3V3` pin — **not** from the 5 V rail. The pull-ups define the
bus's idle-high level, and pulling them to 5 V puts 5 V into the nRF52840's GPIO.

The Maple bus runs at 2 Mbps and the firmware bit-bangs it against a cycle counter. **Keep
these two wires short and roughly equal in length**, and keep them away from the boost
converter's inductor, which is the noisiest thing on the board. A long, draped, or
inductor-adjacent pair is the usual cause of a controller that enumerates intermittently.

### Sync button

```
   XIAO D10 (P1.15) ──── pushbutton ──── GND
```

Active low, with the nRF's internal pull-up enabled in firmware — **no external resistor**.

### Everything else is on the module

| Function | Pin | |
|---|---|---|
| RGB status LED | P0.26 / P0.30 / P0.06 | onboard, active low |
| Battery ADC | P0.31, gated by P0.14 | onboard divider |
| Charger status | P0.17 | onboard BQ25101 |
| Charge current select | P0.13 | onboard |

Leave all of these alone. The complete assignment for all three boards is in
[pin mapping](../pin_mapping.md).

---

## 5. Check before you power it

Two minutes here saves a dead controller. With **nothing plugged in and no battery
connected**:

1. **Continuity**, end to end, on all five conductors from the cut end to the controller's
   connector.
2. **Shorts between conductors** — probe every adjacent pair. Nothing should beep except
   pins 3 and 4 (ground and sense).
3. **The rail against ground** — no continuity between the +5 V rail and GND. A short here
   is the one that destroys parts.
4. **Diode direction** — in diode-test mode, each diode should conduct from its source
   toward the rail and block the other way.

Then connect the battery *only* and check with the meter:

5. **~3.7 V** across the battery terminals at the board.
6. **~0 V on the 5 V rail** — the boost is held off at boot, so this is what "working"
   looks like before flashing. If you read 5 V here with no firmware loaded, `SHDN` is
   floating or tied high; fix that before plugging in the controller.

---

## 6. Flash it

The XIAO ships with a UF2 bootloader that includes the Nordic SoftDevice, so no debug
probe is needed.

1. Download `pulsar-dreamcast-ble-xiao.uf2` from the
   [Releases page](https://github.com/alwaysEpic/pulsar-dreamcast-ble/releases).
2. Plug the XIAO into USB.
3. **Double-tap the reset button** — quickly, about like a mouse double-click. A drive
   named **`XIAO-BOOT`** appears.
4. Copy the `.uf2` onto it:

   ```bash
   cp pulsar-dreamcast-ble-xiao.uf2 /Volumes/XIAO-BOOT/
   ```

5. The drive disconnects on its own and the board reboots into the firmware. That is the
   whole update path, for this and every future release.

Building from source instead, or flashing over SWD for RTT debug logging, is in
[flash commands](../flash-commands.md). **Release builds are mandatory** — a debug build
misses the Maple timing window and will not talk to the controller.

### First boot — what should happen

| You see | Meaning |
|---|---|
| Green blinks a few times | Firmware started |
| **Solid red** | Searching for the controller |
| **Solid green** | Controller detected and talking |
| Nothing at all | Not running — re-check the flash, then power |

Remember the ordering: on battery with no host connected, the boost is off, so the
controller is unpowered and the light stays red. **Pair first.**

1. On your host, scan for **"Xbox Wireless Controller"** and connect.
2. The boost switches on, the controller powers up, a docked VMU chirps, and the light goes
   green.
3. Test the stick and a few buttons in a gamepad tester before closing anything up.

If it never pairs, hold sync for 2 seconds to re-enter pairing mode. The existing bond is
kept until a new host finishes pairing, so an abandoned window leaves it as it was.

---

## 7. Enclosure

A 3D-printable VMU-shaped shell is in [`hardware/enclosure/`](../../hardware/enclosure/) — see
[`hardware/enclosure/README.md`](../../hardware/enclosure/README.md) for which family fits this build and for
print settings.

The controller shell needs a small trim for cable clearance, and the cable routes through
the VMU slot opening:

<table>
  <tr>
    <td>XIAO seated in the printed shell, USB-C and sync button reachable</td>
    <td>Inside the enclosure: perfboard, boost converter, pull-ups, battery</td>
  </tr>
  <tr>
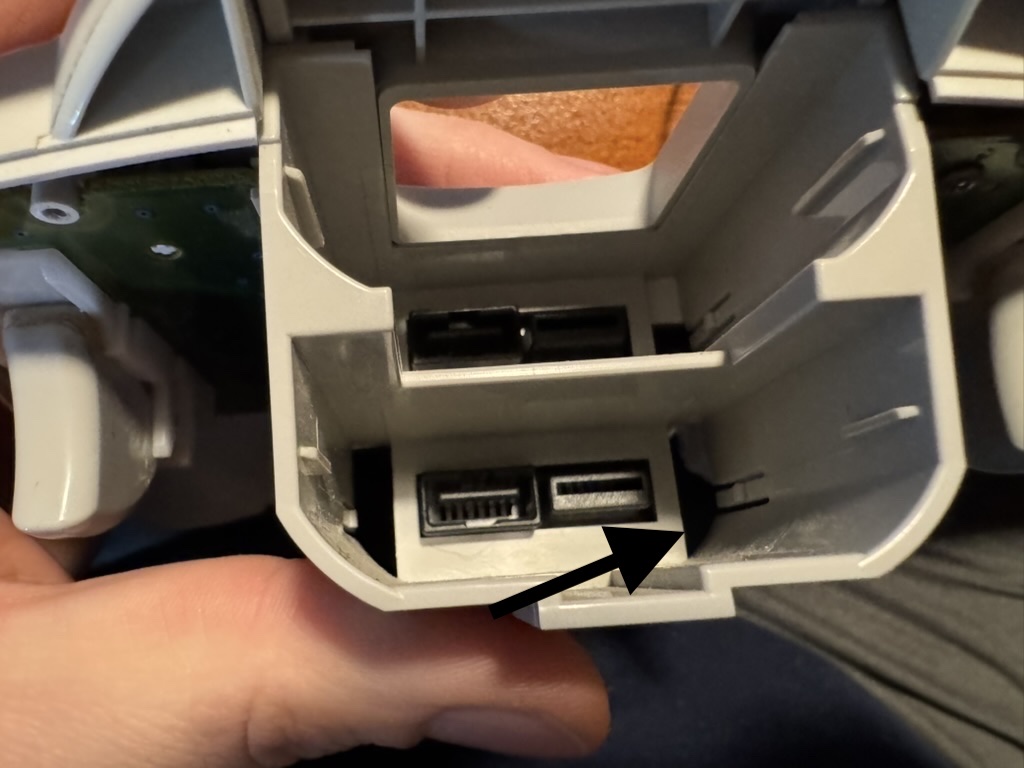
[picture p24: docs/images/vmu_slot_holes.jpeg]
VMU slot with an arrow showing the cable routing
    <td></td>
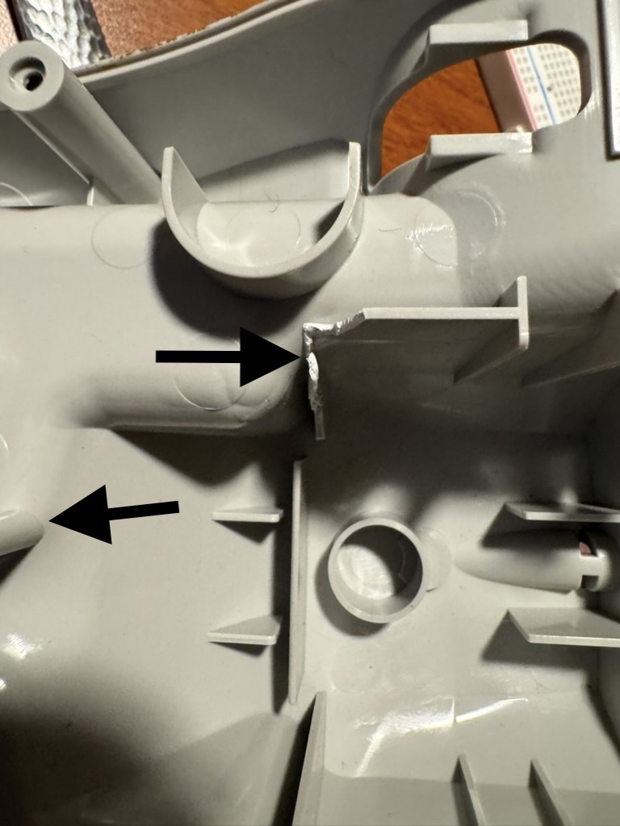
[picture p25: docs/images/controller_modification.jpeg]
Controller shell trimmed for cable clearance
    <td></td>
  </tr>
</table>

Check that the USB-C port and the sync button are both reachable once assembled — they are
your only update path and your only control.

---

## 8. Now use it

- [User guide](../users_guide.md) — buttons, profiles, VMU screens, sleep, LEDs,
  troubleshooting, and which parts are board-specific
- [Remapping from your browser](../users_guide.md#remapping-buttons-from-your-browser) —
  works on this build too
- [Input quality testing](../input_quality_testing.md) — if you want to measure latency and
  packet loss

## Troubleshooting a fresh build

| Symptom | Look at |
|---|---|
| Light stays red forever | Controller has no 5 V. Check the diode direction, then that the boost's `SHDN` reaches D2, then that you are actually connected to a host |
| Never appears in Bluetooth | Firmware not running. Re-flash; confirm you used a **release** `.uf2` |
| Connects, but inputs are erratic or drop | Bus wiring. Shorten SDCKA/SDCKB, keep them clear of the boost inductor, confirm both pull-ups go to **3.3 V** |
| Works on USB, dead on battery | The boost — `SHDN` wiring, or its VIN not on the battery |
| Works on battery, dead on USB | The USB-side diode: backwards, or a non-Schottky part dropping too much |
| VMU blank | Expected until a host connects. If it stays blank after pairing, re-seat it |

More, including host-side issues, in the
[user guide's troubleshooting section](../users_guide.md#troubleshooting).

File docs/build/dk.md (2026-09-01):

# Bench setup — nRF52840-DK

The development path. A Nordic nRF52840-DK, a breadboard, two resistors and a bench supply.
**No soldering and no permanent change to a controller** if you use a Dreamcast extension
cable rather than cutting the controller's own.

This is the board to use when you want to read RTT logs, attach a debugger, or work on the
firmware. It is not a board to play on: it has no battery, no rumble, and it halts where
the other boards sleep.

Other paths: [the hand-wired XIAO build](xiao.md) (the one you can actually play on) ·
[installing an assembled Pulsar v1](pulsar-v1.md).

---

## 1. What you need

| Part | Qty | Notes |
|---|---|---|
| nRF52840-DK | 1 | Built-in J-Link — no separate programmer |
| Dreamcast controller | 1 | First-party is the only one tested |
| Dreamcast extension cable | 1 | Cut *this* instead of the controller's own cable and the controller stays original |
| 10 kΩ resistor | 2 | Bus pull-ups. 4.7 kΩ also works |
| 5 V supply | 1 | **The DK only outputs 3.3 V** — see [§3](#3-the-controller-needs-5-v-from-somewhere-else) |
| Jumper wires | 4+ | |
| Breadboard | 1 | |

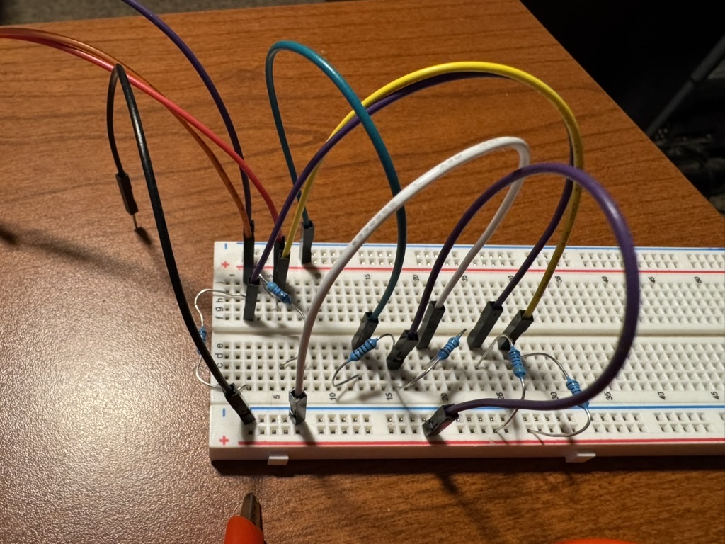
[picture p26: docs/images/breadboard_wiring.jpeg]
DK on a breadboard with pull-ups and the controller cable connected


---

## 2. Wiring

Identify the five conductors **with a multimeter** before connecting anything — the colour
table is the canonical Maple pinout, not a promise about your cable. The full procedure is
in [the XIAO guide §2](xiao.md#2-identify-the-cable-conductors) and applies unchanged here.

| Cable pin | Typical colour | Function | Goes to |
|---|---|---|---|
| 1 | Red | SDCKA | DK **P0.05** |
| 2 | Blue | +5 V | external 5 V supply |
| 3 | Black | GND | DK GND **and** supply ground |
| 4 | Green | Sense (tied to ground) | GND |
| 5 | White | SDCKB | DK **P0.06** |

> **Note the pin difference.** SDCKB is **P0.06** on the DK but **P0.03** on the XIAO. The
> DK's P0.06 is otherwise the UART TX pin; the firmware takes it over.

Both data lines need a **10 kΩ pull-up to 3.3 V**, taken from the DK's 3.3 V rail — not
from the 5 V supply:

```
   3.3 V ──┬── 10 kΩ ──┬── DK P0.05 ── cable pin 1, SDCKA (red)
           │           │
           └── 10 kΩ ──┴── DK P0.06 ── cable pin 5, SDCKB (white)
```

Keep the two bus wires short and roughly equal. At 2 Mbps on a breadboard, long jumpers are
the usual reason a controller enumerates intermittently.

---

## 3. The controller needs 5 V from somewhere else

The DK's VDD rail is **3.3 V**, and a Dreamcast controller will not run on it. Unlike the
other two boards there is no onboard boost and no USB pass-through, so bring 5 V from a
bench supply or a USB breakout.

**Tie the grounds together.** The 5 V supply's ground, the DK's ground, and the cable's
ground (pins 3 and 4) must all be common, or the bus has no shared reference and nothing
works.

Before connecting the controller: check for a short between the 5 V rail and ground, and
confirm you read ~5 V where the blue conductor will land.

---

## 4. Board controls

| Function | Pin | On the kit |
|---|---|---|
| Sync button | P0.25 | **Button 4** |
| Sync LED | P0.13 | LED1 |
| Status | P0.14–P0.16 | LED2–LED4 |

Status reads differently here than on the other boards: searching is **LED4**, connected is
**LED3**, where the XIAO uses one RGB LED for both.

---

## 5. Build and flash

The DK is the **default** build target and always includes RTT logging.

```bash
rustup target add thumbv7em-none-eabihf
cargo install cargo-embed
```

The Nordic S140 SoftDevice v7.3.0 must be flashed once before the application
([download](https://www.nordicsemi.com/Products/Development-software/S140/Download)):

```bash
nrfjprog --eraseall
nrfjprog --program s140_nrf52_7.3.0_softdevice.hex --verify
```

Then, from the repo root:

```bash
cargo embed --release
```

`cargo embed` flashes and opens the RTT terminal. **`--release` is mandatory** — a debug
build misses the Maple timing window outright and will never talk to the controller. To
attach to a board that is already running:

```bash
probe-rs attach --chip nRF52840_xxAA \
  target/thumbv7em-none-eabihf/release/pulsar-dreamcast-ble
```

More recipes — GDB, panic-log readback, recovery from a locked chip — are in
[flash commands](../flash-commands.md).

### First boot

LED4 lights while the firmware looks for the controller; LED3 once it is talking. Scan for
**"Xbox Wireless Controller"** on your host and connect.

Unlike Pulsar v1, the DK powers the controller as soon as the rail is up — there is no
boost to gate, so you do not have to pair first.

---

## 6. What behaves differently here

Worth knowing before you file a bug against the DK:

- **It halts instead of sleeping.** The sleep paths that put the other boards into System
  Off stop the DK where it stands. Reset to recover.
- **No battery, no gauge.** Battery reporting is absent, not zero — hosts show no battery
  level.
- **No rumble.** There is no motor output on the kit.
- **The OTA update gesture does nothing useful.** Wireless update is a Pulsar v1 feature;
  reflash the DK with the probe.
- **RTT is always on**, which costs a little timing margin the production builds do not
  pay. That is deliberate for a bench board.

---

## 7. Working on the firmware

```bash
./scripts/check.sh dk    # after every change  — protocol tests + clippy
./scripts/ci.sh          # before every commit — fmt, all boards, all release builds
```

`ci.sh` also runs `check_timing_invariants.sh` against each built ELF, which reads the
compiled binary and fails if the pinned RX sampling loop has moved or lost its alignment.
If you touch anything under `src/maple/`, expect that check to have an opinion.

Background reading:

- [Maple bus protocol](../maple_bus_protocol.md) — the wire format, consolidated
- [Learnings](../learnings.md) — what 2 Mbps bit-banged GPIO on this part actually costs
- [Input quality testing](../input_quality_testing.md) — measuring latency and packet loss
- [Test plan](../test_plan.md) — the full adapter test plan

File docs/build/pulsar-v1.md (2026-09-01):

# Installing Pulsar v1 in a Dreamcast controller

> Markdown copy of <https://pulsar.alwaysagog.com/install> as of 2026-09-01.
> **The site is canonical** — if the two disagree, the site is right. This copy exists so
> the instructions travel with the repo and stay diffable against the page.

Pulsar replaces the original cable inside a first-party Dreamcast controller. Work through
the steps in order and **test the board before making the one permanent change** to the
back shell.

| | |
|---|---|
| Fasteners | 6 screws |
| Tool | Small Phillips |
| Modification | 1 cable guard |

This page is for an assembled **Pulsar v1**. Building the adapter yourself is a different
path — see [the XIAO build](xiao.md).

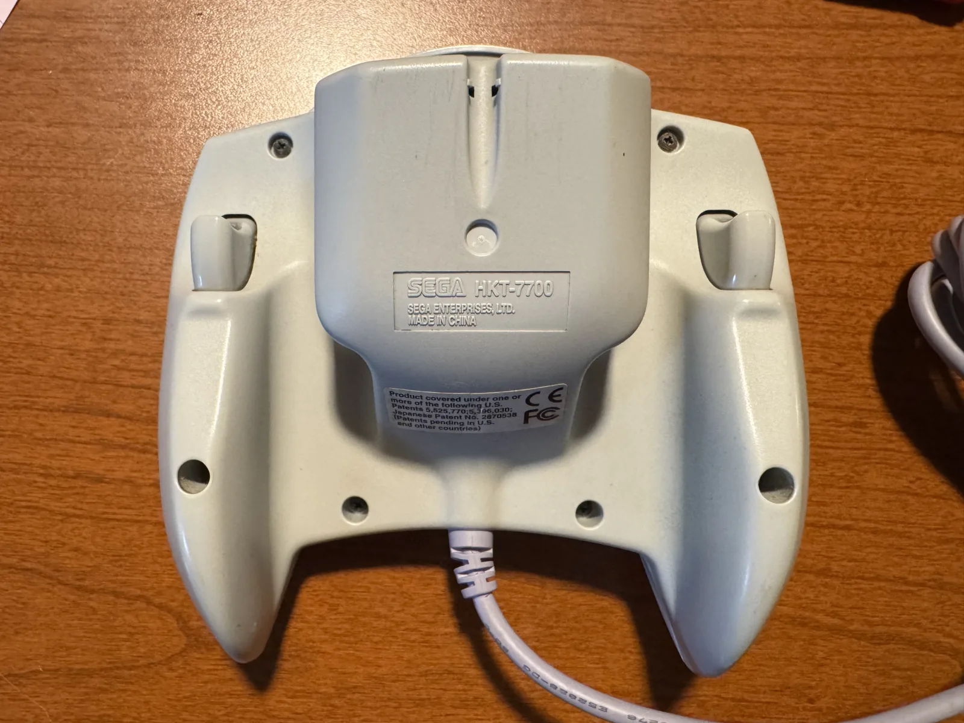
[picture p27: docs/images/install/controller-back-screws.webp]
Back of a Dreamcast controller with its six screw positions visible


Start with the controller unplugged and face-down on a soft surface.

## Before you open it

**Set up a clear work area.**

- Disconnect the controller from the Dreamcast.
- Set aside the six screws where they cannot roll away.
- Have Pulsar and the included 3D-printed cable cover within reach.

## 01 · Open — remove the six back screws

Remove all six Phillips screws from the back of the controller. Lift the back shell
straight up and set it beside the controller. Keep the front half face-down so the buttons
stay in place.

Two screws sit near the cable; four sit around the grips.

## 02 · Disconnect — unplug the original cable

Find the white cable connector beside the accessory slots. Grip the cable close to the plug
and pull it as straight out of the socket as possible. Lift the original cable and its
strain relief out of the controller.

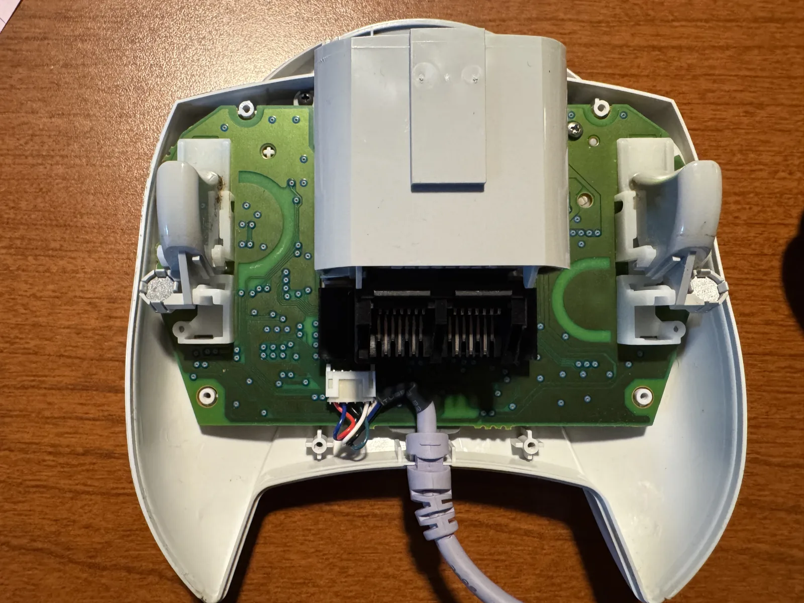
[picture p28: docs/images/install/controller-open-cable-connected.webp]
Open Dreamcast controller with its original cable still connected


*The original cable before removal.*

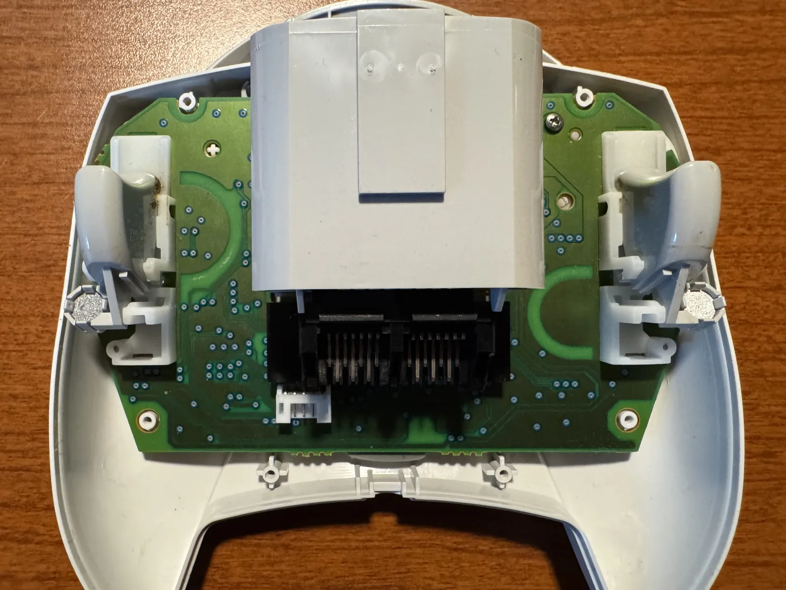
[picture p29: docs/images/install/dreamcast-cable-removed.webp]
The controller with its original cable lifted out


## 03 · Fit — seat Pulsar in the second slot

Slide Pulsar into the second accessory slot. Route its cable through the right-hand opening
in the bottom of the controller, following the path in the photo, then press its white plug
into the controller connector until it is fully seated.

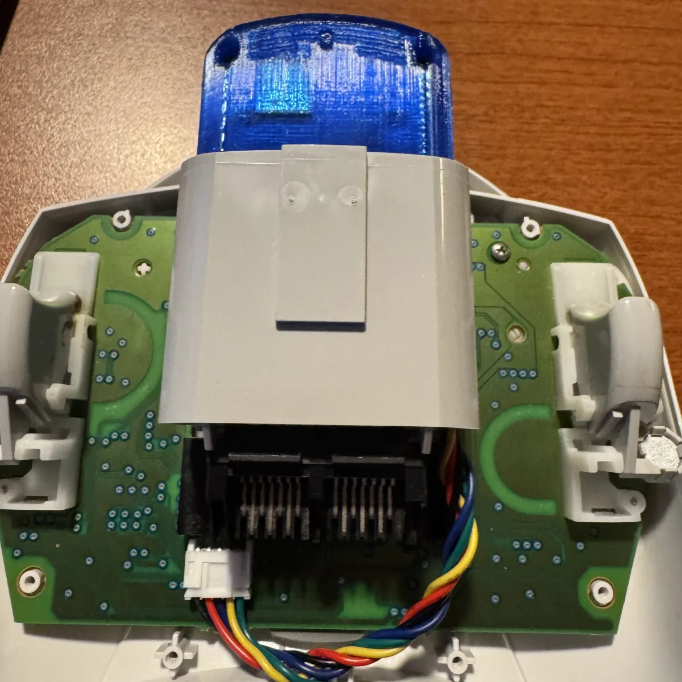
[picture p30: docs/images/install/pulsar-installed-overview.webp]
Pulsar seated in the second accessory slot with its cable routed inside the controller


*Second slot, cable routed to the right-hand opening.*

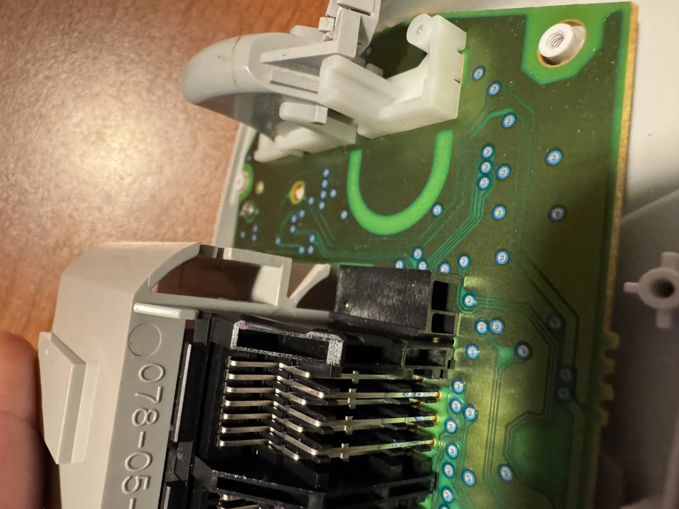
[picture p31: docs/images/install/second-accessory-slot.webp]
Close view of the empty second accessory slot inside the controller


*Use the second of the two accessory slots.*

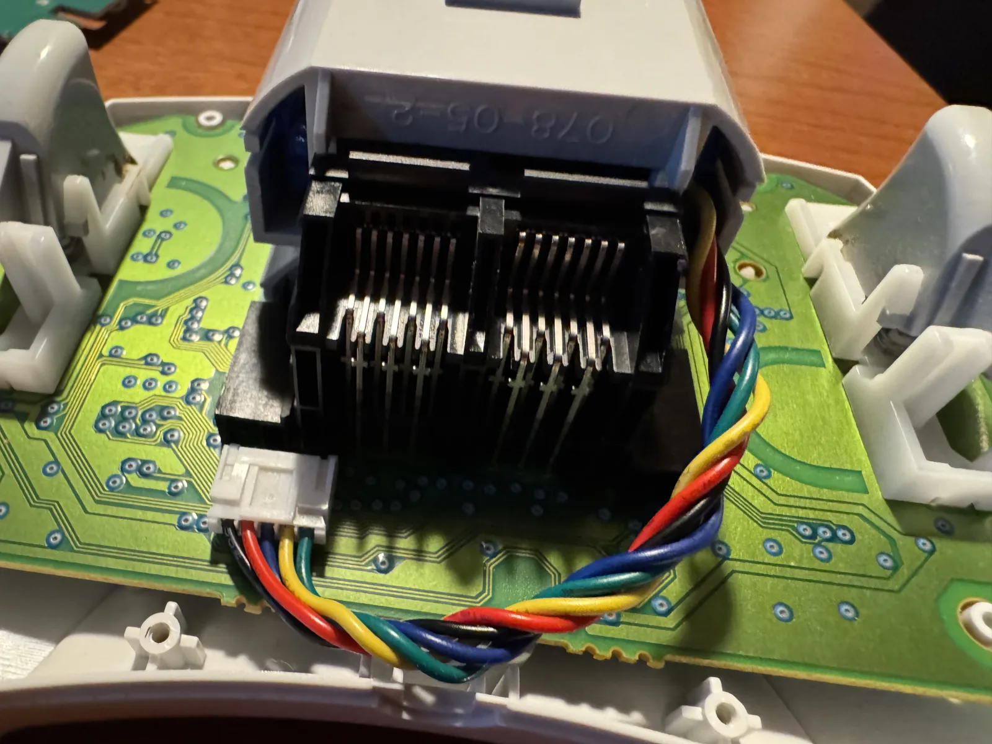
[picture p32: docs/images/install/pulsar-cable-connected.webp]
Close view of the Pulsar cable plugged into the controller board


*Match the plug orientation shown here.*

## Checkpoint — pair and test before changing the shell

Press Sync once to wake Pulsar. Then press and hold Sync for about 3 seconds, until the
status LED starts blinking rapidly. Open Bluetooth settings on the device you want to use,
find **Xbox Wireless Controller** and connect. Before closing the shell, verify the analog
stick and a few buttons in a game or controller test.

If Pulsar does not wake or appear, reseat the white connector now, while everything is
still open.

> Pulsar v1 only switches on the controller's 5 V supply once a Bluetooth host is
> connected, so an idle adapter charges instead of running the controller. Until you pair,
> the controller is unpowered and the VMU is blank — that is normal. See
> [the owner's manual](../pulsar_v1_manual.md) for the full behaviour.

## 04 · Permanent step — snap off the matching cable guard

On the inside of the back shell, locate the small plastic guard that lines up with the side
where Pulsar's cable exits. Press the guard sideways with your fingers; it should break away
cleanly at its thin joints.

> **This permanently changes the shell. Check the cable side twice before you snap
> anything.**

**Before** — the cable guard is still present.

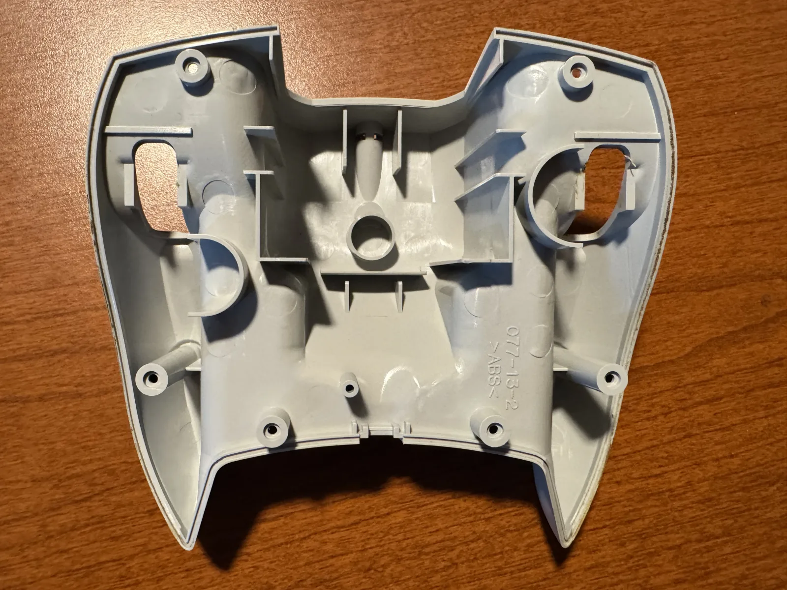
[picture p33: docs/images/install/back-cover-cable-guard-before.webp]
Inside of the controller back shell before the cable guard is removed


**After** — the opening after a clean break.

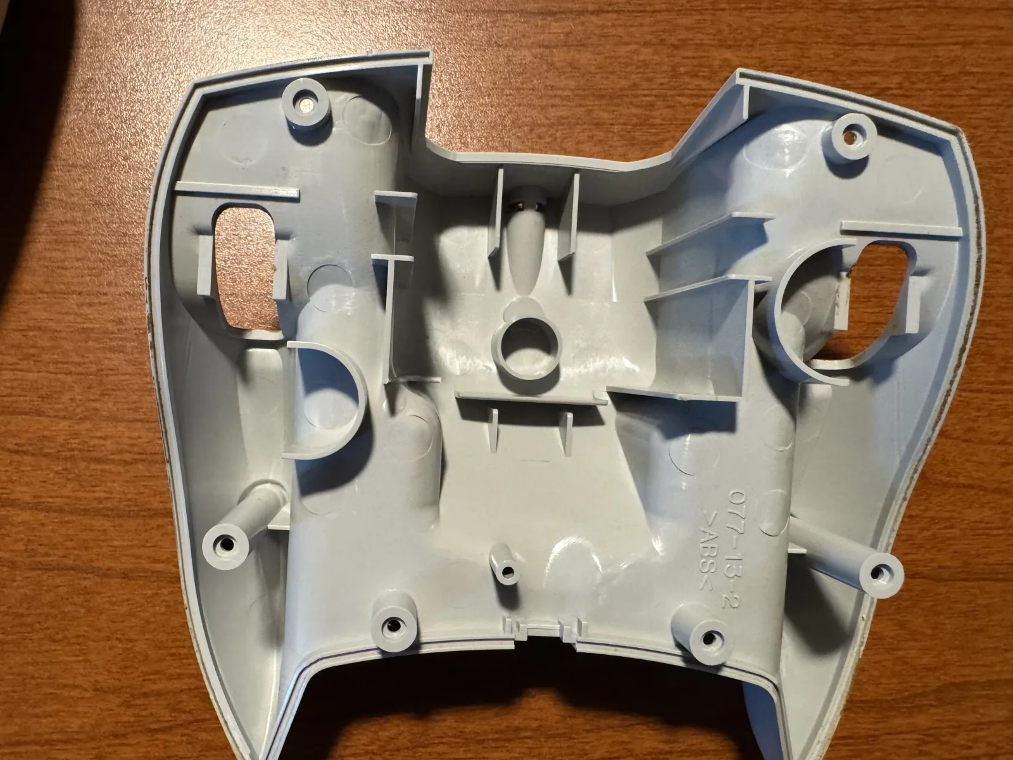
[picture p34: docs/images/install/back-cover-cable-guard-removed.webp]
Inside of the controller back shell after the matching cable guard is removed


## 05 · Protect — add the cable cover

Fit the 3D-printed cable cover into the opening around the Pulsar cable. Make sure it is
seated against the shell and that the cable lies naturally without a sharp bend.

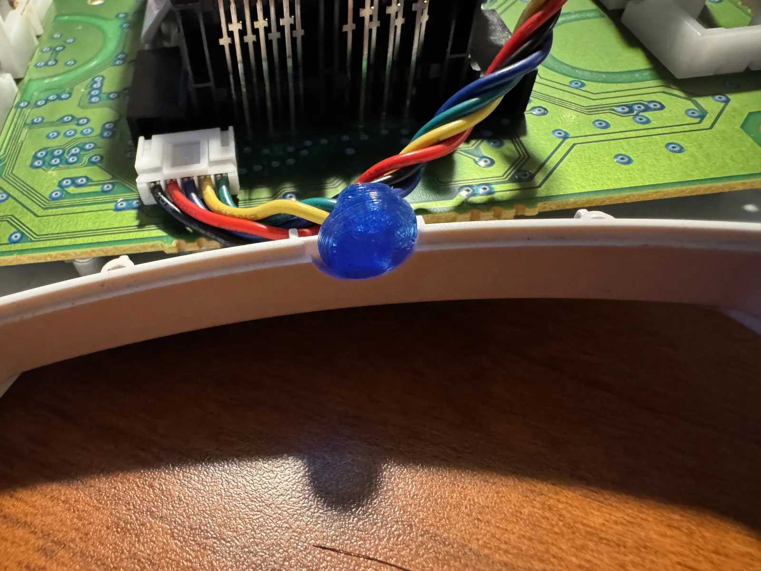
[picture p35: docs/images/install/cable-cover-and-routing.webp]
Blue 3D-printed cable cover fitted around the Pulsar cable


*The cable cover protects the new exit from the shell edge.*

## 06 · Close — keep the cable clear of the standoff

Lower the back shell into place while watching the screw standoff nearest the cable. The
standoff must land **beside** the cable, never on top of it. The shell should sit flush
without force; if it does not, lift it and move the cable before trying again.

> **No pinching.** A trapped cable can be damaged when the screw is tightened. Do not force
> the shell shut.

## 07 · Finish — replace the six screws

Install all six screws and tighten them until snug. Do not overtighten into the old plastic.

Turn the controller over, wake Pulsar with Sync and enjoy your gaming.

## Next

- [Owner's manual](../pulsar_v1_manual.md) — buttons, LEDs, VMU, charging, sleep
- [User guide](../users_guide.md) — the same ground across all three boards
- [Updating the firmware](../pulsar_v1_manual.md#9-updating-the-firmware) — wireless, from your browser

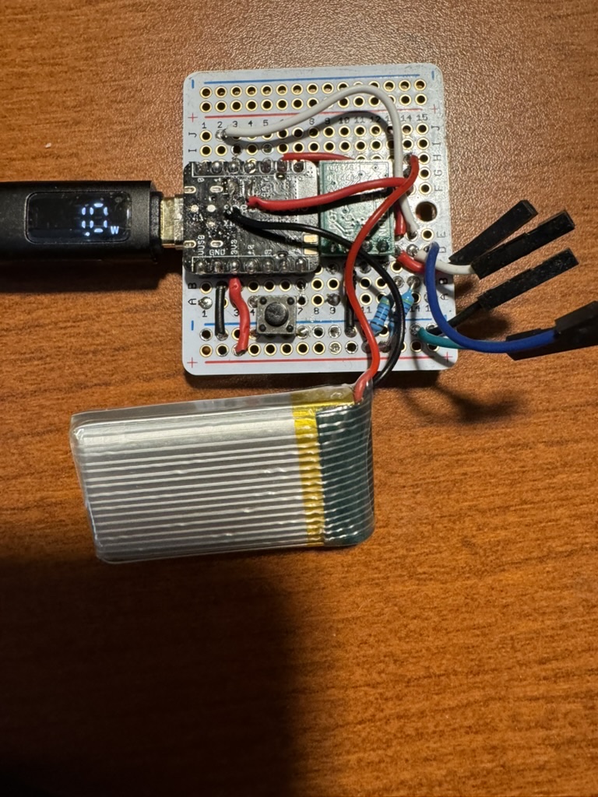
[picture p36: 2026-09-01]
docs/images/larger_wiring_example.jpeg

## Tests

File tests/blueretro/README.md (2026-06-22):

# BlueRetro mapping harness

Software regression test for how a **BlueRetro** adapter maps our controller —
no nRF hardware required. It exists to catch the class of bug in
[issue #2](https://github.com/alwaysEpic/pulsar-dreamcast-ble/issues/2)
(`START`/`X`/`Y` landing on the wrong Dreamcast functions) *before* flashing.

## How it works

BlueRetro ships a QEMU + pytest harness. Their firmware is built with a `qemu`
config and run under `qemu-system-xtensa -machine esp32`; a websocket
(`injector.py`) lets a test hand the firmware a HID report descriptor + report
bytes and read back every pipeline stage (`wireless_input` → `generic_input` →
`mapped_input` → `wired_output`).

`pytest_pulsar_dreamcast.py`:

1. advertises the name our `PROFILE_XBOX` uses (`Xbox Wireless Controller`),
2. sends BlueRetro the exact `HID_REPORT_DESCRIPTOR_XBOX` our firmware serves,
3. feeds the exact 16-byte reports `GamepadReport::to_bytes_ms` produces for each
   physical button,
4. asserts each one decodes to the same BlueRetro-generic button a genuine Xbox
   One S BLE controller produces (BlueRetro's own `device_data/xbox.py`).

If our descriptor doesn't parse the way the real Xbox descriptor does, the
buttons mis-map here exactly as they do on a real Dreamcast.

## Fixtures are generated, not hand-written

`fixtures.json` (descriptor + per-button report bytes) is emitted from the Rust
source by `maple-protocol/tests/blueretro_fixtures.rs`. That test runs in
`scripts/ci.sh`, so editing the descriptor or serializer without regenerating
the fixtures fails CI. Regenerate after an intentional change:

```sh
(cd maple-protocol && UPDATE_FIXTURES=1 cargo test --test blueretro_fixtures)
```

## Running it

In CI it runs via `.github/workflows/blueretro-pytest.yml`. Locally, use
BlueRetro's container (heavy; nested xtensa emulation is slow on Apple Silicon):

```sh
git clone --recursive https://github.com/darthcloud/BlueRetro
cd BlueRetro && git checkout e1a9831a875f5313a923160a1379a7ebbfaa2b11

docker run --rm -it -v "$PWD:/br" -v "/path/to/pulsar:/pulsar" \
  ghcr.io/darthcloud/idf-blueretro:v5.5.0_2024-12-02_gcovr bash -c '
    cd /br && . "$IDF_PATH/export.sh" && git config --global --add safe.directory "*"
    echo "harness qemu" > version.txt && cp configs/dbg/qemu sdkconfig && idf.py build
    cp /pulsar/tests/blueretro/pytest_pulsar_dreamcast.py /pulsar/tests/blueretro/fixtures.json tests/
    (cd build && esptool.py --chip esp32 merge_bin --fill-flash-size 4MB -o flash_image.bin @flash_args)
    qemu-system-xtensa -machine esp32 -drive file=build/flash_image.bin,if=mtd,format=raw \
      -serial file:serial_log.txt -serial file:gcov_data.gcfn -display none \
      -nic user,model=open_eth,id=lo0,hostfwd=tcp:127.0.0.1:8001-:80 -daemonize
    pip install --quiet websocket-client pytest numpy
    pytest tests/pytest_pulsar_dreamcast.py'
```

## Tests

- `test_harness_control_reference_xbox` — **baseline.** Runs the button assertions
  against BlueRetro's own reference Xbox descriptor (imported from their suite).
  Must be green; if it's red the harness is wired wrong, not our descriptor.
- `test_pulsar_xbox_buttons_mapping` — every face/shoulder/system button (the issue).
- `test_pulsar_xbox_dpad_mapping` — hat switch → D-pad directions (`hat_to_ld_btns`).
- `test_pulsar_xbox_axes_scaling` — sticks (unsigned 0-65535, center 32768) and
  triggers (0-1023); guards the signed-`Logical Maximum` stick regression and
  confirms our Rx/Ry + Z/Rz usages land on the expected axes.
- `test_pulsar_generic_buttons_probe` — `xfail`-tolerant characterization of the Generic
  profile (contiguous layout, Steam/PC target) on BlueRetro. XFAIL = mis-maps as
  expected; XPASS = it happens to work, revisit.

All Xbox assertions are at the `generic_input` stage (descriptor-parse correctness,
system-independent). A red Xbox test means issue #2 is reproduced — the harness
working as intended; it goes green once the descriptor is fixed.

## Scope / TODO

- BlueRetro is pinned by commit in the workflow; bump deliberately and re-verify
  against the matching container tag.
- The Generic profile's real target (Steam Deck / kernel / xpadneo) is a *different*
  parser, better covered by a `hid-tools`/`uhid` virtual-device layer (future).
- No `dc.py` exists upstream, so DC *wired output* isn't modelled — we assert at
  `generic_input`, which is where mapping correctness is decided.

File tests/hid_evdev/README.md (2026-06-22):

# HID descriptor → mapping tests

Proves our two BLE gamepad profiles (Xbox `0x02E0`, Generic/Dreamcast `0x0B20`)
keep a stable, correct HID layout and map the way real hosts expect. Complements the existing
Rust byte-golden (`maple-protocol/tests/blueretro_fixtures.rs`) and the BlueRetro
QEMU harness (`tests/blueretro/`).

Both layers consume the **same** Rust-generated `tests/blueretro/fixtures.json`
(descriptors + per-button report bytes) — one source of truth.

## Two layers

| File | Proves | Runs on |
|---|---|---|
| `test_descriptor_layout.py` | layout doesn't regress; the Xbox profile matches the real Xbox raw descriptor; the Generic profile's divergence is documented (issue #7) | **any OS** (pure-Python `hid-tools` parser) |
| `test_evdev_mapping.py` | the real Linux kernel maps each profile to the right buttons/axes, and LT/RT are independent axes | **Linux only** (UHID + libevdev) |

`reference/xbox_one_s_real.md` documents the ground-truth real-controller layout
the descriptors are measured against.

## Run locally

```bash
cd tests/hid_evdev
uv venv .venv && uv pip install --python .venv/bin/python -r requirements.txt
.venv/bin/python -m pytest test_descriptor_layout.py -v
```

The evdev layer needs Linux (`/dev/uhid` + libevdev); on macOS/Windows it skips.
On Linux:

```bash
uv pip install --python .venv/bin/python -r requirements-linux.txt
sudo modprobe uhid
sudo .venv/bin/python -m pytest test_evdev_mapping.py -v
```

CI runs both (`.github/workflows/hid-evdev.yml`).

## Key finding (issue #7)

`test_xbox_profile_matches_real_xbox_raw_layout` /
`test_generic_profile_diverges_from_real_xbox_raw_layout`: the **real** Xbox One S
puts the right stick on `Z`/`Rz` and the triggers on the Simulation page
(`Brake`/`Accelerator`). The **Xbox** profile matches this; the **Generic** profile
ships the *xpadneo-remapped* layout (right stick `Rx`/`Ry`, triggers `Z`/`Rz`).
The Generic profile serves this layout under the **recognized Xbox One S 1708 BLE
identity** (Microsoft 0x045E / PID **0x0B20**, post-FW-5.11). An earlier neutral
pid.codes PID `0x1209/0xDC01` was tried to sidestep Xbox-family identity, but it
regressed the browser Gamepad API on macOS: Apple's GameController framework
seized the device but did not surface it to browsers. The current profile keeps
`0x0B20` for host recognition and relies on these tests to guard the intended
contiguous descriptor/layout. See plan Story 6 for the remaining alignment
question.

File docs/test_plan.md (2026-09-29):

# Dreamcast BLE Adapter -- Test Plan

Comprehensive test plan for the Dreamcast-to-BLE controller adapter, across all three supported boards.

**Revision:** 2.0
**Date:** 2026-08-07

## Target hardware

| Board | Build | Hardware under test |
|---|---|---|
| **Pulsar v1** | `board-pulsarv1` | Designed carrier with a XIAO nRF52840 mounted: IP5306 charge/boost/gauge, 5× WS2812 status bar, ERM rumble motor, LiPo cell |
| **XIAO** | `board-xiao` | Seeed XIAO nRF52840 + boost converter + BQ25101 charger + LiPo cell, on perfboard or breadboard |
| **DK** | `board-dk` | Nordic nRF52840-DK. Bench only: no battery, no boost rail, no gauge, no sleep |

**Board applicability.** Unmarked cases run on all three. Cases that exercise hardware only
some boards have are marked in their title — `(Pulsar v1)`, `(XIAO)`, `(XIAO / Pulsar v1)`,
`(DK)`. A case marked for a board the DUT isn't is not a failure; it is not applicable.

Release builds are mandatory on every board — debug builds miss the Maple Bus timing window,
so a failure on a debug build tells you nothing.

---

## Equipment List

| Item | Purpose |
|---|---|
| Pulsar v1 adapter | Device under test (DUT) — retail configuration |
| XIAO nRF52840 adapter (DIY build) | Device under test (DUT) — hand-wired configuration |
| nRF52840-DK | Device under test (DUT) — bench configuration, RTT console |
| Dreamcast controller (OEM) | Input source |
| Dreamcast controller (third-party, if available) | Compatibility |
| LiPo cell (1000mAh) | Battery power |
| Multimeter (DC voltage, current) | Voltage/current measurements |
| USB power meter (e.g., ChargerLAB KM003C) | USB draw, charge current |
| Laptop with Bluetooth (macOS/Windows/Linux) | BLE host, RTT console |
| Android phone with Bluetooth | BLE host, compatibility |
| iOS device (iPhone/iPad) | BLE host, compatibility |
| iBlueControlMod BLE receiver (or BlueRetro) | Target receiver, compatibility |
| nRF Connect app (iOS/Android) | BLE service inspection |
| Gamepad Tester website (gpadtester.com) | HID input validation |
| J-Link / SWD debugger | RTT logging, reflash |
| Stopwatch / timer app | Timeout verification |
| Second 2.4 GHz device (Wi-Fi router, microwave) | Interference testing |
| USB-C cable | Charging, USB power source |
| Bench power supply (optional) | Controlled voltage testing |

---

## 1. Functional Testing -- Controller Inputs

### FUNC-01: Button Press Detection (ABXY)

| Field | Value |
|---|---|
| **Steps** | 1. Power on DUT, connect via BLE to laptop. 2. Open gpadtester.com. 3. Press and release each face button (A, B, X, Y) individually. 4. Verify each registers as a distinct button on the tester. |
| **Expected** | Each button maps to a unique HID button index. Press shows 1, release shows 0. No ghost presses. |
| **Pass/Fail** | All 4 buttons register correctly with no crosstalk. |
| **Equipment** | DUT, Dreamcast controller, laptop, gpadtester.com |

### FUNC-02: Start Button

| Field | Value |
|---|---|
| **Steps** | 1. Connect DUT to host. 2. Press Start. 3. Verify it maps to the correct HID button. |
| **Expected** | Start registers as a single button press/release. |
| **Pass/Fail** | Button registers on press and clears on release. |
| **Equipment** | DUT, Dreamcast controller, laptop, gpadtester.com |

### FUNC-03: D-Pad (Hat Switch)

| Field | Value |
|---|---|
| **Steps** | 1. Connect DUT. 2. Press each D-pad direction individually (Up, Down, Left, Right). 3. Press diagonal combinations (Up+Left, Up+Right, Down+Left, Down+Right). 4. Release and verify neutral. |
| **Expected** | Hat switch reports values 1-8 for 8 directions. Neutral reports null (0). |
| **Pass/Fail** | All 8 directions correct, null on release. No stuck directions. |
| **Equipment** | DUT, Dreamcast controller, laptop, gpadtester.com |

### FUNC-04: Analog Stick -- Center Position

| Field | Value |
|---|---|
| **Steps** | 1. Connect DUT. 2. Leave stick untouched. 3. Read Left Stick X and Y values on tester. |
| **Expected** | Both axes report approximately center (32768 of 0-65535 range, or 0.0 on normalized tester). |
| **Pass/Fail** | Stick reads within 5% of center when idle. |
| **Equipment** | DUT, Dreamcast controller, laptop, gpadtester.com |

### FUNC-05: Analog Stick -- Full Range

| Field | Value |
|---|---|
| **Steps** | 1. Connect DUT. 2. Move stick to full extent in all 4 cardinal directions. 3. Move stick in a full circle. 4. Check min/max values reported. |
| **Expected** | Full deflection approaches 0 and 65535 on each axis. Circular motion traces a smooth circle on tester visualization. |
| **Pass/Fail** | Full range achieved on both axes. No dead zones > 10% at extremes. No axis inversion. |
| **Equipment** | DUT, Dreamcast controller, laptop, gpadtester.com |

### FUNC-06: Analog Stick -- No "Flower" Pattern

| Field | Value |
|---|---|
| **Steps** | 1. Connect DUT. 2. Move stick slowly in a full circle. 3. Observe the XY plot on the gamepad tester. |
| **Expected** | Trace shows a circle, not a diamond/flower shape (which would indicate signed/unsigned mismatch). |
| **Pass/Fail** | Circular input produces circular output. |
| **Equipment** | DUT, Dreamcast controller, laptop, gpadtester.com |

### FUNC-07: Left Analog Trigger

| Field | Value |
|---|---|
| **Steps** | 1. Connect DUT. 2. Slowly press left trigger from released to full. 3. Release slowly. |
| **Expected** | Value smoothly ramps from 0 to 1023 (10-bit). Released = 0. |
| **Pass/Fail** | Smooth ramp, no jumps > 5% between samples. 0 at rest, near-max at full pull. |
| **Equipment** | DUT, Dreamcast controller, laptop, gpadtester.com |

### FUNC-08: Right Analog Trigger

| Field | Value |
|---|---|
| **Steps** | Same as FUNC-07 but for right trigger. |
| **Expected** | Same as FUNC-07. |
| **Pass/Fail** | Same as FUNC-07. |
| **Equipment** | DUT, Dreamcast controller, laptop, gpadtester.com |

### FUNC-09: Simultaneous Input Combinations

| Field | Value |
|---|---|
| **Steps** | 1. Connect DUT. 2. Hold A + B + left trigger + D-pad Up simultaneously. 3. Hold all face buttons + both triggers + stick deflected. 4. Release all. |
| **Expected** | All held inputs report simultaneously. No dropped inputs. All clear on release. |
| **Pass/Fail** | All inputs register concurrently, all clear on full release. |
| **Equipment** | DUT, Dreamcast controller, laptop, gpadtester.com |

### FUNC-10: Rapid Button Mashing

| Field | Value |
|---|---|
| **Steps** | 1. Connect DUT. 2. Rapidly press and release A button for 10 seconds as fast as possible. 3. Observe tester for missed presses or stuck states. |
| **Expected** | Presses and releases alternate with no stuck state. At ~60 Hz poll (~16-17 ms loop), presses shorter than one poll cycle will be missed -- this is a known limitation matching the Dreamcast controller's native poll rate, not a bug. |
| **Pass/Fail** | No stuck buttons. No phantom presses after stopping. Missed rapid presses are acceptable. |
| **Known Limitation** | Very rapid presses (~<16ms) may be missed due to 60Hz Maple Bus poll rate. This matches original Dreamcast hardware behavior. |
| **Equipment** | DUT, Dreamcast controller, laptop, gpadtester.com |

### FUNC-11: Right Stick (Hardcoded Center)

| Field | Value |
|---|---|
| **Steps** | 1. Connect DUT. 2. Move left stick around. 3. Observe Right Stick X/Y on tester. |
| **Expected** | Right stick always reports 32768/32768 (center) since Dreamcast has only one analog stick. |
| **Pass/Fail** | Right stick values remain constant at center. |
| **Equipment** | DUT, Dreamcast controller, laptop, gpadtester.com |

---

## 2. BLE Testing

### BLE-01: Initial Pairing (No Bond)

| Field | Value |
|---|---|
| **Steps** | 1. Flash DUT with cleared flash — the sync gesture no longer clears a bond. 2. Power on. 3. Observe LED enters sync mode (blink) automatically. 4. Open Bluetooth settings on host, scan for "Xbox Wireless Controller". 5. Pair. |
| **Expected** | DUT auto-enters sync mode when no bond exists. Host discovers device, pairing completes with JustWorks. LED goes solid on connect. |
| **Pass/Fail** | Pairing completes within 30 seconds. LED behavior matches spec. |
| **Equipment** | DUT, laptop or phone |

### BLE-02: Bond Persistence Across Power Cycles

| Field | Value |
|---|---|
| **Steps** | 1. Pair DUT with host (BLE-01). 2. Power off DUT (remove battery). 3. Wait 10 seconds. 4. Power on DUT. 5. Observe reconnection without re-pairing. |
| **Expected** | DUT reconnects to previously bonded host without requiring new pairing. LED shows reconnecting state then solid on connect. |
| **Pass/Fail** | Automatic reconnection within 10 seconds of power-on. |
| **Equipment** | DUT, laptop or phone |

### BLE-03: Sync Mode Entry (2-Second Hold)

| Field | Value |
|---|---|
| **Steps** | 1. Power on DUT with existing bond. 2. Hold sync button for 2 seconds. 3. Observe LED behavior (slow blink -> fast blink at 2s). 4. Release button. |
| **Expected** | After 2s hold, DUT enters sync mode (discoverable), LED blinks, and **retains the stored bond**. RTT log shows "SYNC: Entering pairing mode (60s)". |
| **Pass/Fail** | New host can discover and pair; the stored bond is replaced only once that pairing completes. Letting the window lapse returns the DUT to the original host. |
| **Equipment** | DUT, SWD debugger (RTT), host device |

### BLE-04: Sync Mode Timeout (60 Seconds)

| Field | Value |
|---|---|
| **Steps** | 1. Enter sync mode (BLE-03). 2. Do NOT pair any device. 3. Wait 60 seconds. 4. Observe behavior. |
| **Expected** | After 60s, if no bond exists, DUT enters System Off (XIAO). RTT shows "BLE: No bond after sync timeout, entering System Off". |
| **Pass/Fail** | DUT sleeps after 60s timeout. Current draw drops to < 10 uA. |
| **Equipment** | DUT, stopwatch, multimeter (optional), SWD debugger |

### BLE-05: Reconnection After Host Disconnect

| Field | Value |
|---|---|
| **Steps** | 1. Pair and connect DUT. 2. On host, turn off Bluetooth. 3. Wait 5 seconds. 4. Turn Bluetooth back on. 5. Observe reconnection. |
| **Expected** | DUT detects disconnect, enters reconnecting state (LED off), automatically reconnects when host reappears. |
| **Pass/Fail** | Reconnection completes within 15 seconds of host Bluetooth re-enable. |
| **Equipment** | DUT, laptop or phone |

### BLE-06: Reconnect Timeout -- System Off (XIAO)

| Field | Value |
|---|---|
| **Steps** | 1. Pair DUT with host. 2. Turn off host Bluetooth. 3. Start a stopwatch. 4. Monitor RTT for "BLE: Reconnect timeout, entering System Off". 5. Verify System Off entered within ~60s (SLEEP_TIMEOUT_MS). 6. Press sync button to wake — verify fresh boot and reconnect. |
| **Expected** | DUT enters System Off after ~60s reconnect timeout. RTT shows timeout message. Current draw drops to < 10 uA. |
| **Pass/Fail** | System Off entered between 50-70s after disconnect. Wake via sync button starts fresh boot. |
| **Regression Note** | Previously failed: advertising had no timeout, so `advertise()` blocked indefinitely and the sleep check never ran. Fixed by adding 10s advertising timeout to reconnect modes so the loop iterates and checks elapsed time. |
| **Equipment** | DUT, stopwatch, multimeter (optional), SWD debugger |

### BLE-07: Connection Parameter Negotiation

| Field | Value |
|---|---|
| **Steps** | 1. Connect DUT to host. 2. Monitor RTT output for connection parameter update. 3. Optionally use nRF Connect to verify connection parameters. |
| **Expected** | Connection interval negotiated to 7-9 units (8.75-11.25ms). Slave latency = 0. Supervision timeout = 400 (4000ms). RTT shows no "Conn param update failed" message. |
| **Pass/Fail** | Parameters accepted by host (no error logged). |
| **Equipment** | DUT, SWD debugger, nRF Connect app (optional) |

### BLE-08: GATT Service Discovery

| Field | Value |
|---|---|
| **Steps** | 1. Connect to DUT using nRF Connect app. 2. Discover all services. 3. Verify presence of HID (0x1812), Device Info (0x180A), Battery (0x180F). 4. Read HID Report Map characteristic. |
| **Expected** | All three services present. Report Map contains the Xbox One S BLE HID descriptor. HID Info reads 0x11 0x01 0x00 0x03. PnP ID shows VID=0x045E, PID=0x02E0. |
| **Pass/Fail** | All services and characteristics discoverable and readable. |
| **Equipment** | DUT, nRF Connect app on phone |

### BLE-09: HID Report Notifications

| Field | Value |
|---|---|
| **Steps** | 1. Connect DUT via nRF Connect. 2. Enable notifications on HID Report characteristic (0x2A4D). 3. Press buttons on Dreamcast controller. 4. Observe notification data. |
| **Expected** | Notifications arrive at ~60 Hz (host-capped; ~15 ms connection interval on macOS). Button presses change the appropriate bytes in the 16-byte report. |
| **Pass/Fail** | Notifications are received. Data changes correspond to physical input. |
| **Equipment** | DUT, Dreamcast controller, nRF Connect app |

### BLE-10: Device Name -- Xbox Mode (Default)

| Field | Value |
|---|---|
| **Steps** | 1. Ensure default name preference (or toggle to Xbox). 2. Scan from host. |
| **Expected** | Device advertises as "Xbox Wireless Controller". |
| **Pass/Fail** | Correct name visible in scan results. |
| **Equipment** | DUT, host device |

### BLE-11: Device Name -- Dreamcast Mode (Triple-Press)

| Field | Value |
|---|---|
| **Steps** | 1. Triple-press sync button within 2 seconds. 2. Observe LED confirmation (5 rapid blinks). 3. DUT resets. 4. Scan from host. |
| **Expected** | Device advertises as "Dreamcast Wireless Controller". |
| **Pass/Fail** | Name changes after reset. Preference persists across further power cycles. |
| **Equipment** | DUT, host device |

### BLE-12: Name Toggle Persistence

| Field | Value |
|---|---|
| **Steps** | 1. Toggle name to Dreamcast (BLE-11). 2. Power cycle DUT. 3. Check advertised name. 4. Toggle back to Xbox. 5. Power cycle. 6. Verify Xbox name. |
| **Expected** | Name preference survives power cycles in both directions. |
| **Pass/Fail** | Both name states persist. |
| **Equipment** | DUT, host device |

### BLE-13: Range Test -- Close (1 Meter)

| Field | Value |
|---|---|
| **Steps** | 1. Connect DUT to host. 2. Place DUT 1 meter from host. 3. Press buttons and move stick continuously for 60 seconds. |
| **Expected** | No disconnections. No noticeable input lag. All inputs register. |
| **Pass/Fail** | Zero disconnects, zero missed inputs over 60 seconds. |
| **Equipment** | DUT, Dreamcast controller, laptop, gpadtester.com, tape measure |

### BLE-14: Range Test -- Medium (5 Meters)

| Field | Value |
|---|---|
| **Steps** | Same as BLE-13 at 5 meters distance. |
| **Expected** | No disconnections. Minimal input lag (< 30ms perceived). |
| **Pass/Fail** | Zero disconnects over 60 seconds. |
| **Equipment** | DUT, Dreamcast controller, laptop, tape measure |

### BLE-15: Range Test -- Far (10 Meters, Line of Sight)

| Field | Value |
|---|---|
| **Steps** | Same as BLE-13 at 10 meters with clear line of sight. |
| **Expected** | Connection may degrade. Acceptable: occasional lag. Not acceptable: frequent disconnects. |
| **Pass/Fail** | Fewer than 3 disconnects per minute at 10m. Reconnects automatically if lost. |
| **Equipment** | DUT, Dreamcast controller, laptop, tape measure |

### BLE-16: Interference Resilience

| Field | Value |
|---|---|
| **Steps** | 1. Connect DUT at 3 meters. 2. Place active Wi-Fi router between DUT and host. 3. Start a large file transfer over Wi-Fi. 4. Test inputs for 60 seconds. |
| **Expected** | BLE uses adaptive frequency hopping; moderate Wi-Fi interference should not cause disconnection. Some latency increase acceptable. |
| **Pass/Fail** | No disconnection during 60-second test. Inputs still register. |
| **Equipment** | DUT, Dreamcast controller, laptop, Wi-Fi router |

---

## 3. Power Management

### PWR-01: System Off via Sync Button (7-Second Hold)

| Field | Value |
|---|---|
| **Steps** | 1. Power on DUT. 2. Hold sync button for 7+ seconds. 3. LED blinks during hold, goes solid near end. 4. Release button. |
| **Expected** | DUT enters System Off. All LEDs extinguished. Boost converter disabled. Current draw < 10 uA. |
| **Pass/Fail** | System Off entered on release. Current confirmed < 10 uA with multimeter. |
| **Equipment** | DUT, multimeter, stopwatch |

### PWR-02: Wake from System Off

| Field | Value |
|---|---|
| **Steps** | 1. Enter System Off (PWR-01). 2. Press sync button briefly. 3. Observe boot sequence. |
| **Expected** | DUT performs full reset. Green LED blinks 3x (startup). Enters appropriate BLE state (sync or reconnect depending on bond). |
| **Pass/Fail** | DUT wakes and boots correctly within 3 seconds of button press. |
| **Equipment** | DUT |

### PWR-03: Advertising Timeout -- No Bond

| Field | Value |
|---|---|
| **Steps** | 1. Clear bonds and power on. 2. DUT enters sync mode. 3. Do not pair. 4. Wait for sync timeout (60s). |
| **Expected** | After 60 seconds of unanswered advertising with no bond, DUT enters System Off. |
| **Pass/Fail** | System Off at correct timeout. |
| **Equipment** | DUT, stopwatch |

### PWR-04: Controller Detection Timeout

| Field | Value |
|---|---|
| **Steps** | 1. Connect DUT via BLE to host (no Dreamcast controller plugged in). 2. Wait 60 seconds. |
| **Expected** | DUT searches for controller with exponential backoff. After DETECT_TIMEOUT_MS (60s), enters System Off. RTT shows "MAPLE: Detect timeout". |
| **Pass/Fail** | System Off at correct timeout. |
| **Equipment** | DUT, host device, SWD debugger, stopwatch |

### PWR-05: Inactivity Timeout (10 Minutes)

| Field | Value |
|---|---|
| **Steps** | 1. Connect DUT with controller. 2. Verify inputs work. 3. Set controller down, do not touch. 4. Wait 10 minutes. |
| **Expected** | After INACTIVITY_TIMEOUT_MS (600,000ms = 10 min) with no input change, DUT enters System Off. |
| **Pass/Fail** | System Off at correct timeout. Any input during the window resets the timer. |
| **Equipment** | DUT, Dreamcast controller, host, stopwatch/timer |

### PWR-06: Inactivity Timer Reset on Input

| Field | Value |
|---|---|
| **Steps** | 1. Connect DUT with controller. 2. Wait 9 minutes idle. 3. Press a button. 4. Release. 5. Wait another 9 minutes idle. 6. Verify DUT is still awake (total 18 minutes). |
| **Expected** | Button press at 9 minutes resets the inactivity timer. DUT stays awake through minute 18. |
| **Pass/Fail** | DUT remains active after timer reset. |
| **Equipment** | DUT, Dreamcast controller, host, timer |

### PWR-07: Battery Voltage Reading Accuracy

| Field | Value |
|---|---|
| **Steps** | 1. Measure battery voltage with multimeter at LiPo terminals. 2. Read RTT log for "BAT: XXXXmV" output. 3. Compare. |
| **Expected** | SAADC reading within 100mV of multimeter reading (accounting for divider tolerance). |
| **Pass/Fail** | Within 100mV across the 3.0-4.2V range. |
| **Equipment** | DUT, multimeter, SWD debugger |

### PWR-08: Battery Percentage Reporting via BLE

| Field | Value |
|---|---|
| **Steps** | 1. Connect DUT. 2. Read Battery Service (0x180F) Battery Level characteristic via nRF Connect. 3. Compare with RTT log percentage. |
| **Expected** | BLE battery level matches RTT logged percentage (0-100%). |
| **Pass/Fail** | Values match. Updates occur every 60 seconds (BATTERY_READ_INTERVAL_MS). |
| **Equipment** | DUT, nRF Connect app, SWD debugger |

### PWR-09: Low Battery Cutoff

| Field | Value |
|---|---|
| **Steps** | 1. Connect a bench power supply set to 3.2V in place of battery (or use a partially discharged LiPo). 2. Power on DUT. 3. Slowly reduce voltage below 3.2V (LOW_BATTERY_CUTOFF_MV). |
| **Expected** | When battery reads below 3200mV and not charging, DUT enters System Off. RTT shows "PWR: Low battery". |
| **Pass/Fail** | System Off triggered at or near 3.2V. |
| **Equipment** | DUT, bench power supply or discharged LiPo, SWD debugger |

### PWR-10: Low Battery Cutoff Inhibited While Charging

| Field | Value |
|---|---|
| **Steps** | 1. Connect USB charger. 2. Use a low-voltage battery (near 3.2V). 3. Verify DUT does NOT enter System Off while charging. |
| **Expected** | Charging flag (BQ25101 STAT pin LOW) inhibits low-battery cutoff. Battery level BLE characteristic reports 0xFF (charging indicator). |
| **Pass/Fail** | DUT stays awake while charging regardless of voltage. |
| **Equipment** | DUT, USB charger, low-voltage LiPo |

### PWR-11: USB VBUS Detection -- Boost Bypass

| Field | Value |
|---|---|
| **Steps** | 1. Connect USB cable. 2. Connect via BLE. 3. Check RTT output for "PWR: USB detected, boost off (passthrough)". 4. Verify controller still gets 5V power (test inputs). |
| **Expected** | Boost converter remains off. Controller powered via Schottky diode passthrough from USB 5V. All inputs work normally. |
| **Pass/Fail** | Boost stays off, controller functional on USB power. |
| **Equipment** | DUT, USB cable, Dreamcast controller, SWD debugger |

### PWR-12: USB Plug/Unplug During Operation

| Field | Value |
|---|---|
| **Steps** | 1. Run DUT on battery (boost on, connected, controller working). 2. Plug in USB cable. 3. Verify RTT: "PWR: USB connected, disabling boost (passthrough)". 4. Verify inputs still work. 5. Unplug USB. 6. Verify RTT: "PWR: USB removed, enabling boost". 7. Verify inputs still work. |
| **Expected** | Seamless transition between boost and USB passthrough in both directions. No dropped BLE connection. No missed inputs. |
| **Pass/Fail** | No connection drop or input interruption during transition. |
| **Equipment** | DUT, USB cable, LiPo, Dreamcast controller, SWD debugger |

### PWR-13: Charge Status Detection

| Field | Value |
|---|---|
| **Steps** | 1. Connect USB with LiPo attached. 2. Monitor RTT for "CHG: Charging started". 3. Wait for full charge or disconnect USB. 4. Monitor for "CHG: Charging stopped". |
| **Expected** | BQ25101 STAT pin correctly detected. Transitions logged. |
| **Pass/Fail** | Charge state transitions detected and logged correctly. |
| **Equipment** | DUT, USB cable, LiPo, SWD debugger |

### PWR-14: Current Draw -- Active (Battery)

| Field | Value |
|---|---|
| **Steps** | 1. Insert USB power meter or ammeter in series with battery. 2. Connect DUT via BLE, controller active. 3. Measure steady-state current. |
| **Expected** | Total draw should be approximately: nRF52840 (~5mA) + boost converter overhead (~10mA) + Dreamcast controller (~110mA) = ~125mA total from battery. |
| **Pass/Fail** | Measured current within 80-160mA range. |
| **Equipment** | DUT, multimeter/ammeter, LiPo, Dreamcast controller |

### PWR-15: Current Draw -- System Off

| Field | Value |
|---|---|
| **Steps** | 1. Enter System Off (PWR-01). 2. Measure current with sensitive ammeter or multimeter on uA range. |
| **Expected** | < 10 uA total (nRF52840 System Off ~1.5uA + QSPI flash DPD ~3uA + boost off + leakage). |
| **Pass/Fail** | < 10 uA measured. If > 10 uA, check for leaking GPIOs or undisconnected peripherals. |
| **Equipment** | DUT, sensitive multimeter (uA range) |

### PWR-16: QSPI Flash Deep Power Down

| Field | Value |
|---|---|
| **Steps** | 1. Power on DUT. 2. Observe RTT: "QSPI: Flash in Deep Power Down". 3. (Optional) Compare active current with a build that skips the DPD command. |
| **Expected** | Flash enters DPD at startup, saving 2-5 mA. |
| **Pass/Fail** | RTT message confirms DPD. Optional current comparison shows savings. |
| **Equipment** | DUT, SWD debugger, multimeter (optional) |

---

## 4. Durability and Stress Testing
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

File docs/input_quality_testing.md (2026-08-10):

# Controller Input Quality & Latency Testing

Reference notes on measuring packet loss / input timing for the adapter, and the
current understanding of the fighting-game "misdirection" report (public issue #5).

> Status: **resolved and shipped.** This page is kept as the full investigation record,
> read top to bottom in chronological order — the early sections describe hypotheses that
> later sections disprove, so do not quote them in isolation. The root cause was the main
> loop completing only ~12–17×/sec, not the BLE link; the fix (decode early-termination
> plus `POLL_INTERVAL_MS` 16→8) landed in v0.2.6 and re-passed acceptance in v0.2.8 with
> the hardware-timed DMA TX. See the acceptance tables at the end for the final numbers.

## The problem (issue #5)

Reporter (Xcynz): rotating the joystick at speed in a Dreamcast fighting game
(Capcom vs SNK 2, training mode, KEY DISPLAY on) drops/misorders direction inputs
over BLE compared to a wired controller, so special-move motions fail. Slow
rotations look fine; only fast ones (~3 rotations/sec) misbehave.

## What we changed, and why it wasn't enough

- v0.2.1 fixed the **sticks** (signed 4-byte `Logical Maximum`).
- The poll-rate experiment matched the Maple poll to the BLE notify cadence:
  `POLL_INTERVAL_MS 16 → 8` (60 → 125 Hz). This removed the "every other BLE notify
  carries a stale Maple sample" aliasing. HIDAPI traces: min inter-arrival
  **30 ms → 13–15 ms**.
- **But the reporter tested it (blinded Build A) and saw "no improvement";** a second
  variant (Build B) felt worse ("serious delay"). So the internal poll fix removed one
  aliasing source but did **not** move the real ceiling.

## The real ceiling (analysis)

The internal Maple poll is no longer the bottleneck. Two downstream limits dominate:

1. **BLE connection interval (host-imposed).** The firmware *already requests*
   8.75–11.25 ms (`src/ble/task.rs:308` `min_conn_interval: 7, max_conn_interval: 9`,
   `slave_latency: 0`). macOS hands back **~13–15 ms (~66 Hz)** anyway — iOS/macOS
   floor BLE-HID at ~15 ms regardless of what the peripheral asks. **We cannot lower
   this from firmware alone; it is negotiated by the central.** A dedicated receiver
   (BlueRetro / iBlueControlMod feeding a real Dreamcast) may negotiate differently —
   measure it there, don't assume the Mac number.
2. **Dreamcast Maple poll (~60 Hz, once per frame)** on the BlueRetro side.

**Nyquist check:** 3 rotations/sec × 8 directions ≈ 24 transitions/sec; a clean
press+release per transition needs ~48 Hz of headroom. A ~66 Hz BLE link with jitter
sits right at that edge — which is exactly why fast rotations alias and slow ones
don't. Xcynz's framing is correct.

**Lever that could actually help:** the *host's* accepted connection interval, not the
internal poll. Worth measuring whether a real BlueRetro receiver grants something
tighter than macOS does. Stick filtering (One Euro, on `feat/stick-filter-experiment`)
trades latency for smoothness and is generally disliked by fighting-game players.

## What test tooling we have today

- `tests/blueretro/` — QEMU harness, but **button mapping only**, no timing/loss.
- `docs/test_plan.md` §7 — *theoretical* latency budget + a "film at 240 fps" idea.
- `gpadtester.com` referenced for manual HID validation.
- The poll-fix HIDAPI traces were **ad-hoc and never committed.** We have the
  technique, not a saved, reproducible test. (This doc + a planned capture script fix that.)

## Off-the-shelf tools worth using

| Tool | Measures | Notes |
|---|---|---|
| [gamepadla-plus](https://github.com/WyvernIXTL/gamepadla-plus) | polling rate, jitter, latency | CLI/GUI, **macOS via `uv`**; connect adapter to Mac as an Xbox HID gamepad |
| [cakama3a/Polling](https://github.com/cakama3a/Polling) | polling rate + latency | XInput analog |
| [finger563/esp-latency-test](https://github.com/finger563/esp-latency-test) | actuation→report (BLE) **and** actuation→screen (photodiode) latency | gold standard; needs ESP32 + 3 mm photodiode + resistor |
| [gpadtester.net/latency-test](https://gpadtester.net/latency-test/) | browser latency | zero-setup sanity check |

Background: [Punch Through — BLE connection interval](https://punchthrough.com/ble-connection-interval-throughput/),
[Nordic — BLE HID ~34 pps on default params](https://devzone.nordicsemi.com/f/nordic-q-a/71673/nrf52-ble-hid-packet-rate-problem),
[PulseGeek — BT vs USB latency](https://pulsegeek.com/articles/controller-codecs-and-bluetooth-vs-usb-latency/).

## Proposed test plan

1. **Baseline (no hardware):** run `gamepadla-plus` on the Mac with the adapter
   connected → record polling rate / jitter.
2. **`scripts/hid_capture.py`** (hidapi, `uv`-managed) — **built.** Connect the adapter
   to the Mac as an Xbox HID gamepad, then:
   ```
   uv run scripts/hid_capture.py --list          # confirm the device is seen
   uv run scripts/hid_capture.py --seconds 10     # rotate the stick continuously
   uv run scripts/hid_capture.py --input dpad     # or rotate the d-pad
   ```
   It reports inter-arrival min/median/p99/max, jitter (stdev + IQR), effective Hz, and a
   **rotation-completeness** check — bins the stick angle (or hat) into 8 octants and flags
   any jump of ≥2 octants as a *skipped direction* (the issue #5 symptom), the quantitative
   version of the in-game KEY DISPLAY test. Keep the input moving for the whole window
   (send-on-change means stillness produces no reports).
3. **Sequence counter (`seq-counter` feature) — built.** A debug build stamps a 7-bit
   counter into report byte 15 (HID padding bits 1-7, no phantom buttons) so loss is
   *measured*, not inferred:
   ```
   cargo build --release --no-default-features --features board-dk,rtt,seq-counter  # flash this
   uv run scripts/hid_capture.py --seconds 10 --seq                                 # rotate, read drops
   ```
   Contiguous counter ⇒ firmware under-sending (the measured rate is real); gaps ⇒ reports
   dropped in transit (BLE or macOS) ⇒ re-check on a Linux `hidraw` host to separate the two.
4. **Connection interval:** measure what the real BlueRetro/Dreamcast receiver actually
   negotiates vs the Mac's ~15 ms; that's the lever, not the internal poll.
5. **(Optional) end-to-end:** `esp-latency-test` rig for true press-to-screen latency.

## First measurement (2026-06-08, Mac host, ~1.3 rot/s left-stick rotation)

`hid_capture.py` over 10 s: **136 reports (~14/s overall)**, active-burst median interval
**45 ms (~22 Hz)** with **71 gaps of 60–180 ms** — 3–4× slower than the ~66 Hz the ~15 ms
conn interval should allow. Result: **61 of ~124 direction transitions skipped a direction
(~50%)**.

This reproduces issue #5 **on the BLE leg alone** (Mac host, no BlueRetro/Dreamcast): the
report stream collapses to ~14–22 Hz with 60–180 ms holes during continuous motion, and the
holes straddle octant boundaries → directions vanish. At ~3 rot/s (real fighting-game speed)
it would be far worse.

## Root cause — poll rate, not the link (2026-06-08)

The `seq-counter` build settled it: the counter in byte 15 arrived **perfectly contiguous over
116 reports — zero transit loss.** So the ~12–17 reports/sec is *real firmware output*, not the
BLE link or macOS dropping anything. And `STICK_CHANGE_THRESHOLD = 2/255` is far too sensitive
to be filtering, so the send rate equals the **actual Maple poll rate**: the main loop is only
completing ~12–17 times/sec (a ~30–80 ms iteration where ~8 ms was assumed).

This is the true root cause of issue #5, and it explains why the 60→125 Hz "fix" did nothing —
`POLL_INTERVAL_MS` is only the *delay between* polls, negligible against a 30–80 ms loop. Two
suspects, both in the main loop, both on the Maple bus:
1. **`get_condition` baseline** — even the fastest polls are ~29 ms apart vs the few ms a clean
   Maple read should take (suspect: the 24 KB bulk-capture + software decode, and/or the 3×
   retry firing under BLE radio interference).
2. **VMU LCD writes** — `host.write_vmu_lcd` bit-bangs the framebuffer over the same Maple bus
   when an animation frame is dirty, stalling the poll (fits the ~195 ms spikes).

**Next — attribute the split** with the `poll-timing` feature (DWT cycle counter, logged via RTT
outside the TX/RX window, per `learnings.md` §2):
```
cargo build --release --no-default-features --features board-dk,rtt,poll-timing  # flash DK
# RTT prints every ~60 polls:
#   POLLTIME us | period avg=.. min=.. max=.. | get_cond avg=.. max=.. | vmu avg=.. max=.. | n=..
```
`period − 8000 µs − get_cond − vmu` ≈ the rest of the loop. Whichever dominates is the fix target
(trim the capture/decode, or move the VMU write off the poll path).
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

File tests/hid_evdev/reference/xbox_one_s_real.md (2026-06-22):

# Ground-truth: real Xbox One S (Model 1708) Bluetooth descriptors

This is the reference the Generic/Xbox descriptors are measured against (plan Story 4).
The "shape" facts below are encoded as assertions in `test_descriptor_layout.py`.

## Firmware eras / PIDs (VID 0x045E)

| PID | Firmware era | Notes |
|---|---|---|
| `0x02E0` | original Xbox One S | "Windows wireless" identity; what BlueRetro & retro stacks expect |
| `0x02FD` | original BLE firmware | pre-update BLE PID |
| `0x0B20` | post-2021 FW (≥5.11.x)  | new BLE identity; falls under `hid-generic`. Our Generic/Dreamcast profile uses this recognized Xbox-family identity while serving our contiguous descriptor |

Source: SDL #3075, xpadneo #314, kernel `hid-microsoft`.
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

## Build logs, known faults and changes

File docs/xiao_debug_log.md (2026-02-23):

# XIAO nRF52840 Debug Log

Running log specific to the XIAO board build. The XIAO has never successfully received Maple Bus responses — this log tracks the investigation.

---

## Session: 2026-02-17 (Initial XIAO Maple Bus Debugging)

### Setup
- XIAO nRF52840 (regular, not Sense) flashed via DK's J-Link (external SWD)
- S140 SoftDevice pre-flashed on XIAO
- Controller powered from DK 5V output
- 4.7kΩ pull-ups from data lines to XIAO 3V3 pin (direct)
- **No inline resistors** on data lines
- XIAO pins: SDCKA = P0.05 (D5), SDCKB = P0.04 (D4)

### Problem
XIAO build detects start patterns but captures far too few bits. Controller never detected. DK build works with the same shared protocol code.

### Test 1: Baseline (before any fixes)
```
TX: DeviceInfoRequest (pre-TX pins: A=false B=false)
TX: Post-TX pins: A=false B=false
RX: start pattern found (b_trans=5, wait=8)
RX DECODE: bits=13 a_falls=7 b_falls=6 gaps=0 first_edge=16
RX: response=false
```
Only 10-13 bits captured per attempt (expected 256+).

### Fix 1: Remove RTT logging from TX→RX hot path
**Root cause:** `rprintln!` calls in `host.rs:request_device_info()` between `write_packet()` and `read_packet_bulk()` added ~20ms of dead time. The controller responds within ~100µs, so the entire response was missed.

**Change:** Removed pre-TX and post-TX rprintln from `host.rs`. Added comment explaining why no logging is allowed in this gap.

### Test 2: After RTT fix
```
RX: start pattern found (b_trans=6, wait=14)
RX DECODE: bits=31 a_falls=16 b_falls=15 gaps=0 first_edge=5
RX: response=false
```
**Improvement:** 10-13 bits → 31 bits. Start detection now better (b_trans=6). But still far short of 256+.

31 bits ≈ 1/4 of first 4-word chunk, then signal disappears.

### Fix 2 (REVERTED): Disable interrupts around sampling
**Hypothesis:** SoftDevice radio ISRs preempting the sampling loop for 50-200µs.

**Change:** Added `cortex_m::interrupt::disable()` before sampling, re-enabled after.

**Result:** SoftDevice assertion failure → panic-reset → infinite reboot loop. SoftDevice cannot tolerate 2ms interrupt blackout.

**Critical:** Also disproved the hypothesis — bits=31 even WITH interrupts disabled. Interrupts are NOT the cause.

### Fix 3 (REVERTED): MIN_START_TRANSITIONS = 6
**Hypothesis:** False start pattern detection with threshold of 3.

**Result:** b_trans was already 6+ naturally. Changing threshold from 3 to 6 did not change bit count (still 31). Reverted to 3 to keep DK build unchanged.

### Raw sample diagnostic added
Added post-capture analysis (no hot-path impact) that dumps a few samples from the already-captured buffer when < 32 bits are decoded. Shows raw pin states at sample[0], sample[500], sample[5000], and sample[end], plus the pin masks being used.

**Awaiting flash to see output.**

### I2C Pin Investigation (P0.04 / P0.05) — RULED OUT

D4 (P0.04) and D5 (P0.05) are the default I2C SDA/SCL pins on the XIAO. Initially suspected as a cause, but:
- **Board is regular variant** (not Sense) — no IMU on these pins
- **Pull::None had no effect** — on-board pull-ups (if any) aren't the issue
- **Root cause was the voltage divider**, not the pins themselves

### Fix 4 (REVERTED): Internal pull-ups disabled (Pull::None)
**Hypothesis:** On-board I2C pull-ups on D4/D5 combined with internal pull-ups creating too-strong pull-up.

**Change:** XIAO build uses `Pull::None` instead of `Pull::Up`.

**Result:** No improvement. Still 20-34 bits. Reverted.

### Test 3: After Pull::None + raw sample diagnostic
```
RX: start pattern found (b_trans=3, wait=7)
RX DECODE: bits=30 a_falls=15 b_falls=15 gaps=0 first_edge=5
RX RAW: [0]=0x20 [500]=0x30 [5000]=0x30 [end]=0x30 masks=A:0x20 B:0x10
RX: first bits: [1, 0, 1, 0, 1, 0, 1, 0, 0, 1, 1, 0, 0, 1, 1, 0]
```
**Key observations:**
- `[500]=0x30` — both pins HIGH by sample 500 (~40µs). Signal dies very early.
- First bits are **random every run** — not reading real controller response
- b_trans=3-4, lower than DK's typical 3-7

### Ruled Out
- **I2C pin IMU interference** — Board confirmed as regular variant (Amazon ASIN B09T9VVQG7), no IMU on D4/D5
- **I2C on-board pull-ups** — Pull::None had no effect; even if present, not the cause
- **SoftDevice interrupts** — Disproved (bits unchanged with interrupts disabled)
- **MIN_START_TRANSITIONS threshold** — No effect (b_trans already passing)

### Leading Hypothesis: Missing 47Ω Inline Resistors

**Corrected understanding of both setups (2026-02-17):**

| | DK (WORKS) | XIAO (DOESN'T WORK) |
|--|---|---|
| Pull-up source | 3.3V via voltage divider from 5V (weak) | Direct 3V3 pin (strong) |
| Pull-up value | 4.7kΩ | 4.7kΩ |
| Inline resistors | **47Ω on each data line** | **None** |
| Data pins | P0.05 / P0.06 | P0.05 / P0.04 |

~~Previously suspected the voltage divider pull-ups on the XIAO were the problem — this was wrong.~~ The DK also uses a voltage divider for 3.3V and works fine. The XIAO pull-ups are actually direct to 3V3 (stronger source).

The key hardware difference is the **47Ω inline resistors** present on the DK but absent on the XIAO. These resistors:
- Dampen signal ringing/reflections after each edge transition
- Form a low-pass filter with line capacitance, cleaning up edges
- Limit current during transitions

Without them, at 2Mbps the data lines can ring after each edge. The sampling loop would see ringing as additional false edges, explaining the **random first bits** (reading ringing artifacts, not real data) and the signal appearing to "die" early (ringing subsides, no more detectable edges).

**Fix:** Add 47Ω inline resistors between controller data lines and XIAO D4/D5, matching the DK setup.

### DK Baseline Comparison (2026-02-17)
DK flashed with same code, **confirmed working** (controller detected, BLE functional):
```
RX: start pattern found (b_trans=5, wait=228)
RX DECODE: bits=139 a_falls=70 b_falls=69 gaps=0 first_edge=4
```
- 139 bits — first chunk, enough for frame decode and controller detection
- Deterministic — same result every run (vs XIAO's random bits)
- DK has 47Ω inline resistors + voltage divider 3.3V pull-ups

### XIAO Pin Constraints
All P0 pins on the XIAO header (required for our P0 register bulk sampling):
| Header | nRF Pin | Current Use |
|---|---|---|
| D0 | P0.02 | Wake button |
| D1 | P0.03 | Free |
| D2 | P0.28 | Boost SHDN |
| D3 | P0.29 | Sync button |
| D4 | P0.04 | **SDCKB** (I2C SDA) |
| D5 | P0.05 | **SDCKA** (I2C SCL) |

D6-D10 are all on P1 — cannot be used for Maple Bus bulk sampling.
If D4/D5 prove problematic even with proper pull-ups, options are limited (D1 is the only free P0 pin).

### Theories (Ranked by Likelihood)

**1. Missing 47Ω inline resistors (HIGH confidence)**
The only confirmed hardware difference between working DK and non-working XIAO. Without damping, signal ringing at 2Mbps causes false edge detection → random bits → decode failure.
**Test:** Add 47Ω inline resistors to XIAO data lines, matching DK.

**2. Pin differences P0.04 vs P0.06 (MEDIUM confidence)**
DK uses P0.06 for SDCKB, XIAO uses P0.04. P0.04 is the I2C SDA pin — may have different drive characteristics, internal routing, or parasitic capacitance vs P0.06 (generic GPIO). Could combine with missing inline resistors to make ringing worse.
**Test:** If inline resistors don't fully fix it, try P0.03 (D1) instead of P0.04 if wiring allows.

**3. Pull-up strength difference (LOW confidence)**
DK pull-ups: voltage divider 3.3V (higher impedance, weaker drive).
XIAO pull-ups: direct 3V3 (lower impedance, stronger drive).
Stronger pull-ups = faster rise times = more ringing energy. Counterintuitive but could contribute.
**Test:** Try weaker pull-ups on XIAO (10kΩ) or add series resistance to pull-up path.

**4. PCB routing / trace length (LOW confidence)**
XIAO is a tiny board with dense routing. Data line traces may have different impedance than DK's header pins. Unlikely to be the sole cause but could compound other issues.
**Test:** Can't easily change, but inline resistors would mitigate.

**5. Ground/power path differences (LOW confidence)**
XIAO powered from DK 5V + its own regulator. Different ground path length between controller and XIAO vs controller and DK. Could cause ground bounce at 2Mbps.
**Test:** Ensure short, direct ground connection between controller and XIAO.

### Complete Hardware Setup Reference

**DK Setup (WORKING):**
```
Dreamcast Controller          DK Board
─────────────────           ──────────
Pin 1 (Red/SDCKA)  ──47Ω──── P0.05
                        │
                      4.7kΩ
                        │
                      3.3V (voltage divider from 5V)

Pin 5 (White/SDCKB) ──47Ω──── P0.06
                        │
                      4.7kΩ
                        │
                      3.3V (voltage divider from 5V)

Pin 2 (Blue/+5V)   ─────────── DK 5V out
Pin 3 (Green/GND)  ─────────── DK GND
Pin 4 (Black/GND)  ─────────── DK GND
```

**XIAO Setup (NOT WORKING):**
```
Dreamcast Controller          XIAO Board
─────────────────           ──────────────
Pin 1 (Red/SDCKA)  ─────────── D5 (P0.05)
                        │
                      4.7kΩ
                        │
                      XIAO 3V3 pin

Pin 5 (White/SDCKB) ─────────── D4 (P0.04)
                        │
                      4.7kΩ
                        │
                      XIAO 3V3 pin

Pin 2 (Blue/+5V)   ─────────── DK 5V out (external)
Pin 3 (Green/GND)  ─────────── DK GND (external)
Pin 4 (Black/GND)  ─────────── DK GND (external)
```

**Key differences:** No 47Ω inline resistors. Different SDCKB pin (P0.04 vs P0.06). Pull-ups to direct 3V3 vs voltage divider.

### Test 4: MIN_RESPONSE_WAIT=100 (skip early noise)
Added minimum 100-cycle wait before accepting A LOW. Result:
```
RX: start pattern found (b_trans=4, wait=108)
RX DECODE: bits=14 a_falls=5 b_falls=9 gaps=0 first_edge=1
  e0-e11: gaps of 1-5 samples (erratic, expected ~14)
RX DIAG: edges=13 last_active_sample=39 (3 us)
```
- wait jumped from 0-24 to **106-108** — skipped the earliest noise
- But edges are 1-5 samples apart (expected ~14) and not alternating A/B — still noise
- wait=108 is right at our minimum, not at the expected ~228

### Test 5: MIN_RESPONSE_WAIT=200 (look for real response)
Pushed minimum to 200 to skip all noise and find real controller response at ~228 cycles.
```
RX: timeout waiting for A LOW (idle_in=true, idle_cycles=5, wait_cycles=64001)
```
**Every attempt timed out.** No A LOW detected after cycle 200.

**Conclusion: The controller is NOT responding to the XIAO's TX.** All previous "edges" were noise/ringing, not controller data. The issue is on the transmit side — without 47Ω inline resistors, the TX signal may be ringing or overshooting, and the controller doesn't recognize the request.

### Updated Theories (2026-02-17)

**1. ~~Missing 47Ω inline resistors affect TX~~ — RULED OUT**
Added 47Ω inline resistors matching DK setup. No change: still wait=106-108, bits=14-19, noise edges. The resistors are not the differentiator.

**2. Software MIN_RESPONSE_WAIT (PARTIAL — helps with RX noise but doesn't fix TX)**
MIN_RESPONSE_WAIT=100 successfully skips early ringing on receive, but can't fix the root cause: the controller doesn't see a valid request.

### Test 6: 47Ω Inline Resistors Added
Added 47Ω inline resistors on both data lines (Red→47Ω→D5, White→47Ω→D4), matching the DK wiring.
```
RX: start (b_trans=4 wait=108)
RX FAIL: bits=14 edges=14 active=3us first_edge=1
```
**No change.** Identical to pre-resistor results. Controller still not responding.

### XIAO Schematic Investigation (2026-02-17)

Reviewed the XIAO nRF52840 KiCad schematic. Key findings:
- **No series resistors** on GPIO header pins D0-D5. Direct chip-to-pad connections.
- **No on-board I2C pull-ups** on D4/D5.
- **P0.04 is electrically identical to P0.06** at the silicon level. Analog-capable pins (AIN0-7) only differ when SAADC is enabled (it's not in our code). Same pad capacitance (~4pF), same drive strength options, same slew rate.
- Pin choice is NOT the cause.

### Theory 3: OutputDrive::Standard Too Weak (NEW — testing)

DK and XIAO both used `OutputDrive::Standard` (S0S1, 1-4mA). But the XIAO's power rail or board routing may produce marginally weaker edges at Standard drive, especially at 2Mbps. The DK has better decoupling/power rail quality.

**Change:** Switched both data pins to `OutputDrive::HighDrive` (H0H1, 6+mA) in `gpio_bus.rs` — affects both `new()` and `set_output_mode()`. This is a global change (both boards), which is fine since HighDrive is strictly better for clean edges.

### Ranked Theories (updated)
1. **OutputDrive too weak (TESTING)** — Standard drive may be marginal on XIAO
2. **Pin differences P0.04 vs P0.06 — RULED OUT** (schematic confirms identical)
3. **Missing inline resistors — RULED OUT** (added, no change)
4. **Power supply / ground path** — XIAO 3.3V rail quality may differ from DK
5. **Board routing** — XIAO traces are short (~mm) but dense; unlikely sole cause

### XIAO Chip Lock / Recovery

When flashing the XIAO via DK's external SWD, a crash can leave the core in "locked up status" where `probe-rs erase` fails repeatedly.

**Recovery (in order):**

1. **`nrfjprog --recover`** — works when probe-rs cannot connect. Does a full chip erase including UICR.
2. Double-tap XIAO reset button for UF2 bootloader (needs USB connected to host), then retry erase.
3. Physical power cycle (disconnect battery), then erase immediately before firmware boots.

**After recovery, must reflash SoftDevice before app:**
```bash
nrfjprog --recover
nrfjprog --program vendor/s140_softdevice/s140_nrf52_7.3.0_softdevice.hex --verify
cargo embed --features board-xiao --no-default-features
```

### Test 7: HighDrive Output (H0H1, 6+mA)
Switched both data pins to `OutputDrive::HighDrive` for XIAO only.
```
RX: start (b_trans=4 wait=108-139)
RX FAIL: bits=2-7 edges=... active=3us
```
**No improvement.** Wait values shifted slightly (108→139) but still noise, not real response. HighDrive kept as XIAO-only default since it doesn't hurt.

### Test 8: Direct Ground Wire
Added short direct ground wire between controller ground and XIAO ground pad.
```
RX: start (b_trans=4 wait=106-108)
RX FAIL: bits=14 edges=14 active=3us
```
**No change.** Ground path is not the issue.

### Test 9: External Pull-ups Removed
Removed external 4.7kΩ pull-ups, relying only on internal ~13kΩ pull-ups.
```
Same results — no improvement.
```
**Pull-up strength is not the cause.**

### CRITICAL: Code Regression Identified and Fixed
During debugging, experimental changes were made to `wait_and_sample()`:
- Removed start pattern detection, replaced with immediate capture
- Added "slow scan" (NOP-padded sampling at 1/200th speed)
- Doubled buffer to 49,152 samples

**These changes broke BOTH boards.** DK went from 139 bits to 0 bits. The slow scan added ~2ms delay, causing bulk capture to start AFTER the controller response finished.

**Fix:** Reverted ALL experimental changes to original `wait_and_sample()` with start pattern detection.

### Test 10: DK Baseline After Code Restore
DK flashed with restored original code:
```
RX: start (b_trans=5 wait=294)
RX DECODE: bits=139 gaps=0 active=... range=...
RX: start (b_trans=6 wait=303)
RX DECODE: bits=139 gaps=0 active=... range=...
```
**DK confirmed working.** wait=294-303, consistent 139 bits every attempt.

### Test 11: XIAO With Restored Code
Same code flashed to XIAO:
```
RX: start (b_trans=4 wait=4)
RX FAIL: bits=23 edges=23 first_active=0 (0us) last_active=76 (6us)
RX: start (b_trans=3 wait=9)
RX DECODE: bits=33 gaps=0 active=120/24576 range=0..133
RX: start (b_trans=4 wait=20)
RX FAIL: bits=30 edges=30 first_active=0 (0us) last_active=99 (7us)
```
**XIAO still fails.** wait=4-20 (vs DK's 294-303). Activity only in first 76-133 samples (~6-10µs).

### KEY FINDING: wait Value Difference
| | DK | XIAO |
|--|-----|---|
| wait | 294-303 | 4-20 |
| bits | 139 (consistent) | 23-33 (random) |
| activity range | hundreds of samples | 76-133 samples |

The XIAO detects A LOW almost immediately after idle (wait=4-20), meaning it triggers on **TX ringing** — electrical echo from our own transmit. The DK waits ~294 cycles for the **real controller response**.

### Scope Confirmation: Controller DOES Respond
Scope probed at XIAO D5 pin (SDCKA) while XIAO was running:
- **Full Device Info Response visible** — 7 burst groups with inter-chunk gaps
- Signal structure matches DK captures exactly
- The controller IS responding to the XIAO's TX

**The response reaches the XIAO pin, but the GPIO IN register captures TX ringing first, filling the buffer with noise before the real response arrives.**

### PIN_CNF Verification
Read PIN_CNF register for both pins during input mode:
```
PIN_CNF = 0x0000000C  (Input, Connected, PullUp, Standard drive)
```
Both pins correctly configured. No anomaly.

### P0 Register Full Scan
Captured `changed` mask (XOR of first and last sample across entire P0):
```
changed = 0x00000030
```
Only bits 4 and 5 toggle — confirming correct pin mapping (P0.04 and P0.05).

### Ruled Out (Complete List)
1. **I2C pin interference** — Regular variant, no IMU
2. **On-board pull-ups** — None per schematic
3. **SoftDevice interrupts** — Disproved
4. **Start transition threshold** — No effect
5. **47Ω inline resistors** — Added, no change
6. **Pin differences (P0.04 vs P0.06)** — Schematic confirms identical
7. **Pull-up strength** — Removing external pull-ups had no effect
8. **Ground path** — Direct ground wire had no effect
9. **OutputDrive strength** — HighDrive had no effect on response detection

### Remaining Mystery
The scope shows the controller responds with a full packet at the XIAO pin. The GPIO register reads the pin correctly (PIN_CNF verified). But `wait_and_sample()` triggers on TX ringing (wait=4-20) instead of waiting for the real response (wait=~294).

**Why does the DK NOT see TX ringing?** Both boards use the same `write_packet()` → `set_input_mode()` → `wait_and_sample()` sequence. The DK cleanly transitions and waits ~294 cycles. The XIAO sees a false A LOW within 4-20 cycles.

**Possible causes still under investigation:**
1. **XIAO power rail settling** — After switching from output to input mode, the XIAO's 3.3V rail may glitch, causing a momentary LOW on pin A
2. **Pin capacitance / board routing** — XIAO's shorter, denser traces may hold output-mode charge longer, creating a ringing pulse
3. **Pull-up stabilization time** — `PULLUP_STABILIZE_NOPS=200` may not be enough on XIAO
4. **Need longer post-TX settling** — Add explicit delay after `set_input_mode()` before looking for A LOW

### Files Modified This Session
- `src/maple/host.rs` — Removed pre-TX and post-TX rprintln, removed unused import
- `src/maple/gpio_bus.rs` — HighDrive board-specific via `output_drive()` helper, condensed diagnostic output (RX FAIL / RX DECODE lines), all experimental changes reverted to original
- `src/main.rs` — Auto-enter sync mode when no bond
- `docs/dk_debug_log.md` — Updated with session entry
- `docs/xiao_debug_log.md` — This file (created and updated)

---

## Session: 2026-02-17 (Continued — GPIO Hardware Verification & Release Build Fix)

### ROOT CAUSE FOUND: Dev Build (No `--release`)

The XIAO was being flashed with `cargo embed --no-default-features --features board-xiao` (dev/debug build), while the DK was built with `cargo embed --release`. **This was the entire problem.**

### Why Dev Build Breaks Maple Bus

Embassy's `Flex::set_high()` / `set_low()` are thin wrappers around `OUTSET`/`OUTCLR` register writes, marked `#[inline]`. In a **release build**, they compile to single register writes. In a **dev build**:

- `#[inline]` is ignored — each pin toggle becomes 4+ nested function calls:
  `Flex::set_high() → SealedPin::set_high() → block() → outset() → write()`
- `write_bit()` has phase branching, making timing asymmetric
- `delay_half_bit()` NOP loops run ~300× slower due to unoptimized loop overhead
- Net effect: TX timing is completely wrong, controller doesn't recognize the request

### GPIO Hardware Verification (Pre-Discovery)

Before finding the build issue, verified GPIO hardware works perfectly:

1. **PIN_CNF registers confirmed correct:** `0x00000003` (DIR=1 output, INPUT=1 disconnect, PULL=0, DRIVE=0 S0S1)
2. **Direct register toggle test:** Wrote OUTSET/OUTCLR in a tight loop → clean 0V–3.3V square waves at ~250kHz (dev-mode speed), verified on scope with and without controller connected
3. **With controller at ~250kHz:** Full 0V–3.4V swing, some RC rounding but reaching rail-to-rail
4. **Conclusion:** GPIO hardware is fine; Embassy abstraction overhead in dev mode was the issue

### Test 12: Release Build on XIAO

```bash
cargo embed --release --no-default-features --features board-xiao
```

Results:
```
RX: start (b_trans=7 wait=178)
RX DECODE: bits=141 gaps=0 active=20049/24576 range=1..24575
RX: start (b_trans=5 wait=180)
RX DECODE: bits=141 gaps=0 active=20041/24576 range=0..24575
```

**Controller responding consistently!** b_trans=5-7, wait=175-182, bits=141 every attempt.

### New Issue: Buffer Too Small for Release Speed

In release mode, `read_p0_in()` runs much faster (~2-3 instructions/sample vs ~50+ in dev). The 24K sample buffer fills before the controller finishes responding:

- **141 bits captured** — only ~15% of the expected 936 bits (28-word Device Info Response)
- **gaps=0** — not seeing inter-chunk gaps because buffer exhausts during first chunk
- **active=20040/24576** (~82%) — most of buffer shows activity

Need to either add inter-sample delays or switch to on-the-fly decoding for release builds.

### Key Takeaway

**Always use `--release` for the XIAO build.** The Maple Bus protocol is timing-sensitive and relies on Embassy GPIO calls being inlined to single register writes. Dev builds destroy this timing.

---

## Session: 2026-02-18 (Perfboard Build — Pin Short & Power Routing)

### Setup
- XIAO nRF52840 soldered to perfboard
- Pololu U1V11F5 boost converter (battery → 5V for controller)
- 4.7kΩ pull-ups from data lines to 3.3V
- External SWD flashing via DK J-Link

### Problem: Controller Not Responding on Perfboard

Same XIAO and controller that worked on breadboard the night before. Symptoms:
- TX visible on scope at controller connector
- Pull-ups reading 3.2V on data lines
- Continuity tests passing
- Two different controllers tried — neither responds
- `BUS: Initial state A=1 B=1` — **B should be 0** (controller pulls SDCKB LOW at idle)

### Power Routing Discovery

XIAO 3.3V regulator cannot supply enough current for the Pololu boost converter + controller (~200mA+). Battery must feed Pololu VIN directly, not through the XIAO.

**Working power setup:**
```
Battery(+) ──── Pololu VIN (direct)
Battery(+) ──── XIAO BAT+ (through battery pads)
Battery(-) ──── XIAO BAT- (internally = GND)
Pololu GND ──── XIAO GND (common ground)
Controller GND ── XIAO GND (common ground)
Pololu VOUT ──── Controller 5V (blue wire)
XIAO D2 (P0.28) ── Pololu SHDN (enable)
```

### ROOT CAUSE: D4 (P0.04) Shorted to 3.3V

Added `diagnose_bus()` diagnostic — after each failed TX/RX attempt, samples 1000 reads and reports pin activity:
```
DIAG: A_low=0/1000 B_low=0/1000 trans=0 final A=1 B=1
```
Zero transitions, zero activity. Controller completely invisible.

**Key test:** Manually shorting red wire (SDCKA/D5) to GND → `A_low=1000/1000`, board stayed alive. Shorting white wire (SDCKB/D4) to GND → **board reset/disconnected.**

A 4.7kΩ pull-up to 3.3V should only draw ~0.7mA when grounded. Board resetting means D4 has a **direct short to a power rail** (bypassing the resistor), creating a hard short when grounded.

Further investigation: D2, D3, D4, and D6 all show continuity to 3.3V. These are on the same side of the XIAO. No visible solder bridge — may be underneath the castellated pads or within the perfboard.

### Fix: Moved SDCKB to D1 (P0.03)

Changed SDCKB from D4 (P0.04) to D1 (P0.03):
- `xiao.rs`: `PIN_B_BIT = 3` (was 4)
- `main.rs`: Pin assignment `p.P0_03` (was `p.P0_04`)
- Sync button pin reassigned to `p.P0_04` (non-functional, button physically removed)

Result:
```
BUS: Initial state A=1 B=1
MAPLE: Timeout
DIAG: A_low=0/1000 B_low=0/1000 trans=0 final A=1 B=1
MAPLE: Controller detected
```
**Controller detected on first retry!**

### Current Pin Mapping (Perfboard)
| Header | nRF Pin | Use |
|---|---|-----|
| D0 | P0.02 | Free (was wake button, no longer needed) |
| D1 | P0.03 | **SDCKB** (moved from D4) |
| D2 | P0.28 | Boost SHDN |
| D3 | P0.29 | **DEAD — shorted to 3.3V** |
| D4 | P0.04 | **DEAD — shorted to 3.3V** |
| D5 | P0.05 | SDCKA |
| D6 | P0.06 | Blue LED (shorted to 3.3V — LED may not work) |
| D7 | P1.12 | Sync button (also wake from System Off) |

### Robustness Improvements

1. **Controller re-detection**: After 30 consecutive poll failures, re-runs `request_device_info()` with backoff instead of polling forever with `get_condition()`.
2. **Sleep on controller loss**: If re-detection fails for 60s, enters System Off.
3. **Sleep on BLE reconnect timeout**: If bonded device doesn't reconnect within 60s, enters System Off.
4. **Sync button = wake button**: D7/P1.12 configured with GPIO SENSE LOW for System Off wake. No dedicated wake button needed — press sync to wake (full reboot).
5. **Post-disconnect state**: Returns to Reconnecting (if bonded) or Idle (if no bond).
6. **BLE without bond**: Auto-enters sync mode (discoverable).

### Lessons Learned
1. **Perfboard soldering can short adjacent pins** — especially with castellated pad boards like the XIAO. Shorts may be invisible (under the board).
2. **`diagnose_bus()` is invaluable** — zero transitions immediately pointed to a hardware issue, not software.
3. **Manual GND short test** differentiates between a pull-up path (safe to short, draws <1mA) and a direct power short (resets board).
4. **Battery must feed Pololu directly** — XIAO 3.3V regulator browns out under boost converter load.

---

## Session: 2026-02-19 (Inactivity Sleep + Battery Level Reporting)

### Changes

#### 1. Inactivity Sleep Timeout (10 minutes)

**Problem:** When the BLE host (Steam Deck) goes to sleep but keeps the connection alive, the adapter polls the controller and sends HID reports indefinitely, draining the battery overnight.

**Fix:** Track `last_activity` timestamp in the main polling loop. Reset it whenever `state_changed()` returns true or the controller is (re)detected. After 10 minutes with no input change, signal `SLEEP_REQUEST` to enter System Off.

- New constant: `INACTIVITY_TIMEOUT_MS = 600_000` (10 min), XIAO-only
- `last_activity` reset on: state change, initial detection, re-detection
- Check runs every poll cycle (16ms) in the main loop, before the poll sleep

#### 2. Battery Level via SAADC

**Problem:** Battery service hardcoded to 100% — never reflects actual charge state.

**Fix:** Read battery voltage via SAADC on P0.31 (AIN7) every 60 seconds.

**Hardware:** XIAO has a 1:2 voltage divider on P0.31, gated by P0.14 (HIGH = enable). This divides the LiPo voltage (3.0-4.2V) to the ADC-safe range (1.5-2.1V).

**Implementation:**
- `BatteryReader` struct in `src/board/xiao.rs` — holds SAADC peripheral + P0.14 enable pin
- 12-bit SAADC with internal 0.6V reference, 1/6 gain → 0-3.6V ADC range
- Battery voltage = ADC reading × 2 (divider)
- Linear mapping: 3.0V = 0%, 4.2V = 100%
- Enable pin driven HIGH for reading, LOW between reads to save power
- `BATTERY_LEVEL` signal carries percentage from main task to BLE task
- BLE task updates Battery Service characteristic + sends notification
- DK board: no battery circuit, stays at init value (100%)

**Files modified:**
- `src/main.rs` — Inactivity timeout, SAADC interrupt binding, battery reader init, periodic read in main loop, battery update in BLE connection handler
- `src/board/xiao.rs` — `BatteryReader` struct with `new()` and `read_percent()`

### Verification Plan
- Build: `cargo embed --release --no-default-features --features board-xiao`
- Check RTT log for `BAT: raw=... v=...mV ...%` lines
- Verify inactivity sleep triggers after 10 min idle (RTT: "Inactivity timeout")
- Verify wake via sync button after sleep
- Verify BLE battery level updates (non-100% value in host)

---

## 2026-02-19: Set Charge Current to 100mA

### Problem
Default BQ25101 charge current is 50mA (P0.13 floating), giving 20+ hour charge time for a 1000mAh LiPo.

### Change
Set P0.13 LOW at init to select 100mA charge rate (~10 hours for 1000mAh).

Added `charge_pin` parameter to `init_pins()` in `src/board/xiao.rs`. The pin is configured as output LOW and immediately dropped — the GPIO output latch persists the LOW state. No static storage needed since we never change it again.

### Files Modified
- `src/board/xiao.rs` — Added `charge_pin` param, set output LOW before returning
- `src/main.rs` — Pass `p.P0_13` to `init_pins()` (XIAO only; DK unchanged)

### Verification
- Build passes for both XIAO and DK targets
- Flash XIAO, plug USB — charge LED was NOT lit before or after this change
- P0.13 controls charge current (BQ25101 ISET), P0.17 controls charge LED (STAT)
- We don't touch P0.17, so charge LED issue is pre-existing / hardware
- **Still testing:** whether battery actually charges at 100mA despite LED not lighting

---

## Session: 2026-02-19 (Code Review Cleanup)

Ran a 4-persona RALPH code review (Architect, Code Reviewer, Security Auditor, Performance Engineer). Triaged all findings — implemented the valid ones, skipped the rest after analysis.

### Changes Implemented

**1. Simplified `state_changed()` in `dc-protocol/src/controller_state.rs`**
Replaced 9 individual button field comparisons with a single `self.buttons.to_raw() != other.buttons.to_raw()` check. Cleaner and automatically covers all button fields.

**2. Added `[profile.release]` to `Cargo.toml`**
- `opt-level = "s"` (size — often faster on Cortex-M due to flash prefetch/I-cache)
- `lto = "fat"` (critical for inlining timing code across crate boundaries)
- `codegen-units = 1` (maximum optimization)
- `debug = 2` (keep debug info for probe-rs)

**3. Broke `main.rs` into modules**
Extracted ~480 lines from `main.rs` into:
- `src/ble/task.rs` — BLE advertising/connection state machine + `handle_connection()`
- `src/button.rs` — sync button monitoring task (hold, triple-press)
- `src/lib.rs` — shared signals (`CONTROLLER_STATE`, `SYNC_MODE`, `NAME_TOGGLE`, `BATTERY_LEVEL`) and constants moved here so library modules can reference them via `crate::`

`main.rs` now only contains the entry point, Maple Bus polling loop, and `softdevice_task`.

**4. Compile-time size assertion for `transmute` in `flash_bond.rs`**
Added `const _: () = assert!(size_of::<IdentityResolutionKey>() == 16);` to catch breakage if `nrf-softdevice` changes the struct layout.

**5. Name length safety in `softdevice.rs`**
- Replaced hardcoded `29u16`/`24u16` with `(NAME_DREAMCAST.len() - 1) as u16` (derived from the actual string)
- Added const assertions that scan response array sizes match name string lengths

**6. Reduced heapless Vec capacities**
- `MaplePacket::payload`: `Vec<u32, 255>` → `Vec<u32, 32>` (saves ~900 bytes stack)
- `decode_bulk_samples` bits: `Vec<u8, 1024>` → `Vec<u8, 960>` (saves ~64 bytes)
- Overflow is already handled gracefully (silent drop → CRC fail → retry)

### Review Findings Skipped (with rationale)

- **Cache BLE report bytes**: `to_gamepad_report()` + `to_bytes()` costs <1µs. Real Xbox controllers send every connection event without caching.
- **Early-exit in `decode_bulk_samples`**: Needs full pass for gap detection counters. ~100-200µs per 16ms cycle is negligible.
- **Third advertising interval tier**: Only a 5-60s window before System Off. Power difference is ~0.5mA vs ~40mA boost converter draw.
- **Replace `static mut` with Mutex<RefCell>**: Both `BOOST_CONTROL` and `SAMPLE_BUFFER` have well-documented safety invariants. Single-core, no concurrency. Mutex adds overhead with zero practical benefit.

### Files Modified
- `dc-protocol/src/controller_state.rs` — `state_changed()` simplification
- `dc-protocol/src/packet.rs` — payload Vec capacity 255→32
- `Cargo.toml` — `[profile.release]` section
- `src/lib.rs` — shared signals/constants, new module declarations
- `src/main.rs` — simplified to polling loop + entry point
- `src/ble/task.rs` — NEW: extracted BLE task
- `src/ble/mod.rs` — added `task` module
- `src/button.rs` — NEW: extracted sync button task
- `src/ble/flash_bond.rs` — transmute size assertion
- `src/ble/softdevice.rs` — computed name lengths + const assertions
- `src/maple/gpio_bus.rs` — Vec capacity reductions
- `src/maple/host.rs` — payload Vec capacity 255→32
- `check.sh` — auto-format instead of check-only

---

## Session: 2026-02-19 (Button Pin, Bond Persistence, Responsiveness)

### Button Pin Move: D7 → D10
- D7 (P1.12) was shorted to ground on the perfboard — button always read LOW
- Moved sync/wake button to D10 (P1.15)
- Updated `src/main.rs` (pin pass), `src/board/xiao.rs` (WAKE_PIN_NUM, docs)
- Sleep/wake confirmed working on D10

### Bond Persistence Fix
- Bond was only saved to flash on graceful disconnect (in `handle_connection` after GATT ends)
- Inactivity timeout called `enter_system_off()` directly, bypassing the save
- Fix: added a concurrent `bond_save_future` that polls every 1s until pairing completes, then saves
- On wake, device now reconnects to bonded host automatically

### Name Toggle Fix
- `NAME_TOGGLE` signal was only checked between connection cycles (top of `ble_task` loop)
- While connected, the signal was never consumed — triple-press had no effect
- Fix: `bond_save_future` also polls for `NAME_TOGGLE` after bond save, triggers flash write + reset

### Stale SYNC_MODE Signal Fix
- `SYNC_MODE` signaled during SyncMode was never consumed in that branch
- After disconnect → Reconnecting, the stale signal immediately cleared the bond
- Fix: drain stale signal at top of SyncMode branch

### Stick/Trigger Responsiveness
- `STICK_CHANGE_THRESHOLD` was 15 (~6% of 0-255 range) — felt sluggish
- `TRIGGER_CHANGE_THRESHOLD` was 10 (~4%)
- Both reduced to 2 — much more responsive, deadzone in `to_gamepad_report()` handles noise at center

### Sleep Cleanup
- LEDs now turn off before entering System Off (direct P0 OUTSET register write)
- Single "Entering System Off" log line instead of multiple diagnostic logs

### Files Changed
- `src/board/xiao.rs` — D10 pin, LED off before sleep, simplified sleep entry
- `src/main.rs` — P1.15 pin, removed bus state diagnostic
- `src/ble/task.rs` — bond_save_future, name toggle during connection, stale signal drain
- `src/button.rs` — removed debug logging (pin state, state transitions, press detection)
- `dc-protocol/src/controller_state.rs` — thresholds 15/10 → 2/2
- `src/maple/gpio_bus.rs` — fixed clippy cast_lossless warnings

---

## 2026-02-20: Battery Life Optimization — Gate Boost on BLE Connection

### Problem
System draws ~120mA while active but BQ25101 charges at only 100mA — battery drains even when plugged into USB. The boost converter + Dreamcast controller (~60-80mA) is the dominant consumer and serves no purpose when BLE is disconnected.

### Changes

**Restructured main loop to gate controller polling on BLE connection state:**
1. Boot → init pins (boost OFF) → start BLE advertising
2. Wait for BLE connection (check `get_connection_state() == Connected`)
3. Enable boost → detect controller → enter poll loop
4. On BLE disconnect → disable boost → LEDs off → loop back to waiting
5. Inactivity/timeout → System Off (unchanged)

**Enabled REG1 DCDC converter** (XIAO only):
- `config.dcdc.reg1 = true` — confirmed safe, XIAO has inductor (verified via Zephyr DTS)
- Free efficiency gain during radio activity (~2-3mA savings)
- Do NOT enable REG0 (no inductor on XIAO, VDDH tied to VDD)

**Boost init changed to OFF:**
- `init_pins` now starts boost LOW instead of HIGH
- Added `enable_boost()` alongside existing `disable_boost()`
- Boost only turns on after BLE connection established

**Added `StatusLeds::off()` to both board files:**
- LEDs turn off when BLE disconnects (no point showing status with no host)

**Battery/charge monitoring continues during BLE wait phase:**
- Low battery cutoff still works while advertising
- Charge status changes still logged

### Expected Effect
- Advertising/idle: ~15mA instead of ~120mA (boost off, no Maple Bus polling)
- Battery can actually charge on USB (100mA charge > 15mA draw)
- Active gaming: unchanged ~120mA
- With typical 50/50 usage: ~7-8 hours on 500mAh vs ~4 hours before

### Files Changed
- `src/main.rs` — restructured main loop, DCDC enable, BLE connection gating
- `src/board/xiao.rs` — boost init LOW, added `enable_boost()`, added `StatusLeds::off()`
- `src/board/dk.rs` — added `StatusLeds::off()` (API parity)

---

## 2026-02-20: Power Optimization Round 2 — QSPI Flash, Pin Disconnect, HighDrive

### Changes

**1. QSPI flash Deep Power Down (biggest find):**
- P25Q16H flash on XIAO draws 2-5 mA in standby — we never use it
- This was likely the hidden reason System Off current was milliamps, not ~5 µA
- Added `qspi_flash_deep_power_down()` in `xiao.rs` using raw QSPI register writes
- Sends DPD command (0xB9) at startup, before SoftDevice init
- CS (P0.25) kept driven HIGH after DPD to prevent accidental wake (known Zephyr issue)
- Other 5 QSPI pins disconnected

**2. Maple Bus pin disconnect when not polling:**
- Added `MapleBus::set_low_power()` — calls `set_as_disconnected()` on both data pins
- Called when entering BLE wait phase (Phase 1 of main loop)
- With pins disconnected, external pull-ups hold both lines at 3.3V, zero current
- Pins auto-restore when `write_packet()` calls `set_output_mode()` on next poll
- Saves 0.7 mA (SDCKB pull-up was fighting pin driver continuously)

**3. Pin disconnect before System Off:**
- Added raw PIN_CNF writes in `enter_system_off()` for SDCKA, SDCKB, charge STAT
- GPIO state survives System Off on nRF52840 — must explicitly disconnect
- Without this fix, SDCKB was wasting 0.7 mA throughout entire sleep period

**4. HighDrive mode for Maple Bus TX:**
- Changed `OutputDrive::Standard` → `OutputDrive::HighDrive` in all gpio_bus.rs calls
- Output impedance drops from ~1.65kΩ to ~550Ω, rise time 363ns → 121ns
- Free signal quality improvement, no power cost
- Better foundation for potential future move to higher-resistance pull-ups

**5. Slower reconnect advertising:**
- Changed slow reconnect interval from 100ms (160 units) to 500ms (800 units)
- Bonded hosts still reconnect within 2-4 seconds
- Saves ~22 µA during slow reconnect phase

### Expected Effect
- System Off: should drop from ~2-5 mA to ~5-8 µA (QSPI flash was the hidden drain)
- Advertising/idle: ~12 mA instead of ~17 mA (QSPI + pin disconnect)
- Active gaming: ~118 mA instead of ~122 mA (QSPI DPD savings)

### Files Changed
- `src/board/xiao.rs` — QSPI DPD function, pin disconnect in enter_system_off()
- `src/maple/gpio_bus.rs` — HighDrive mode, set_low_power() method
- `src/main.rs` — QSPI DPD call at startup, bus.set_low_power() in BLE wait phase
- `src/ble/softdevice.rs` — reconnect advertising interval 160 → 800

---

## 2026-02-20: QSPI DPD Fix + Startup Battery Read

### Problem
QSPI peripheral approach for flash DPD was unreliable on hardware:
1. First attempt: hung on `TASKS_ACTIVATE` — missing `IFCONFIG0`/`IFCONFIG1` register config
2. After adding config: `CINSTRCONF` register offset was wrong (`0x604` = read-only STATUS, should be `0x634`)
3. After fixing offset: `TASKS_DEACTIVATE` doesn't trigger `EVENTS_READY` (timeout)
4. After removing deactivate wait: `TASKS_ACTIVATE` failed again (peripheral wedged from previous partial deactivate)

### Solution
Replaced entire QSPI peripheral approach with GPIO bit-bang SPI:
- Configure CS (P0.25), SCK (P0.21), IO0/MOSI (P0.20) as GPIO outputs
- Bit-bang 0xB9 (DPD command) in SPI mode 0, MSB first
- Deassert CS → flash enters DPD
- Keep CS driven HIGH, disconnect SCK/IO0-IO3

This is simpler, more reliable, and avoids all QSPI peripheral state machine issues.

### Battery Read at Startup
Battery percentage wasn't appearing in logs because BLE connects so fast (~500ms with bonded device) that the wait phase battery read never fires. Added an immediate battery read right after startup blink, before entering main loop.

### Battery Voltage History
| Date | Reading | State | Notes |
|---|---|---|---|
| 2026-02-19 | 4455mV | USB 5V bleed-through | Not a real battery reading |
| 2026-02-19 | 160mV | Trickle pre-charge | Deeply discharged LiPo |
| 2026-02-19 | 3874mV / ~73% | Charging | First real working reading |
| 2026-02-19 | 3869mV / ~72% | Charging | ~1hr later, draining (system > charger) |
| 2026-02-19 | 3601mV / ~50% | Unplugged | Battery-only operation |
| 2026-02-20 | 3832mV / 69% | Charging | After ~15min on charger |

### Hardware Observation
RTT log output (clean, no timeouts):
```
DC Adapter Starting
QSPI: Flash in Deep Power Down
Name: Xbox Wireless Controller
BLE: Advertising (fast reconnect)
BLE: Connected!
PWR: Charging
BAT: 3832mV 69%
MAIN: Waiting for BLE connection...
MAIN: BLE connected, enabling controller
```

### Files Changed
- `src/board/xiao.rs` — rewrote `qspi_flash_deep_power_down()` as GPIO bit-bang
- `src/main.rs` — added initial battery read at startup

---

## Session: 2026-02-23 — System Off Power Hardening

### Problem
Battery drained overnight despite System Off. Two issues identified:
1. **Phase 2 (controller detection) has no timeout** — if BLE connects (e.g., Mac auto-reconnects) but no controller is plugged in, the device retries forever with boost potentially enabled. This is the likely overnight drain cause.
2. **Only 3 GPIO pins disconnected in `enter_system_off()`** — remaining configured pins (LEDs, ADC, charge STAT) leak microamps through output drivers or pull resistors.

### Changes

**`src/board/xiao.rs` — Expanded pin disconnect in `enter_system_off()`**
Previously disconnected: P0.05 (SDCKA), P0.03 (SDCKB), P0.17 (charge STAT)
Now also disconnects: P0.06 (LED B), P0.14 (ADC enable), P0.26 (LED R), P0.30 (LED G), P0.31 (ADC input)

Pins intentionally kept driven:
- P0.25: QSPI CS HIGH (keeps flash in Deep Power Down)
- P0.28: Boost SHDN LOW (keeps boost off)
- P0.13: Charge ISET LOW (keeps BQ25101 at 100mA rate)
- P1.15: Wake button with SENSE LOW (wake source, unchanged)

**`src/main.rs` — Added 60s timeout to Phase 2 controller detection**
New constant `DETECT_TIMEOUT_MS = 60_000`. If no controller is found within 60 seconds of BLE connecting, enters System Off. This prevents the scenario where BLE auto-reconnects but no controller is present, keeping the device awake indefinitely.

### Expected Effect
- System Off current should drop closer to the theoretical ~5µA
- Device will no longer stay awake indefinitely when BLE connects without a controller
- Wake via sync button (P1.15 SENSE LOW) is preserved — pin not touched by disconnect changes

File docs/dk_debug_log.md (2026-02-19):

# Maple Bus Debug Log

Running log of tests, assumptions, and results for the Dreamcast controller adapter project.

---

## Current State

**Date:** 2026-02-17

**Status:** Both DK and XIAO working. XIAO root cause was building without `--release` — Embassy GPIO calls not inlined in debug builds, destroying TX timing.

**See also:** `docs/xiao_debug_log.md` for full XIAO investigation details.

---

## Session: 2026-02-17 (XIAO + DK Maple Bus Debugging)

### DK Baseline (CONFIRMED WORKING)

Flashed DK with current code (includes diagnostics + hot-path fix). Controller detected, BLE works.
```
RX: start pattern found (b_trans=5, wait=228)
RX DECODE: bits=139 a_falls=70 b_falls=69 gaps=0 first_edge=4
```
- **139 bits** — first chunk (frame word + ~3 payload words), enough for controller detection
- **Deterministic** — same result every run, consistent b_trans and timing
- **NOTE:** 139 bits is less than full 936-bit Device Info Response, but frame word decodes correctly and controller detection succeeds. Previous 937-bit captures included all 7 chunks; current code may stop after first successful frame decode.

### XIAO Investigation

**Problem:** XIAO build captures 20-34 bits. First bits are **random each run** — not a real controller response. Controller never detected.

**Confirmed fix:** Removed rprintln from TX→RX hot path in `host.rs`. Improved XIAO from 10-13 to 20-34 bits.

**Disproved hypotheses:**
- SoftDevice interrupts (REVERTED — crashed SoftDevice, bits unchanged)
- MIN_START_TRANSITIONS=6 (REVERTED — no effect, kept at 3)
- Internal pull-ups Pull::None (REVERTED — no effect)
- I2C pin IMU interference (board is regular variant, no IMU)

**Root cause found:** XIAO pull-ups wired through a **voltage divider** off 5V to create a 3.3V reference. A voltage divider is high-impedance — can't supply current at 2Mbps edge rates. Signal degrades after ~30 edges as divider sags under load. The XIAO has a `3V3` pin that should be used directly for pull-ups.

### Hardware Setup Clarification
- **DK**: 47Ω inline resistors on data lines + 4.7kΩ pull-ups to 3.3V (voltage divider from 5V)
- **XIAO**: No inline resistors + 4.7kΩ pull-ups to direct 3V3 pin
- **Key difference**: 47Ω inline resistors (present on DK, absent on XIAO)
- Earlier hypothesis that XIAO's voltage divider pull-ups were the problem was **incorrect** — the DK also uses a voltage divider and works fine

### Changes Kept
1. **Removed pre-TX and post-TX rprintln** (`src/maple/host.rs`) — verified improvement
2. **Added edge timing diagnostics** (`src/maple/gpio_bus.rs`) — post-capture only, no hot-path impact
3. **Auto-enter sync mode** (`src/main.rs`) — when no bond found
4. **MIN_START_TRANSITIONS = 3** — unchanged from working DK value (per learnings.md)

### Hardware Setup
- DK: 4.7kΩ pull-ups from data lines to DK 3.3V rail (direct)
- XIAO: 4.7kΩ pull-ups from data lines through voltage divider off 5V (weak!)
- Controller powered from DK 5V output

---

## Session: 2026-02-10 (XIAO Board Support + Power Management)

### What Changed
Added a board abstraction layer so the same firmware supports both the nRF52840-DK (development) and XIAO nRF52840 (production VMU shell) via Cargo feature flags.

### Architecture
- **Feature flags:** `board-dk` (default) and `board-xiao` in `Cargo.toml`
- **Board module:** `src/board/mod.rs` conditionally includes `dk.rs` or `xiao.rs`
- Each board exports: `init_pins()`, `StatusLeds`, `PIN_A_BIT`/`PIN_B_BIT` constants
- `gpio_bus.rs` pin masks now derived from `board::PIN_A_BIT`/`PIN_B_BIT`

### Pin Mappings

**DK** (unchanged):
| Function | Pin | Notes |
|---|-----|---|
| SDCKA | P0.05 | Maple bus line A |
| SDCKB | P0.06 | Maple bus line B |
| LED1 (sync) | P0.13 | Active LOW |
| LED2-4 (status) | P0.14-16 | Active LOW |
| Sync button | P0.25 | Active LOW, pull-up |

**XIAO**:
| Function | Pin | Header | Notes |
|---|-----|---|---|
| SDCKA | P0.05 | D5 | Same as DK |
| SDCKB | P0.04 | D4 | Remapped (P0.06 = XIAO blue LED) |
| RGB LED R | P0.26 | internal | Active LOW |
| RGB LED G | P0.30 | internal | Active LOW |
| RGB LED B | P0.06 | internal | Used as sync LED |
| Sync button | P0.29 | D3 | VMU MODE button |
| Wake button | P0.02 | D0 | VMU SLEEP button, GPIO SENSE wake |
| Boost SHDN | P0.28 | D2 | Pololu enable (HIGH=on) |

### XIAO LED Status
- Searching: Red solid
- Controller found: Green solid
- Sync mode: Blue fast blink (via sync button task)
- TX activity: no-op (avoid flicker on single RGB LED)

### XIAO Power Management
- **Auto-sleep:** After BLE disconnect, reconnect timeout (60s) triggers System Off
- **System Off entry:** Disables 5V boost (SHDN LOW), configures P0.02 SENSE LOW, calls `sd_power_system_off()`
- **Wake:** Press VMU SLEEP button → GPIO SENSE triggers full reset → boots fresh, reconnects via bond
- **Expected draw:** ~5µA in System Off

### Files Created
- `src/board/mod.rs` — Board abstraction module root
- `src/board/dk.rs` — DK pin mappings, 4 LEDs, no sleep
- `src/board/xiao.rs` — XIAO pin mappings, RGB LED, boost control, sleep

### Files Modified
- `Cargo.toml` — Added `board-dk`/`board-xiao` features
- `src/lib.rs` — Added `pub mod board`
- `src/main.rs` — Uses `board::init_pins()` + `StatusLeds` methods, XIAO sleep signal
- `src/maple/gpio_bus.rs` — Pin masks use `board::PIN_A_BIT`/`PIN_B_BIT`

### Build Commands
```sh
cargo build                                              # DK (default)
cargo build --features board-xiao --no-default-features  # XIAO
```

### Verification
- `cargo build` — DK clean ✓
- `cargo build --features board-xiao --no-default-features` — XIAO clean ✓
- `cargo clippy -- -W clippy::all -W clippy::pedantic` — 0 warnings (both) ✓
- `cargo fmt --check` — clean ✓

### What's Next
1. Flash DK — verify existing functionality unchanged
2. When XIAO arrives: flash, verify Maple bus, BLE, sleep/wake, boost control
3. Battery ADC reading (P0.31 via P0.14 enable) — future

---

## Session: 2026-02-09 (Xbox One S BLE Format Alignment)

### Problem
Hardware tester showed "insane" analog values — stick values going in and out "like a flower." Device didn't work with iBlueControlMod (Dreamcast Bluetooth adapter from Handheld Legend). Previous Sonnet session made uncommitted changes (Xbox rename, event-driven reporting) that were reverted.

### Root Cause Analysis
Researched the real Xbox One S BLE HID descriptor (Model 1708, PID 0x02E0) and compared to our implementation. Found **5 critical mismatches**:

| Issue | Our Code (Before) | Real Xbox One S |
|---|---|---|
| Stick range | **signed** -32768..32767 | **unsigned** 0..65535, center=32768 |
| Field order | buttons, hat, sticks, triggers | **sticks, triggers, hat, buttons** |
| Right stick usages | Rx (0x33) / Ry (0x34) | **Z (0x32) / Rz (0x35)** |
| Trigger usages | Generic Desktop Z/Rz | **Sim Controls Brake (0xC5) / Accel (0xC4)** |
| Trigger packing | 16-bit fields | **10-bit + 6 padding bits** |
| Report size | 15 bytes | **16 bytes** |
| Buttons | 16 | **15 + AC Back separate** |

The "flower" behavior was caused by the signed/unsigned stick mismatch — our center value of 0 was interpreted as far-left (0 in unsigned range) instead of center (32768).

The field order mismatch meant the receiver was parsing our button bytes as stick position data.

### Research: iBlueControlMod
- Product from Handheld Legend, ESP32-based
- Explicitly **NOT** standard BlueRetro — "Upgrading to BlueRetro firmware will damage this product"
- Different GPIO pinout from stock BlueRetro
- Identifies controllers by name ("Xbox Wireless Controller") then HID descriptor fingerprinting
- Supports Xbox One S, Xbox Series X|S, PS3/4/5, Switch Pro, etc.

### Research: Xbox One S BLE Timing
- Internal firmware runs at ~100Hz
- BLE connection interval: 7-9 units (8.75-11.25ms)
- Slave latency: 0 (never skip events)
- Xbox controller has a bug where it doesn't advertise PPCP — hosts fall back to slow 30-50ms intervals
- We set PPCP explicitly via `sd_ble_gap_conn_param_update()`
- Fixed-rate continuous reporting, not event-driven

### Changes Made

#### `src/ble/hid.rs` — Complete HID rewrite
- **Descriptor**: Full 334-byte Xbox One S descriptor with 4 Report IDs:
  - ID 0x01: Main gamepad (16 bytes) — sticks, triggers, hat, buttons, AC Back
  - ID 0x02: Xbox/Guide button (1 byte, AC Home usage)
  - ID 0x03: Rumble output (9 bytes)
  - ID 0x04: Battery (1 byte)
- **Sticks**: Unsigned 0-65535 in Physical collections, X/Y and Z/Rz usages
- **Triggers**: Simulation Controls page, Brake/Accelerator, 10-bit with explicit 6-bit const padding
- **Buttons**: 15 buttons (Usage Min 1, Max 15) + 1-bit padding + AC Back (Consumer 0x0224) in own byte
- **Report struct**: `GamepadReport` fields now `u16` for sticks (not `i16`)
- **`to_bytes()`**: 16-byte output matching Xbox byte layout exactly
  - Right stick hardcoded to `0x00, 0x80` (32768 = center, LE)
  - Triggers masked to `& 0x03FF` before packing
- **Report map Vec**: Capacity 128 → 512 to fit larger descriptor
- **Device info**: Manufacturer "Microsoft", Model "Xbox Wireless Controller"
- Removed D-pad button constants (DPAD_UP/DOWN/LEFT/RIGHT) — D-pad is hat-only now

#### `src/maple/controller_state.rs` — Stick/trigger conversion
- **Sticks**: `u8 * 257` → unsigned `u16` (maps 0→0, 128→32896≈32768, 255→65535)
  - Deadzone outputs 32768 (center) instead of 0
- **Triggers**: `val * 1023 / 255` for exact 8-bit to 10-bit scaling
- Removed unused `to_ble_bytes()`

#### `src/ble/softdevice.rs` — Identity & connection
- Device name: "Xbox Wireless Controller" (was "Dreamcast Wireless Controller")
- Scan data: Updated to match new name (26 bytes, was 31)
- `event_length`: 6 (was 24) — allows shorter connection events for fast intervals
- `attr_tab_size`: 2048 (was 1024) — more room for the larger GATT table

#### `src/main.rs` — Connection parameters
- After connection + security: requests conn interval 7-9 (8.75-11.25ms), slave latency 0, supervision timeout 4000ms via `sd_ble_gap_conn_param_update()`
- Existing 8ms fixed-rate report loop unchanged (≈125Hz, matches Xbox)

### Expected Behavior After Flash
1. Device advertises as "Xbox Wireless Controller" with gamepad appearance
2. iBlueControlMod should recognize it by name and/or descriptor fingerprint
3. Sticks should report center=32768 at idle (not 0)
4. Triggers should report 0 at idle, 1023 fully pressed
5. Connection should negotiate ~10ms interval for ~100Hz report rate
6. All 16 bytes of each report should be parseable by the receiver

### Hardware Test Result (first flash)
- Triggers showed up as "R STICK AXIS 2 / AXIS 3" on tester, not as triggers
- Default position was -1.00000 (should be 0)
- Root cause: Raw Xbox descriptor uses Z/Rz for right stick and Brake/Accelerator (Simulation Controls page) for triggers. Most HID parsers map Z/Rz to triggers instead, so our right stick data appeared as triggers and actual trigger data was unrecognized.

### Fix Applied: xpadneo-patched Usage Convention
Changed the HID descriptor to use the standard convention that the xpadneo Linux driver patches Xbox descriptors to:
- **Right stick**: Z/Rz → **Rx (0x33) / Ry (0x34)** on Generic Desktop
- **Triggers**: Sim Controls Brake/Accelerator → **Z (0x32) / Rz (0x35)** on Generic Desktop

This is the universal gamepad convention (X/Y = left stick, Rx/Ry = right stick, Z/Rz = triggers).
Byte layout unchanged — only the HID usage tags in the descriptor changed.

### What To Watch For
- Does iBlueControlMod pair and connect?
- Are stick values sane on hardware tester? (should be ~32768 at center)
- Do buttons register correctly? (A=bit0, B=bit1, X=bit2, Y=bit3)
- Is D-pad working via hat switch?
- Are triggers smooth 0-1023, showing 0 at idle?
- Triggers should now appear as trigger axes, not right stick
- Any disconnections or instability?

---

## Previous State

**Date:** 2026-02-06

**Status:** Full response now captured (937 bits, 7 inter-chunk gaps). Phase alignment remains the key issue - decoded bytes are wrong due to starting with B edge instead of A edge.

---

## Session: 2026-02-06 (Buffer Expansion & Phase Debugging)

### Major Changes Made

1. **Buffer size increased: 4096 → 24576 samples**
   - Now captures full 28-word response + all inter-chunk gaps
   - Uses static buffer (`static mut SAMPLE_BUFFER`) to avoid stack allocation delay
   - Previous stack allocation of 96KB caused us to miss the response entirely

2. **Bits vector increased: 512 → 1024 capacity**
   - Full response is 936 bits, now have headroom

3. **Sampling changed: at-edge instead of after-edge**
   - Was: `samples[i+1]` (one sample after edge)
   - Now: `samples[i]` (at the edge)
   - `find_first_edges` was showing different values than `decode_bulk_samples`

4. **b_trans threshold lowered: 5 → 3**
   - Was getting inconsistent start pattern detection (sometimes 3, sometimes 5+)

### Test Results

**Test 26: Full Response Capture (14:14:30)**
```
RX BULK: wait_cycles=280 b_trans=5
RX BULK: Captured 24576 samples
RX BULK: Initial state A=0 B=0  ← Both LOW = mid-transmission!
RX BULK: First 20 samples:
  AB: 0000010101010101010101010000000000101010
RX BULK: First edge at sample 12
RX BULK: Edge gaps (first 20):
  e0: gap=0 B data=0   ← First edge is B, not A!
  e1: gap=16 A data=0
  e2: gap=14 B data=1
  e3: gap=16 A data=1
  ... (alternating B-A-B-A pattern)
RX BULK: Decoded 937 bits (A falls=469, B falls=469, gaps=7)
RX BULK: First 40 bits: 0111000010000000000000000001010000000100
RX BULK: First 8 bytes: C2 00 00 50 10 00 00 0F
RX BULK: Frame = 0x500000C2
```

**Key Observations:**
- **937 bits captured** - Full response! (expected ~936)
- **7 gaps detected** - Matches expected inter-chunk boundaries
- **469 A falls, 469 B falls** - Symmetric edge detection
- **Initial state A=0 B=0** - We're starting mid-transmission

### Root Cause Analysis: Phase Alignment

**The Problem:**
After `wait_for_start_silent()` returns, we expect:
- State: A=HIGH, B=LOW (ready for Phase 1)
- First data edge: A falls (Phase 1)

**What we're seeing:**
- State: A=LOW, B=LOW (both LOW!)
- First edge detected: B falls (e0)
- This means A has ALREADY fallen before we started sampling

**Why this happens:**
The controller starts sending data immediately after the start pattern. Between `wait_for_start_silent()` returning and `bulk_sample()` starting, the first clock edge (A falling) has already occurred.

**Bit Shift Effect:**
- When first edge is B (wrong): bits are `10001110...` → byte 0 = 0x39
- When first edge is A (correct): bits are `00011100...` → byte 0 = 0x1C
- The bits are shifted by 1 position!

### Sample Pattern Analysis

First 20 samples decoded:
```
Sample  0-1:  A=0, B=0  ← Mid-bit, both transitioning
Sample  2-11: A=0, B=1  ← B is HIGH (data value)
Sample 12:    A=0, B=0  ← B falls! (this is e0)
Sample 13-16: A=0, B=0  ← Both LOW
Sample 17+:   A=1, B=0  ← A rises!
```

This shows we captured DURING the first data bit, not at its start.

### THE FIX THAT WORKED

**Created `wait_and_sample()` function** that combines start pattern detection with bulk sampling:
- Samples IMMEDIATELY when A goes HIGH at end of start pattern
- No function return delay between detection and sampling
- This captures the first clock edge (A falling) correctly

**Result:**
```
RX BULK: Frame = 0x0500201C
- cmd = 0x05 ✓ (Device Info Response)
- sender = 0x20 ✓ (Controller in Port A)
- recipient = 0x00 ✓ (Host)
- length = 0x1C (28) ✓ (28 payload words)
```

**FRAME WORD DECODED CORRECTLY!**

### Key Changes That Fixed It

1. **Combined wait + sample function** - No return delay between detecting start pattern end and beginning sampling
2. **Sample AT edge** - `samples[i]` instead of `samples[i+1]`
3. **SKIP_BITS = 0** - Now properly aligned, no bit skipping needed
4. **b_trans threshold = 3** - More lenient start pattern detection

### Current Code State

**wait_and_sample():** Combines wait-for-start + bulk sampling in one function
**decode_bulk_samples():** Samples AT edge, skips B edges until first A fall seen
**SKIP_BITS:** 0 (no skip needed now that timing is correct)

---

## Previous State (2026-02-05)

**Key Finding:** Using `wait_for_start_silent()` with zero prints + bulk sampling captures clean edge data. Seeing ~14 samples per edge (~218ns), close to expected 250ns/phase. But decoded bits don't match expected frame content.

**Hardware:**
- nRF52840-DK
- Genuine Dreamcast controller
- Wiring: Red→P0.05 (SDCKA), White→P0.06 (SDCKB), Green→GND (sense), Blue→5V, Black→GND

**Latest Output (Test 24 - Bulk Sampling):**
```
RX BULK: wait_cycles=233 b_trans=8  ← Perfect! 8 B transitions = 4 toggle cycles
RX BULK: Captured 4096 samples
RX BULK: First 16 samples (A,B): [all A=1 B=0]  ← Correct idle state!
RX BULK: First 20 edges:
  [ 385] A fell, data=0
  [ 400] B fell, data=1
  [ 416] A fell, data=1
  [ 427] B fell, data=1
  [ 442] A fell, data=0
  ...
RX BULK: Decoded 196 bits (A falls=98, B falls=98)
RX BULK: First 8 bytes: 47 36 17 46 E6 F4 36 C6  ← Not matching expected
```

**Expected Frame:**
```
Frame = 0x05 00 20 1C (command=0x05, recipient=0x00, sender=0x20, length=0x1C)
Bytes transmitted (LSB first): 1C 20 00 05
First byte bits: 0 0 0 1 1 1 0 0 = 0x1C
```

**Got:**
```
First 8 bits: 0 1 1 1 0 1 0 0 = 0x74  ← Some bits match, some don't
```

**Bit Comparison (first byte):**
| Bit | Expected | Got | Match |
|-----|---|-----|---|
| 0 | 0 | 0 | ✓ |
| 1 | 0 | 1 | ✗ |
| 2 | 0 | 1 | ✗ |
| 3 | 1 | 1 | ✓ |
| 4 | 1 | 0 | ✗ |
| 5 | 1 | 1 | ✓ |
| 6 | 0 | 0 | ✓ |
| 7 | 0 | 0 | ✓ |

5 of 8 bits match. Pattern suggests possible timing skew or signal integrity issue.

---

## Next Session: Test Routes

### Route 1: Scope First (Recommended)
**Effort:** Low | **Risk:** Low | **Info Gain:** High

Use the digital scope to verify our assumptions before changing more code.

**Steps:**
1. Connect Ch1 to SDCKA (P0.05/Red), Ch2 to SDCKB (P0.06/White)
2. Trigger on falling edge of Ch1
3. Send Device Info Request, capture response
4. Measure:
   - Idle state (should be both HIGH ~3.3V)
   - Start pattern duration (~4µs)
   - Bit timing (~500ns per phase)
   - Response delay after our TX ends

**What we'll learn:**
- Are signals clean or noisy?
- Is timing as expected (~250ns/phase from controller)?
- Are we seeing proper voltage levels?

---

### Route 2: Bulk Sampling (Most Likely Fix)
**Effort:** Medium | **Risk:** Low | **Info Gain:** Medium

Implement the "sample everything, decode later" approach that worked for raphnet.

**Steps:**
1. Create 256-entry u32 array for samples
2. After start pattern, tight loop: `samples[i] = p0_in.read().bits()`
3. After sampling, scan for falling edges and extract bits
4. Compare decoded frame to expected

**Code sketch:**
```rust
let mut samples: [u32; 256] = [0; 256];
for i in 0..256 {
    samples[i] = p0_in.read().bits();
}
// Post-process: find edges, extract bits
```

**Why it might work:**
- Eliminates timing-critical decisions during receive
- raphnet had same issues, this fixed them
- At 64MHz, 256 samples = ~4µs coverage (enough for frame word)

---

### Route 3: Tune Current Approach
**Effort:** Low | **Risk:** Medium | **Info Gain:** Low

Small tweaks to existing edge detection code.

**Options to try:**
1. **Add 1-2 NOPs after edge detect** - let signal settle
2. **Invert Phase 2 samples** - maybe we have logic backwards
3. **Start with phase=false** after specific delay
4. **Increase timeout** significantly

**Quick tests:**
```rust
// Option 1: Small settling delay
if (val & PIN_A_MASK) == 0 {
    let _ = p0_in.read().bits(); // One extra read as delay
    bit = (p0_in.read().bits() & PIN_B_MASK) != 0;
}

// Option 2: Invert Phase 2
if !*phase {
    bit = !bit; // Invert the sampled value
}
```

---

### Route 4: PIO/Hardware Assist (Advanced)
**Effort:** High | **Risk:** Medium | **Info Gain:** High

nRF52840 doesn't have PIO like RP2040, but has other options:

**Options:**
1. **GPIOTE + PPI** - Hardware event detection on pin edges
2. **TIMER capture** - Timestamp edges for offline analysis
3. **SPI peripheral** - Abuse SPI to sample at fixed rate

**Why consider:**
- Software bit-banging at 2Mbps is at the edge of what's reliable
- Hardware assist could make timing deterministic

---

### Route 5: Different Controller
**Effort:** Low | **Risk:** Low | **Info Gain:** Medium

Try a different Dreamcast controller to rule out hardware issues.

**What to try:**
- Third-party controller (may have different timing)
- VMU directly (simpler device)
- Loopback test (connect our TX to our RX)

---

## Recommended Order

1. **Route 1 (Scope)** - 15 min to verify assumptions
2. **Route 2 (Bulk Sampling)** - If scope looks good, implement this
3. **Route 3 (Tune)** - Quick tweaks if bulk sampling is overkill
4. **Route 5 (Different Controller)** - If nothing else works

---

## Current Hypothesis

The 500-cycle delay after detecting A going low causes us to miss the first several data bits. The controller starts transmitting data immediately after its start pattern, but we're still waiting.

**Evidence:**
- Frame = 0xFFFFFBF3 (mostly 1s with a few 0s)
- "A went high after 0 cycles" means start pattern already ended during our delay
- At 2Mbps, 500 cycles (~8µs) = ~8 bits missed

---

## Tests Performed

### Test 1: Basic Hardware Verification
**Date:** 2026-02-05
**What:** Flashed blinky_test to verify nRF52840-DK works
**Result:** ✅ LEDs cycle 1-2-3-4 correctly
**Conclusion:** Hardware is functional

### Test 2: Memory Layout Fix
**Date:** 2026-02-05
**What:** Changed memory.x from SoftDevice offset (0x27000) to standalone (0x00000000)
**Result:** ✅ Main app now runs (was not running before)
**Conclusion:** SoftDevice not flashed, must use standalone memory layout

### Test 3: Initial Bus State Reading
**Date:** 2026-02-05
**What:** Read SDCKA/SDCKB as inputs before any communication
**Result:** A=0, B=1 at startup; A=1, B=1 after bus setup
**Conclusion:** Initial A=0 is unexpected (should be HIGH). May be floating/settling issue. After toggling pins, idle state is correct (both HIGH).

### Test 4: Controller Response Detection
**Date:** 2026-02-05
**What:** Send Device Info Request (0x01), monitor for response
**Result:** ✅ "A went low after 64 cycles" - controller IS responding
**Conclusion:** TX works, controller receives our request and responds

### Test 5: Fast Register Access in read_bit_timeout
**Date:** 2026-02-05
**What:** Changed read_bit_timeout to use direct P0->IN register instead of HAL
**Result:** ❌ Hard fault, chip locked up
**Conclusion:** Something wrong with the implementation - reverted

### Test 6: HAL-based reading with 500-cycle delay
**Date:** 2026-02-05
**What:** Using HAL methods for bit reading with 500-cycle delay in wait_for_start
**Result:** Frame = 0xFFFFFBF3 (garbage), timeout reading payload
**Conclusion:** Timing is off - we're missing data bits due to delay

### Test 7: Remove 500-cycle delay
**Date:** 2026-02-05
**What:** Removed delay, immediately wait for A to go HIGH after detecting A LOW
**Result:**
- A went low after 47 cycles (was 64)
- A high after 1 cycles (was 0)
- Frame = 0xFDFDDFFF (different garbage)
- Timeout at bit 2, payload word 18
**Conclusion:** Data changed but still garbage. "A high after 1 cycles" is suspicious - start pattern should keep A low for ~256 cycles (4µs). We may be catching noise or wrong edge.

### Test 8: Measure start pattern (count B transitions)
**Date:** 2026-02-05
**What:** Added B transition counter during start pattern wait
**Result:** A low for 2 cycles, 1 B transition (expected ~256 cycles, 8 transitions)
**Conclusion:** NOT seeing a proper start pattern. Way too short.

### Test 9: Fast register reads in read_bit_timeout + 50µs pre-delay
**Date:** 2026-02-05
**What:**
- Changed read_bit_timeout to use direct P0->IN register reads (PAC VolatileCell)
- Added 3200 cycle (~50µs) delay before looking for response
**Result:**
- **NO CRASH!** Fast register reads work!
- Initial A=1 B=0 (B is LOW - unusual)
- A low for 0 cycles, 0 B transitions
- Frame = 0xDBD83F00, len=0
- Got to CRC check (further than before!)
- CRC mismatch
**Conclusion:** Fast reads work. 50µs delay might be too long - catching middle/end of response. Try shorter delay.

### Test 10: Fast reads with 10µs pre-delay
**Date:** 2026-02-05
**What:** Reduced pre-delay from 50µs to 10µs (640 cycles)
**Result:**
- A went low after 2 cycles
- A low for 1 cycles, 1 B transitions (still too short)
- Frame = 0x00008060
- cmd=0x00, len=96, from=0x80, to=0x00
- Timeout reading payload word 21
**Conclusion:** Frame data changing, getting some valid-looking bytes (0x00, 0x80). Still not seeing proper start pattern though.

### Test 11: Improved start pattern detection with true idle wait
**Date:** 2026-02-05
**What:**
- Wait for true idle (A=1, B=1) before looking for start
- Use direct register reads throughout
- Add warning if <4 B transitions seen
**Result:**
- Initial A=1, B=1 (true idle confirmed)
- A went low after 50 cycles
- Pattern: 3 cycles, 2 B transitions (WARNING)
- Frame = 0x00000000 (all zeros!)
- CRC mismatch
**Conclusion:** Polling loop iterations ≈ 50-100 CPU cycles each. 3 iterations is ~150-300 cycles, close to expected 256 for start pattern. We're detecting it, but reading all zeros suggests timing issue in data read.

### Test 12: With pre-read state debug + 16 cycle delay
**Date:** 2026-02-05
**What:** Added debug showing A/B state right before reading, with 16 cycle delay
**Result:**
- A went low after 52 cycles
- **Ready A=0 B=1** ← A already LOW when we start reading!
- Frame = 0x00000011 ← Got non-zero bits!
- len=17 (vs expected ~28)
- CRC mismatch
**Conclusion:** Progress! The 16 cycle delay caused us to miss the first clock edge - A was already LOW when we checked. Frame has some correct bits but still wrong. Need to remove delay entirely.

### Test 13: Stale probe-rs process discovery
**Date:** 2026-02-05
**What:** Discovered J-Link issues caused by stale probe-rs process (PID 50500 from 10:42AM)
**Result:** ✅ Killing stale process fixed J-Link connection
**Conclusion:** Always check for orphaned probe-rs processes: `ps aux | grep probe-rs`

### Test 14: Remove rprintln between wait_for_start and reading
**Date:** 2026-02-05
**What:** Removed `rprintln!("RX: Got start pattern!")` which cost ~1000+ cycles
**Result:** Frame = 0x03000004, cmd=0x03, to=0x00 (correct!)
**Conclusion:** Debug prints in critical path cause missed bits. to=0x00 is now correct!

### Test 15: Add wait for B=LOW after A=HIGH (100 iteration loop)
**Date:** 2026-02-05
**What:** After detecting A=HIGH, loop waiting for B=LOW
**Result:** Frame = 0x00000081, got to payload word 22 before timeout
**Conclusion:** Extra loop changed timing, different data pattern

### Test 16: Try phase=false
**Date:** 2026-02-05
**What:** Changed initial phase from true to false
**Result:** Frame = 0x01000002, cmd=0x01 (our REQUEST command echoed back?)
**Conclusion:** phase=false gives worse results, stick with phase=true

### Test 17: Remove B=LOW wait, use phase=true
**Date:** 2026-02-05
**What:** Simplified sync - just break when A goes HIGH
**Result:** Frame = 0x03000004 (same as Test 14)
**Conclusion:** Simple sync works best, extra waits don't help

### Test 18: Phase-agnostic edge detection
**Date:** 2026-02-05
**What:** Implemented new read_bit_any_edge() that watches for ANY falling edge
**Result:** Frame = 0xFF30228B, from=0x22 (close to expected 0x20!), got to word 20
**Conclusion:** Different approach gives different (but still wrong) data. Interesting that from field is close.

### Test 19: Phase-based with bit capture
**Date:** 2026-02-05
**What:** Captured individual bits for all 4 bytes of frame word
**Result:**
```
Byte0 bits: 1 0 0 0 0 1 0 0 = 0x84 (expected 0x1C)
Byte1 bits: 0 0 0 0 0 0 0 0 = 0x00 (expected 0x20)
Byte2 bits: 0 0 0 0 0 0 0 0 = 0x00 (expected 0x00) ✓
Byte3 bits: 0 0 0 0 0 0 1 1 = 0x03 (expected 0x05)
```
**Conclusion:** Byte2 is correct (all zeros). Byte0 has leading 1 (possible start pattern tail). Bytes 1-2 are mostly zeros which is suspicious.

### Test 20: Re-read after edge detection
**Date:** 2026-02-05
**What:** Added second register read after detecting clock edge before sampling data
**Result:** Frame = 0xFFFEEFFF (mostly 1s!)
**Conclusion:** The signal is VERY short-lived. Re-reading samples pull-up values. Original single-read approach is correct.

### Test 22: Initial state capture after start pattern
**Date:** 2026-02-05
**What:** Added debug to capture pin state right after wait_for_start returns
**Key Finding:**
- With B=LOW wait loop (100 iterations): Initial state A=0, B=0 → **BAD** (missed first clock edge)
- Without B=LOW wait loop: Initial state A=1, B=0 → **GOOD** (correct state!)
**Conclusion:** The B=LOW wait loop was causing us to miss the first data bit. Removing it puts us in the correct initial state.

### Test 23: Small delay after A goes HIGH
**Date:** 2026-02-05
**What:** Tried adding small delays (compiler_fence, register reads) after detecting A HIGH
**Results:** Mixed - some configurations gave slightly better data (0x14 vs 0x04 for first byte)
**Current state:** Frame = 0x03000004 with cmd=0x03 (expected 0x05)

### Test 24: Bulk Sampling Implementation
**Date:** 2026-02-05
**What:** Implemented "sample everything, decode later" approach inspired by raphnet
- Created `wait_for_start_silent()` with zero prints in critical path
- Bulk sample 4096 GPIO reads into array
- Post-process to find edges and extract bits

**Results:**
```
b_trans=8  ← PERFECT - exactly 4 toggle cycles (8 transitions) in start pattern!
Captured 4096 samples
First 16 samples all A=1, B=0  ← Correct idle state after start pattern
First edge at sample 385 (~6µs after capture start - controller response delay)
Edge spacing: ~14 samples = ~218ns per edge (close to expected 250ns)
Decoded 196 bits (A falls=98, B falls=98)  ← Symmetric as expected
```

**Edge Analysis:**
```
[ 385] A fell, data=0  (first bit)
[ 400] B fell, data=1  (second bit)
[ 416] A fell, data=1
[ 427] B fell, data=1
...
```

**Decoded vs Expected:**
- First byte decoded: 0x74 (01110100)
- First byte expected: 0x1C (00011100)
- 5 of 8 bits match

**Bit Mismatch Analysis:**
- Phase 2 (B falling, sample A) seems to give too many 1s
- Expected 0 at bit 1, got 1
- Expected 0 at bit 2, got 1
- Suggests A line may be slow to transition LOW

**Conclusion:**
- Start pattern detection now PERFECT
- Bulk sampling captures valid alternating Phase1/Phase2 edges
- Bit values don't match expected - possible signal integrity or timing skew
- **Next step: Verify with scope** to see actual waveforms

### Test 25: Pre-edge Sampling (sample 2 before edge)
**Date:** 2026-02-05
**What:** Modified decode_bulk_samples to sample 2 positions BEFORE detected edge
**Results:** Same bit pattern as Test 24
**Conclusion:** Issue is not in sampling timing offset - need scope to see actual signals

---

### Test 21: (Pending) Skip bits experiment results
**Results from earlier:**
- Skip 0 bits: 0x03000084 (Byte0=0x84, Byte3=0x03)
- Skip 1 bit:  0x07000008 (Byte0=0x08, Byte3=0x07) - leading 1 gone!
- Skip 2 bits: 0x0F800010 (Byte0=0x10, Byte3=0x0F) - shifted too far

**Observation:** Skipping 1 bit removes the errant leading 1, suggesting we're catching the last bit of the start pattern.

---

## Key Observations from Recent Tests

### Timing Sensitivity
- Different delays/sync approaches give very different frame values
- Test 14 and 17 both gave 0x03000004 (most consistent)
- cmd=0x03 vs expected cmd=0x05 (differ in bits 0 and 1)
- to=0x00 is now correct in several tests

### Pattern Analysis
| Test | Frame | cmd | Expected |
|---|---|-----|---|
| 14 | 0x03000004 | 0x03 | 0x05 |
| 15 | 0x00000081 | 0x00 | 0x05 |
| 16 | 0x01000002 | 0x01 | 0x05 |
| 17 | 0x03000004 | 0x03 | 0x05 |
| 18 | 0xFF30228B | 0xFF | 0x05 |

### Best Results So Far
- Tests 14 and 17 gave to=0x00 (correct recipient)
- Phase=true with simple sync is most consistent
- Still off by 1-2 bits on command byte

---

## Research from Other Implementations

### From raphnet (Dreamcast USB Adapter)
Source: https://www.raphnet.net/programmation/dreamcast_usb/index_en.php

**Critical Timing Insights:**
- Data is only stable for **~240ns** (not 250ns as documented!)
- At 12 MHz (83ns/cycle), sampling was unreliable - needed **16 MHz** (62.5ns/cycle)
- Controller response times vary: **56µs (official Sega)** to **159µs (third-party)**

**Implementation Approach:**
- Used "memory hungry but fast" method: sample port **640 times** consecutively, then decode
- Assembly: `in r16, PINC; st z+, r16` repeated 640 times
- Process samples offline rather than decode in real-time

**Voltage Issues:**
- 3.3V with pull-ups had issues due to cable capacitance
- Ultimately used direct 5V MCU (out of spec but works)

### From ismell/maplebus (FPGA Implementation)
Source: https://github.com/ismell/maplebus

**Key Findings:**
- Must respond within **1 millisecond** of command
- USB latency (125µs minimum) made software-only solutions problematic
- Eventually moved to FPGA for hardware-level timing control

### From Gmanmodz (PIC32 Implementation)
Source: https://github.com/Gmanmodz/Dreamcast-Controller-Emulator

- Uses PIC32 at higher clock speeds
- C++ implementation with dedicated timing loops

---

## Proposed Test Plans

### Test Plan A: Bulk Sampling Approach
**Hypothesis:** Our polling loop might be too slow or inconsistent. Try the "sample everything, decode later" approach.

1. After start pattern, immediately sample the GPIO register 128+ times in tight loop
2. Store raw samples in array
3. Post-process to find falling edges and extract bits
4. Compare decoded data to expected values

**Pros:** Eliminates timing-dependent logic during critical window
**Cons:** Higher memory usage, more complex post-processing

### Test Plan B: Scope Verification
**Hypothesis:** We may have signal integrity issues or incorrect timing assumptions.

1. Connect scope to SDCKA and SDCKB
2. Send Device Info Request, capture response waveforms
3. Verify:
   - Idle state is both HIGH
   - Start pattern has 4 B toggles
   - Data bit timing (~250ns/phase for controller)
   - Actual response delay from end of TX to start of RX
4. Compare scope timing to our code assumptions

### Test Plan C: Inverted/Swapped Sampling
**Hypothesis:** We may be sampling the correct edge but with inverted logic.

1. Try inverting the sampled bit value in Phase 2 only
2. Try inverting in Phase 1 only
3. Try inverting in both phases
4. Compare results to expected

### Test Plan D: Relaxed Timing (Slower Polling)
**Hypothesis:** Our polling may be catching glitches or partial transitions.

1. Add small delay (1-2 register reads) between detecting edge and sampling
2. Extend timeout to ensure we don't miss slower controllers
3. Compare results

### Test Plan E: Alternative Edge Detection
**Hypothesis:** The "detect any falling edge, sample other pin" approach from protocol doc.

1. Implement truly phase-agnostic reader
2. Track previous state of BOTH pins
3. On ANY falling edge, sample the OTHER pin
4. Don't track phase explicitly

---

## Approaches NOT Yet Tried

1. ~~Remove the 500-cycle delay~~ ✓ Done
2. ~~Count B transitions~~ ✓ Done (saw 1-3 transitions)
3. ~~Add debug for first few bits~~ ✓ Done - captured bit arrays
4. ~~Try phase=false~~ ✓ Tried, worse results
5. ~~Fast register access~~ ✓ Working
6. **Bulk sampling approach** - sample 100+ times, decode later
7. **Scope verification** - verify actual waveforms
8. **Inverted sampling** - try inverting bit values
9. **Phase-agnostic detection** - any falling edge triggers sample

---

## Key Observations

### Controller Responds
- A goes low after 64 cycles (~1µs) = controller detected our request
- This confirms: TX encoding works, wiring is correct enough for TX

### Timing Mismatch
- Our delay: 500 cycles = ~8µs
- Start pattern duration: ~4µs (4 toggles at 2Mbps)
- First data bits sent: immediately after start pattern
- We're ~4µs late to start reading

### Data Pattern
- 0xFFFFFBF3 = mostly 1s (pullups)
- Some 0 bits present (F3 = 11110011, FB = 11111011)
- Suggests we ARE catching some edges, just out of sync

### Initial A=0 Mystery
- At very first read (before any setup): A=0, B=1
- After toggling pins and setting up bus: A=1, B=1 (correct)
- Possible causes: floating input, controller not powered yet, settling time

---

## Tooling / Debug Environment Notes

### J-Link Connection Issues

**Symptom:** "Probe not found" or "Out of sync, resynchronizing" errors even though J-Link is connected.

**Common causes:**
1. **Stale probe-rs process** - Previous flash/debug session didn't terminate cleanly
2. **JLinkGUIServerExe** - SEGGER's GUI server may be holding the connection
3. **nrfutil-device** - VS Code nRF Connect extension holds J-Link connection

**IMPORTANT: Always check before erasing or flashing:**
```bash
# Check for blocking processes (run this FIRST!)
ps aux | grep -iE 'jlink|probe-rs|openocd|nrf' | grep -v grep

# Common offenders:
# - nrfutil-device (from VS Code nRF Connect extension)
# - probe-rs (from previous session)
# - JLinkGUIServerExe

# Kill blocking process (replace PID)
kill <pid>

# Then proceed with erase/flash
probe-rs erase --chip nRF52840_xxAA --allow-erase-all
```

**Prevention:** Always ensure probe-rs commands complete or are properly terminated. If a flash hangs, Ctrl+C may not fully release the J-Link - check for orphaned processes.

### DK Chip Lock / Hard Fault Recovery

If the DK locks up (hard fault, infinite loop), the debugger may fail to connect. Fix:
```bash
probe-rs erase --chip nRF52840_xxAA --allow-erase-all
```

For XIAO recovery, see `docs/xiao_debug_log.md`.

---

## Hardware Notes

### nRF52840-DK Pin Mapping
- P0.05 → SDCKA (directly on P2 header)
- P0.06 → SDCKB (directly on P2 header)
- P0.11 → Button 1 (active low)
- P0.13-16 → LEDs 1-4 (active low)

### Dreamcast Controller Connector
- Pin 1 (Red): SDCKA
- Pin 2 (Blue): +5V
- Pin 3 (Green): GND/Sense - MUST be grounded for controller to respond
- Pin 4 (Black): GND
- Pin 5 (White): SDCKB

---

## Code State

### Files Modified
- `src/maple/gpio_bus.rs` - Main bit-banging implementation
- `src/maple/host.rs` - Host controller logic
- `src/main.rs` - Test harness
- `memory.x` - Changed to standalone mode

### Current wait_for_start Logic
```rust
1. Wait for A=HIGH (bus idle)
2. Wait for A=LOW (start pattern begins) - takes ~64 cycles
3. delay(500) ← PROBLEM: too long
4. Wait for A=HIGH (start pattern ends) - already HIGH (0 cycles)
5. delay_half_bit() x2 ← more delays
6. Return, start reading with phase=true
```

### Proposed Fix
```rust
1. Wait for A=HIGH (bus idle)
2. Wait for A=LOW (start pattern begins)
3. Wait for A=HIGH (start pattern ends) - NO artificial delay
4. Immediately return, ready to read
```

---

## Next Steps

1. Remove the 500-cycle delay
2. Add debug showing first few bit reads (pin states, timing)
3. Verify we catch the first clock edge (A going LOW for first data bit)

---

## Session: 2026-02-09 (Triple-Press Name Toggle)

### Feature
Added ability to toggle device name between "Xbox Wireless Controller" and "Dreamcast Wireless Controller" via triple-press of the sync button (Button 4).

### Why
The iBlueControlMod adapter identifies controllers by BLE name ("Xbox Wireless Controller"), so that must remain the default. However, for general BLE use (Mac, iPhone, PC), "Dreamcast Wireless Controller" is more descriptive. Users can triple-press to switch.

### Implementation
- **Flash storage** (`src/ble/flash_bond.rs`): New flash page at `0x000FD000` stores name preference with magic `0x4E414D45` ("NAME"). Default = Xbox (0x00).
- **SoftDevice name** (`src/ble/softdevice.rs`): `init_softdevice(is_dreamcast: bool)` picks the name at boot. Two static scan data arrays for advertising.
- **Triple-press** (`src/main.rs`): 3 presses within 2 seconds (without triggering the 3s hold-for-sync) toggles the preference. Signals `ble_task` to write flash, then `SCB::sys_reset()`.
- LED gives 5 rapid blinks to confirm the toggle before reset.

### Expected Behavior
1. Boot → loads preference → advertises with chosen name
2. Triple-press sync button → 5 rapid blinks → device resets → advertises with other name
3. Preference persists across power cycles
4. 3-second hold for sync mode still works unchanged

---

## 2026-02-09: Clean up all clippy pedantic warnings and dead code

### What Changed
Comprehensive cleanup to achieve zero warnings under `cargo clippy -- -W clippy::all -W clippy::pedantic`.

### Deleted
- **`src/board/mod.rs`** — entire module removed (unused `LedState`, `BoardConfig`, `Nrf52840Dk`, pin constants). Removed `mod board` from `main.rs` and `lib.rs`.
- **`src/maple/packet.rs`** — deleted unused `encode()`, `decode()`, `crc()`, `crc8_word()`, `Default` impl.
- **`src/maple/host.rs`** — deleted unused `commands::NO_RESPONSE`, `functions::{MEMORY_CARD, LCD, TIMER, VIBRATION}`, `MapleHost::with_timeout()`, `MapleResult::CrcError`.
- **`src/maple/gpio_bus.rs`** — deleted unused `MapleBusGpioOut` type alias.

### Fixed across all files
- Hex literal separators: `0x000FE000` → `0x000F_E000`, `0x00000001` → `0x0000_0001`, etc.
- Cast warnings: `as u8/u16/u32` → `u8::from()`, `u16::from()`, `u32::from_le_bytes()`, `.to_le_bytes()`
- `&x as *const T` → `&raw const x` / `.cast_mut()` for pointer casts
- `#[inline(always)]` → `#[inline]` on all gpio_bus functions
- `map().unwrap_or()` → `map_or()`, `.is_some_and()` in security.rs
- `to_*` methods on Copy types: `&self` → `self`
- Doc backtick warnings: bare identifiers in doc comments wrapped in backticks
- `let...else` and `if let` patterns replacing match-on-single-pattern
- Removed redundant `continue` and `else` blocks
- Added `#[must_use]` on all pure public functions
- Module-level `#[allow]` for unavoidable macro-generated warnings (nrf-softdevice gatt macros)

### Verification
- `cargo clippy -- -W clippy::all -W clippy::pedantic` — 0 warnings
- `cargo build` — success
- `cargo fmt` — clean

---

## 2026-02-09: Connection Hardening

Added reliability features to make the adapter suitable for real gaming sessions.

### Changes Implemented (5 of 6)

**1. Stale Controller Detection**
- Track consecutive `get_condition` failures in main loop
- After 30 failures (~500ms), send neutral/centered report to zero out all inputs
- Logs "Controller lost" and "Controller reconnected" transitions

**2. BLE Notification Error Handling**
- Track consecutive `send_report` failures (was silently discarded with `let _`)
- After 10 consecutive failures, break out of notify loop to trigger disconnect handling
- Prevents zombie connection state where we keep sending to a dead link

**3. Disconnect Reason Logging**
- `Connection` has no `disconnect_reason()` method — used `gatt_server::run` result instead
- Now logs which future completed (GATT error vs notify failure) with the error value
- Example: "BLE: Disconnected (GATT: Err(Disconnected))"

**4. Fast Reconnect Advertising**
- Added `ReconnectFast` mode: 20ms interval (same as SyncMode) but NOT discoverable
- Used for first 5 seconds after disconnect for snappy reconnection
- After 5s, falls back to `Reconnect` mode (100ms interval) to save power

**5. Connection Parameter Update Logging**
- `sd_ble_gap_conn_param_update` return code now checked and logged on failure
- Previously fire-and-forget with `let _`

### Controller Detection Retry Loop
- Previous code: single `request_device_info` attempt, then block forever in `wfi()` loop
- New code: retries with exponential backoff (100ms → 200ms → ... → 1s cap)
- LED4 on while searching, LED3 on when found
- Uses async `Timer::after` so executor keeps running (BLE task, sync button stay responsive)
- Removed the old blocking `wfi()` reset-button loop entirely

### WDT: Deferred (Not Implemented)

Attempted hardware WDT via raw register writes (base `0x4001_0000`). Removed after
repeated reset loops during debugging. Key learnings:

- **nRF52840 WDT cannot be stopped once started.** It survives system resets (only
  cleared by full power-on reset or pin reset).
- **CONFIG register is write-once.** Once TASKS_START fires, CONFIG/CRV/RREN are locked.
  If a previous firmware started the WDT with bad config (e.g., `HALT=Run`), reflashing
  new firmware with `HALT=Pause` has no effect — the old config persists.
- **`HALT=Run` + debugger = reset loop.** cargo-embed halts the CPU during flash/attach.
  With HALT=Run, the WDT keeps counting during halt and fires before firmware reaches
  the feed instruction. This creates an unrecoverable reset loop that requires a full
  power cycle (USB unplug/replug) to escape.
- **`HALT=Pause` doesn't help** if a previous boot already locked CONFIG with HALT=Run.
- **Conclusion:** WDT is a production-only feature. It must be the LAST thing added,
  and the firmware should feed the WDT as the absolute first instruction (before
  `rtt_init_print`, before Embassy init) to handle the case where a WDT from a previous
  boot is still running. Consider gating WDT behind a compile-time feature flag
  (`#[cfg(feature = "wdt")]`) so development builds never enable it.

### Files Modified
- `src/main.rs` — stale detection, notify errors, disconnect logging, conn param logging,
  ReconnectFast usage, controller detection retry loop
- `src/ble/softdevice.rs` — `ReconnectFast` advertising mode variant + match arm

### Verification
- `cargo build` — success
- `cargo clippy -- -W clippy::all -W clippy::pedantic` — 0 warnings
- Hardware tested: controller detection retry loop works
- Still needed: unplug controller mid-session, BLE disconnect/reconnect, sustained gameplay

---

## Session: 2026-02-19 (dc-protocol extraction, tests, docs)

### What Changed
Extracted pure protocol logic into a separate `dc-protocol/` library crate so it can be tested on the host without embedded toolchains.

### dc-protocol Crate
- New workspace member: `dc-protocol/` (no_std, depends only on `heapless`)
- Moved from main crate:
  - `controller_state.rs` — `ControllerState`, `ButtonState`, `from_payload`, `to_gamepad_report`
  - `hid.rs` — `GamepadReport`, `to_bytes`, `hat` module, `buttons` module
  - `packet.rs` — `MaplePacket`, `frame_word`
- `state_changed()` moved from free function in `main.rs` to method on `ControllerState`
- Main crate files now re-export from `dc_protocol::*`

### Tests (24 total, all passing)
- **controller_state** (17): button parsing, roundtrip, from_payload (valid/short/wrong func),
  stick deadzone, gamepad report (buttons/dpad/triggers/sticks), state_changed (buttons/triggers/sticks)
- **hid** (5): to_bytes default/buttons/triggers/hat/max values
- **packet** (2): frame_word basic/with payload

### Fixed
- `controller_state_parse` test had wrong assertions (raw byte values vs inverted values).
  The test was ported from the original crate where it had never actually run due to the
  `cortex-m` dependency preventing `cargo test` on host.

### Docs
- `README.md` — full rewrite: features, hardware, build/flash, testing, project structure
- `docs/users_guide.md` — non-technical guide: pairing, button mapping, sync button, battery, sleep, troubleshooting

### Verification
- `cd dc-protocol && cargo test` — 24 tests pass
- `cargo build --release --no-default-features --features board-xiao` — success
- `cargo build --release --no-default-features --features board-dk` — success

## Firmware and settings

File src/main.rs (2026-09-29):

// SPDX-License-Identifier: GPL-3.0-or-later
// Copyright 2025-2026 alwaysEpic

#![no_std]
#![no_main]

use embassy_executor::Spawner;
use embassy_time::{Duration, Timer};
use pulsar_dreamcast_ble::ble::{get_connection_state, ConnectionState};
use pulsar_dreamcast_ble::maple::host::MapleResult;
#[cfg(feature = "spim-capture")]
use pulsar_dreamcast_ble::maple::spim_capture::SpimCapture;
use pulsar_dreamcast_ble::maple::{ControllerState, MapleBus, MapleHost};
use pulsar_dreamcast_ble::{ble, board, RAW_CONTROLLER_STATE};

use embassy_time::Instant;
use nrf_softdevice::Softdevice;
// Panic handler is registered via #[panic_handler] in pulsar_dreamcast_ble::panic_handler
use pulsar_dreamcast_ble::SLEEP_TIMEOUT_MS;
use pulsar_dreamcast_ble::{log, log_init};
use static_cell::StaticCell;

use pulsar_dreamcast_ble::BATTERY_LEVEL;

/// Poll-loop pacing. Current design (read the whole story below — it was
/// earned the hard way): a minimum spacing sleep, then every Maple
/// transaction starts at the head of a radio-quiet window
/// (`align_to_quiet_window`), which locks one poll to each BLE connection
/// event. The sections below document, in order, the three designs and the
/// field data that killed the first two.
///
/// # Why absolute, not relative (the layout lottery, strike three)
///
/// The previous design slept a relative 5ms at the bottom of the loop, so the
/// period was `body + 5ms` and everything that moved the body moved the
/// period — and, worse, moved the *phase* of every subsequent poll against
/// the connection-event clock. `get_condition` retries cost ~4-5ms each and
/// happen exactly when the Maple TX+capture window collides with radio
/// activity, so body time fed back into collision probability: a coupled
/// oscillator. Rebuilds of identical source shifted the base body by
/// microseconds and rolled the system between a fast-sweeping phase (1-4%
/// doubled conn intervals) and a dwelling one (up to 30%) — the 2026-08
/// post-OTA "regression" that took a day of exact-binary A/B to pin (see
/// the 2026-08-05 board bring-up measurements; the good and bad
/// binaries are instruction-identical in the whole RX/decode path, icache
/// off — the difference was never the code, it was the timing map).
///
/// Anchoring cuts the feedback wire: a retry-lengthened iteration eats its
/// own slack instead of shifting every later poll, and layout variance in
/// the body disappears into the sleep as long as the body fits the budget.
/// A body that does NOT fit is counted in `POLL_OVERRUNS` (readable via the
/// `poll-period-debug` HID channel, tag 0xB5) — a bad roll now flags itself
/// on-device in seconds instead of needing a day of captures.
///
/// # Why 13
///
/// - Healthy body is ~8.5ms (TX ~0.4 + capture ~3.1 + decode + VMU/misc),
///   leaving ~4.5ms of slack for retries and layout rolls.
/// - The blessed v209 layout measured a ~13.4ms emergent period across every
///   validated capture — 13 preserves the proven dynamics as a designed
///   constant instead of an accident.
/// - 13 < 15 strictly: the maximum age of the freshest sample at any
///   connection event is 13ms, so no event goes empty during motion. The
///   13:15 beat sweeps the full phase every ~7.5 polls — no dwell, no lock.
/// - (Pre-existing caveat, unchanged from the old design: a central that
///   grants the requested 11.25ms interval out-runs this period. The bench
///   host runs 15ms; revisit if a sub-13ms-interval host ever matters.)
///
/// # Why the anchor alone was not enough (field data, 2026-08-05 runs #40-43)
///
/// The fixed 13ms deadline cut the feedback only while the body fit the
/// budget. Measured on hardware: one collision retry costs ~5-7ms on top of
/// a ~4.5-6ms base body, so a colliding poll overruns any budget that fits
/// under the 15ms interval, and the overrun resync re-couples body time to
/// phase — v214's roll ran gc mean 17.5ms, 1.33 retries/poll, ~37
/// overruns/s, 27% doubled intervals *with the anchor active*. Anchored
/// rolls that mostly fit (v211) held 6-9.6%: better, still out of band.
///
/// # The actual fix: start polls where the radio isn't
///
/// The SoftDevice tells us when radio activity begins and ends
/// (`maple::radio_notify`, 800µs advance warning). The pacer below sleeps a
/// minimum spacing, then waits for a **fresh radio-INACTIVE edge** before
/// letting the next Maple transaction start — so the ~3.5ms TX+capture
/// window opens at the head of the ~12ms inter-event quiet gap with ~7ms of
/// margin, and collisions (hence retries, hence the entire phase-feedback
/// mechanism) are structurally absent instead of absorbed. The cadence
/// locks to one poll per connection event (~15ms → the 66.6Hz / IQR 0.9ms
/// blessed profile), and layout-independence is total: no plausible codegen
/// roll spans a 7ms margin.
///
/// # History: the 2026-07-24 knife-edge
///
/// The old relative delay was 5 and not 8 because at 8 the emergent period
/// sat at ~15ms — exactly the interval — and sub-millisecond codegen noise
/// decided which side of the line each build landed on (53.1Hz/IQR 14.6 vs
/// 66.9Hz/IQR 1.2 from identical code). That was this same coupled-oscillator
/// failure observed through a smaller window.
///
/// **Do not change these without a hardware capture.** Healthy is ~66.6Hz /
/// median 15.0ms / IQR ~0.9ms / (mean−median)/median within 1.3-4.0%.
/// Nothing in `ci.sh` detects the difference.
///
/// Nominal poll period (event-locked to the connection interval); used to
/// convert poll counts to durations (VMU splash/home holds, detect delay).
const POLL_PERIOD_MS: u64 = 15;

/// Minimum spacing between poll starts. Also the whole pacer when radio
/// notifications are unavailable (`idle_age_ms() == None`) — that fallback
/// is exactly the validated fixed-anchor regime.
const MIN_POLL_SPACING_MS: u64 = 13;

/// Hard cap on waiting for a quiet-window edge: a missing or late INACTIVE
/// notification can slow one iteration to this, never stall the loop.
const POLL_FALLBACK_MS: u64 = 20;

/// A radio-INACTIVE edge no older than this marks the head of a quiet
/// window — the only place a Maple transaction is allowed to start when
/// notifications are live. 2ms spent, ~4.5ms gc, ~1.7ms VMU DMA still end
/// ~4ms before the next connection event.
const QUIET_FRESH_MS: u32 = 2;

/// Re-check cadence while waiting for a quiet-window edge.
const ALIGN_POLL_US: u64 = 500;

/// Cap on the pacer's edge wait (the slice of `POLL_FALLBACK_MS` left after
/// the minimum spacing).
const POLL_ALIGN_CAP_MS: u64 = POLL_FALLBACK_MS - MIN_POLL_SPACING_MS;

/// Cap on a mid-iteration edge wait (VMU probe/enumerate). Slightly over
/// one connection interval, so a live notification source always delivers
/// an edge inside it.
const EXTRA_ALIGN_CAP_MS: u64 = 18;

/// Wait until the head of a radio-quiet window — a fresh INACTIVE edge — or
/// `cap_ms` from now, whichever comes first. `None` (no notification
/// source) returns immediately: fixed-cadence fallback. Returns the time
/// actually spent waiting so callers can keep it out of body-time budgets.
///
/// Every Maple transaction is supposed to start through this. The v216
/// soak showed why mid-iteration transactions need it too: a VMU-probe
/// iteration ran `get_condition` + `sub_peripheral_mask` + `enumerate_vmu`
/// back-to-back (~20ms of bus time against a ~12ms quiet window), so the
/// tail transactions collided every time and four collided probes in a row
/// (12s) flipped VMU presence — the "brief VMU disconnect" during the soak.
async fn align_to_quiet_window(cap_ms: u64) -> Duration {
    let start = Instant::now();
    let deadline = start + Duration::from_millis(cap_ms);
    loop {
        match pulsar_dreamcast_ble::maple::radio_notify::idle_age_ms() {
            Some(age) if age <= QUIET_FRESH_MS => break,
            None => break,
            Some(_) => {
                if Instant::now() >= deadline {
                    break;
                }
                Timer::after(Duration::from_micros(ALIGN_POLL_US)).await;
            }
        }
    }
    start.elapsed()
}

/// Body-time budget for the on-device overrun detector (`POLL_OVERRUNS`).
/// Measured on v216 (run #44): collision-free gc is 6.6-7.2ms (decode is
/// the wide part), and a VMU-animation poll adds a ~1.7ms DMA write — so
/// honest bodies peak ~9ms (the first 9ms budget counted exactly those VMU
/// polls, ~4/s). 11 clears the honest peak while still catching a single
/// collision retry (+5-7ms), which is what this detector exists to see.
const BODY_BUDGET_MS: u64 = 11;

/// Consecutive poll failures before declaring controller lost.
const CONTROLLER_LOST_THRESHOLD: u16 = 30;

/// a scheduled VMU block read may take one window in this many.
///
/// **A ceiling, not the rate.** The v258 sweep measured the decoder, not the
/// ratio, as the pacer: ~25 ms per block spans several windows' slack, so the
/// real cadence came out at one read per 7-10 windows for every N from 2 to 5.
/// What N does buy is a floor under controller freshness when a decode happens
/// to be quick, and 5 is the least costly of the ratios the sweep measured
/// (doubled-interval skew 8.7 % against 15.8 % at N = 2).
///
/// **Chosen 2026-09-22: 5** — the sweep put none of N = 2-5
/// inside the HID band, so this is the conservative end of the measured range,
/// and it is the value the write path was benched at, so later write
/// runs stay comparable. Writes pace on it too: a block is five slots plus its
/// read-back, ≈ 0.6 s, ≈ 12 s for a 20-block save. Revisit only with the HID
/// gate run under a drain beside the change.
#[cfg(feature = "spim-capture")]
const READ_EVERY_N: u8 = 5;

/// decode slices run in the iteration's slack until this far past
/// its start, and none is begun within [`SLICE_GUARD_US`] of it.
///
/// Continuity with the tested configuration, as `READ_LCD_GAP_TICKS` is: 14 ms
/// with 1,024-sample slices is what the v263-v299 pulls were measured under
/// (185 blocks in 18.2-18.5 s). It deliberately exceeds `MIN_POLL_SPACING_MS`,
/// so a window that is still decoding reaches the pacer with its spacing timer
/// already expired and starts the next window at the next quiet edge instead.
/// The slices run *after* the body-budget check, so a decode is never counted
/// as a poll overrun — it is slack work, not body work.
#[cfg(feature = "spim-capture")]
const DECODE_UNTIL_MS: u64 = 14;

/// A decode slice is not begun within this of [`DECODE_UNTIL_MS`].
#[cfg(feature = "spim-capture")]
const SLICE_GUARD_US: u64 = 500;

/// Initial retry delay for controller detection (ms).
const INITIAL_RETRY_DELAY_MS: u64 = 100;

/// Maximum retry delay for controller detection (ms).
const MAX_RETRY_DELAY_MS: u64 = 1000;

/// How often to check BLE connection state while waiting (ms).
const BLE_WAIT_CHECK_MS: u64 = 100;

/// How long the 5 V rail stays up after a link drops.
///
/// ADR-005 drops the rail at every disconnect, which on pulsarv1 power-cycles
/// the controller, VMU and rumble pack. At the edge of range a link drops and
/// comes back within ~0.05–3 s (bench, 2026-09-24), so each blip also cost
/// a controller reset and a re-detect. Ten seconds is one `ReconnectFast`
/// burst: if the unit's own fast reconnect hasn't landed by then, the host
/// isn't coming back soon and the rail goes down as ADR-005 intends.
const RAIL_GRACE: Duration = Duration::from_secs(10);

/// Why the 5 V rail is still up in Phase 1, where ADR-005 otherwise has it down.
#[derive(Clone, Copy, PartialEq, Eq)]
enum RailHold {
    /// Down, as ADR-005 has it.
    Released,
    /// Sync mode with a controller on the port: the SYNC splash on the VMU is
    /// the pairing indicator and only stays lit while the rail does. Held
    /// until the sync window ends without a connect. Taken from Phase 3, where
    /// the controller is known, or from Phase 1 once the controller has
    /// answered during the splash — never for an empty port, where the no-bond
    /// auto-entry would run the boost into nothing for the whole ≤60 s window.
    Sync,
    /// A link just dropped: held until this instant so a reconnect inside
    /// [`RAIL_GRACE`] doesn't power-cycle the controller.
    Grace(Instant),
}

impl RailHold {
    /// A hold after a link drop, timed from the drop itself.
    ///
    /// From the drop, not from leaving the poll loop: when acked VMU saves are
    /// draining, the loop stays up to `LINK_LOSS_DRAIN_DEADLINE_MS` after the
    /// drop, and by then the `ReconnectFast` burst the grace is
    /// sized to has long ended. A grace that has already run out drops the
    /// rail on Phase 1's first pass.
    fn after_drop(dropped_at: Instant) -> Self {
        Self::Grace(dropped_at + RAIL_GRACE)
    }

    /// Whether Phase 1 should drop the rail now. A connect never gets here:
    /// Phase 2 takes the rail over and releases the hold.
    fn is_over(self, conn_state: ConnectionState, now: Instant) -> bool {
        match self {
            Self::Released => false,
            Self::Sync => conn_state != ConnectionState::SyncMode,
            Self::Grace(until) => now >= until,
        }
    }
}

/// Timeout for initial controller detection (ms).
/// Enter System Off if no controller found within 60 seconds of BLE connecting.
const DETECT_TIMEOUT_MS: u64 = 60_000;

/// Timeout before entering sleep when controller is idle (ms).
/// 10 minutes with no input change triggers System Off.
const INACTIVITY_TIMEOUT_MS: u64 = 600_000;
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
async fn main(spawner: Spawner) {
    static GAMEPAD_SERVER: StaticCell<ble::GamepadServer> = StaticCell::new();
    static CONFIG_SERVER: StaticCell<ble::ConfigServer> = StaticCell::new();
    static BONDER: StaticCell<ble::Bonder> = StaticCell::new();

    log_init!();
    pulsar_dreamcast_ble::panic_handler::check_panic_log();
    log!("DC Adapter Starting");

    // Initialize Embassy with interrupt priorities that don't conflict with SoftDevice
    let mut config = embassy_nrf::config::Config::default();
    config.gpiote_interrupt_priority = embassy_nrf::interrupt::Priority::P2;
    config.time_interrupt_priority = embassy_nrf::interrupt::Priority::P2;

    // Owner access to the debug port is a deliberate product decision (ADR-015),
    // so state it rather than inheriting a library default that a future Embassy
    // upgrade could change underneath us. On build code F and later the nRF52840
    // locks the access port at reset unless firmware says otherwise: this makes
    // `init` write UICR.APPROTECT = HwDisabled and APPROTECT.DISABLE, resetting
    // once if the UICR word actually changed.
    //
    // This is a backstop, not the mechanism. Factory programming provisions the
    // same UICR word after the final chip erase, because a unit that never
    // reaches this line — bricked or unprogrammed — would otherwise be locked
    // with only a destructive `--recover` to open it, taking the panic log and
    // bonds with it.
    config.debug = embassy_nrf::config::Debug::Allowed;

    board::configure_embassy(&mut config);
    let p = embassy_nrf::init(config);

    // Embassy init may perform one APPROTECT-provisioning software reset, so
    // consume the retained one-boot marker only after it returns. This is still
    // before any SoftDevice enable, address selection, GATT registration, or
    // bond access.
    let config_mode = pulsar_dreamcast_ble::take_config_boot_marker();

    // Silicon housekeeping: clear bootloader pin residue, then park the onboard
    // QSPI flash in Deep Power Down (no-op on boards that need neither).
    // SAFETY: `board::early_init` must run before any Embassy pin peripheral is
    // configured. `embassy_nrf::init` above only hands back the `Peripherals`
    // struct; no pin has been claimed from `p` yet, so the contract holds.
    unsafe {
        board::early_init();
    }

    // Load durable prefs (active profile + remap) from the journal;
    // defaults to Xbox / RemapTable::DEFAULT on first boot.
    let prefs = ble::prefs::load_prefs();
    let profile_id = prefs.profile_id;
    let profile = profile_id.profile();
    log!(
        "PROFILE: {} (PID {:#06x})",
        core::str::from_utf8(profile.vmu_label).unwrap_or("?"),
        profile.pid
    );

    // Initialize exactly one SoftDevice personality. The GAP name is fixed at
    // enable time, so this decision must precede GATT server registration.
    ble::softdevice::set_profile(profile);
    let sd = if config_mode {
        log!("BOOT: isolated configuration personality");
        let sd = ble::softdevice::init_config_softdevice();
        ble::config::activate_config_address(sd);
        sd
    } else {
        ble::softdevice::init_softdevice(profile)
    };

    // Power-fail canary for the VMU-write SD-assert investigation: the VMU
    // draws its dock power from the shared 5V rail and its LCD/buzzer
    // activity may dip the supply during writes (debug log 2026-06-11). The
    // power-fail comparator fires a SOC event (logged in softdevice_task)
    // when VDD drops below 2.5V — any POFWARN correlated with a VMU write
    // is direct evidence for the rail-dip theory.
    #[expect(
        clippy::multiple_unsafe_ops_per_block,
        reason = "threshold-then-enable is one power-fail-comparator configuration; \
                  enabling before the threshold is set would arm it at the reset default"
    )]
    // SAFETY: both are SoftDevice SVC calls taking small integer arguments by
    // value and dereferencing nothing. The SoftDevice is enabled by this point,
    // which is their only precondition, and both return codes are discarded
    // deliberately — power-fail warning is diagnostic, so a refusal is not
    // fatal to boot.
    unsafe {
        use nrf_softdevice_s140 as sd_raw;
        #[expect(
            clippy::cast_possible_truncation,
            reason = "SoftDevice power-threshold constants are small enum discriminants that fit u8"
        )]
        let _ = sd_raw::sd_power_pof_threshold_set(
            sd_raw::NRF_POWER_THRESHOLDS_NRF_POWER_THRESHOLD_V25 as u8,
        );
        let _ = sd_raw::sd_power_pof_enable(1);
    }

    // Radio notifications: RE-ENABLED 2026-08-05 to gate the poll loop's
    // Maple transactions into radio-quiet windows (see POLL_PERIOD_MS docs —
    // field data proved collisions, not codegen, drive the layout lottery).
    //
    // History: the 2026-06-10 "every gate built on these asserted" verdict
    // (see maple/radio_notify.rs) has a known confound discovered a day
    // later: those diagnostic builds carried poll_timing's critical-section
    // bug, whose SD asserts were triggered by the VMU-write measurement path
    // — which only ran when writes were active, exactly matching the
    // "writes-on asserts, writes-off clean" evidence. The notification
    // config itself (INT_ON_BOTH) ran hours clean elsewhere. Not proven
    // innocent: the re-enable is gated on a soak test (historical assert
    // rate was ~1-2/min, so a 30-60 min clean soak is decisive).
    if pulsar_dreamcast_ble::maple::radio_notify::init() {
        log!("RADIO: notification gate enabled (INT_ON_BOTH, 800us)");
    } else {
        log!("RADIO: notification cfg REJECTED — poll pacer in fixed-cadence fallback");
    }

    // Register exactly one runtime GATT database. The config branch never
    // constructs a Bonder, takes a flash handle, restores system attributes,
    // or calls the normal HID connection handler.
    if config_mode {
        let Ok(server) = ble::ConfigServer::new(sd) else {
            loop {
                cortex_m::asm::wfi();
            }
        };
        let server = CONFIG_SERVER.init(server);
        let _ = server.init(&prefs);

        if let Ok(token) = softdevice_task(sd) {
            spawner.spawn(token);
        }
        if let Ok(token) = ble::config::config_task(sd, server, prefs) {
            spawner.spawn(token);
        }
    } else {
        let Ok(server) = ble::GamepadServer::new(sd) else {
            loop {
                cortex_m::asm::wfi();
            }
        };
        let server = GAMEPAD_SERVER.init(server);
        let _ = server.init(profile);

        if let Ok(token) = softdevice_task(sd) {
            spawner.spawn(token);
        }

        let bonder = BONDER.init(ble::Bonder::new());
        if let Some((master_id, enc_info, peer_id, sys_attrs)) = ble::flash_bond::load_bond() {
            bonder.load_from_flash(master_id, enc_info, peer_id, sys_attrs);
        }
        if let Ok(token) = ble::task::ble_task(sd, server, bonder, prefs.remap) {
            spawner.spawn(token);
        }
    }

    // Initialize board-specific pins and peripherals (the board grabs whatever
    // pins/peripherals it needs from `p`; main never names an individual pin).
    let board::BoardPins {
        sdcka,
        sdckb,
        sync_button,
        sync_led,
        mut status,
        mut power,
        mut rumble,
        // The RX capture backend on the boards that have one (
        // route (a)); the parts are not even taken without the feature (see
        // `board`), because taking and dropping them for no consumer rolled
        // the poll loop (v278).
        #[cfg(feature = "spim-capture")]
        spim_capture,
    } = board::init(p);

    if !config_mode {
        if let Ok(token) = pulsar_dreamcast_ble::button::sync_button_task(sync_button, sync_led) {
            spawner.spawn(token);
        }
    }
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

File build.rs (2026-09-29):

// Build script: generates pixel-art glyphs for the VMU profile splash by
// rasterizing parametric paths. Output is included by src/vmu.rs.
//
// We compute these at build time rather than encoding bytes by hand because
// hand-encoding a smooth Archimedean spiral at 32×24 doesn't converge — every
// attempt looks like concentric rings rather than a continuous ribbon.

use std::env;
use std::error::Error;
use std::f64::consts::PI;
use std::fmt::Write as _;
use std::fs;
use std::path::Path;

const WIDTH: usize = 32;
const HEIGHT: usize = 24;
const BYTES: usize = WIDTH * HEIGHT / 8;

// Returns `Result` rather than unwrapping: the workspace forbids
// `unwrap`/`expect`/`panic` outright, and a build script gets the same
// treatment as firmware. Cargo prints the error and fails the build, so the
// diagnostics are no worse than a panic's — and the failure paths are explicit.
fn main() -> Result<(), Box<dyn Error>> {
    println!("cargo:rerun-if-changed=build.rs");
    // memory.x is a linker input, not a rustc one, so without this line an edit
    // to it never relinks: cargo re-uplifts the cached ELF and ci.sh checks a
    // binary built from the previous script (2026-09-15 — the
    // .maple_text section was absent from one of five "fresh" builds).
    println!("cargo:rerun-if-changed=memory.x");

    let out_dir = env::var("OUT_DIR")?;
    let out_path = Path::new(&out_dir).join("glyph_dreamcast.rs");

    let bytes = generate_swirl();

    let mut content = String::new();
    content.push_str("// Generated by build.rs — do not edit.\n");
    content.push_str("/// Dreamcast swirl glyph (Generic profile), rasterized from a parametric\n");
    content.push_str("/// Archimedean spiral. 1.75 turns ending at upper-right, mirrored\n");
    content.push_str("/// vertically so the outer terminus lands at the lower-right.\n");
    content.push_str("#[rustfmt::skip]\n");
    writeln!(content, "pub const GLYPH_DREAMCAST: [u8; {BYTES}] = [")?;
    for row in 0..HEIGHT {
        content.push_str("    ");
        for col_byte in 0..(WIDTH / 8) {
            let b = bytes[row * (WIDTH / 8) + col_byte];
            write!(content, "0x{b:02X}, ")?;
        }
        // Visualise as a comment for inspectability in the generated file.
        content.push_str("// ");
        for col in 0..WIDTH {
            let b = bytes[row * (WIDTH / 8) + col / 8];
            let bit = (b >> (7 - (col % 8))) & 1;
            content.push(if bit == 1 { 'X' } else { '.' });
        }
        content.push('\n');
    }
    content.push_str("];\n");

    fs::write(&out_path, content)?;
    Ok(())
}

/// Plot a 3-pixel-wide ribbon along an Archimedean spiral, plus a tail that
/// extends from the spiral's outer terminus outward to the upper-right.
#[expect(
    clippy::cast_precision_loss,
    reason = "canvas coordinates are loop indices bounded by WIDTH=32 / HEIGHT=24, \
              far inside f64's exactly-representable integer range"
)]
#[expect(
    clippy::suboptimal_flops,
    reason = "mul_add would obscure the parametric spiral formula, for a rasterizer \
              that runs once at build time"
)]
fn generate_swirl() -> [u8; BYTES] {
    let mut frame = [0u8; BYTES];

    // Spiral parameters (canvas coordinates: x=col, y=row, origin at top-left).
    // `phase` rotates the spiral's outer terminus (t=0). With phase = 7π/4 the
    // ribbon's outer end lands at the upper-right of the canvas, matching the
    // reference logo where the tail extends up-and-right from that corner.
    let cx = 15.5_f64;
    let cy = 11.5_f64;
    let r_outer = 11.0_f64;
    let r_inner = 1.0_f64;
    let turns = 1.75_f64;
    let stroke = 1.4_f64;
    let phase = 7.0 * PI / 4.0;

    for y in 0..HEIGHT {
        for x in 0..WIDTH {
            let dx = x as f64 - cx;
            let dy = y as f64 - cy;
            let r = dx.hypot(dy);
            // atan2 returns (-π, π]; normalise to [0, 2π).
            let theta = {
                let t = dy.atan2(dx);
                if t < 0.0 {
                    t + 2.0 * PI
                } else {
                    t
                }
            };

            let mut on = false;

            // The spiral passes through angle θ at multiple radii (one per turn).
            // We shift θ by `phase` so the spiral's outer terminus (t=0) lands
            // at the chosen orientation rather than the default right side.
            // For each turn k, the parametric arc length t_k = (θ - phase) + 2π·k,
            // and the radius at that point is r_outer - (r_outer-r_inner)·t_k/max_t.
            let max_t = 2.0 * PI * turns;
            let theta_shifted = {
                let s = theta - phase;
                let twopi = 2.0 * PI;
                ((s % twopi) + twopi) % twopi
            };
            // `turns` is a compile-time constant (1.75), so this bound is 3.
            // Kept parametric so changing `turns` still sweeps enough arms.
            #[expect(
                clippy::cast_possible_truncation,
                reason = "turns.ceil() is a small positive constant; i32 cannot overflow"
            )]
            let k_max = turns.ceil() as i32 + 1;
            for k in 0..=k_max {
                let t_k = theta_shifted + 2.0 * PI * f64::from(k);
                if t_k < 0.0 || t_k > max_t {
                    continue;
                }
                let r_k = r_outer - (r_outer - r_inner) * t_k / max_t;
                if (r - r_k).abs() < stroke {
                    on = true;
                    break;
                }
            }

            // (Tail extension intentionally omitted — straight extrapolation
            // from the spiral's outer terminus angles differently than the
            // ribbon's curve, producing a visible kink. Better to just end.)

            if on {
                let byte_idx = y * (WIDTH / 8) + x / 8;
                let bit_idx = 7 - (x % 8);
                frame[byte_idx] |= 1 << bit_idx;
            }
        }
    }

    // Vertical mirror (flip top↔bottom): row i swaps with row (HEIGHT-1-i).
    let row_bytes = WIDTH / 8;
    let mut mirrored = [0u8; BYTES];
    for row in 0..HEIGHT {
        let src = row * row_bytes;
        let dst = (HEIGHT - 1 - row) * row_bytes;
        mirrored[dst..dst + row_bytes].copy_from_slice(&frame[src..src + row_bytes]);
    }

    mirrored
}

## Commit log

2026-02-07 Clean up repo structure and remove dead code
    Structure changes:
    - Move blinky_test to examples/blinky.rs
    - Add maple_device_info example for reference
    - Move s140_softdevice to vendor/
    - Remove extracted zip file
    Code cleanup:
    - Remove unused scaffolding (bus.rs, mock_bus.rs, state_machine.rs, traits.rs)
    - Remove unused board module and config.rs
    - Remove empty dma.rs and state.rs
    - Clean up unused functions in gpio_bus.rs
    - Fix all clippy warnings
    - Use iterators for better performance in sampling loops
    - Switch get_condition to bulk sampling
    Kept for next feature:
    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
    [gpio_bus.rs, host.rs, lib.rs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]
2026-02-08 Implement BLE HID gamepad with working inputs
    Add complete BLE HID over GATT (HOGP) implementation:
    - HID Report Descriptor with Xbox-compatible button layout
    - All Dreamcast inputs mapped: ABXY, Start, D-pad, analog stick, triggers
    - Just Works pairing with security/bonding support
    - 60Hz polling with change-based notifications
    Button mapping empirically adjusted for macOS/browser compatibility.
    Triggers use signed axes (-127 to 127).
    Known issue: BLE reconnection requires forgetting device - bonding
    persistence needs investigation.
    [gpio_bus.rs, host.rs, lib.rs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]
2026-02-08 Improve BLE sys_attrs handling for reconnection
    Track sys_attrs length separately to avoid passing garbage data.
    Auto-reconnection works but sys_attrs restoration still needs debugging.
2026-02-08 Add flash-based bonding storage and reduce logging
    - Persist BLE bonding data across power cycles using last flash page
    - Minimize RTT logging to reduce CPU load during operation
    - Remove unused custom GATT service (replaced by HID)
    - Add flash/debug commands reference documentation
    [main.rs, mod.rs]
2026-02-10 Add triple-press sync button to toggle device name
    Store name preference (Xbox vs Dreamcast) in flash at 0xFD000.
    Triple-press sync button within 2s toggles preference and resets.
    Default remains "Xbox Wireless Controller" for iBlueControlMod compatibility.
    [main.rs, mod.rs]
2026-02-19 Extract dc-protocol lib crate, add tests, README, and user guide
    - Extract pure protocol logic into dc-protocol/ workspace crate (no embedded
    deps) so it can be tested on the host with `cargo test`
    - 24 tests covering controller state parsing, HID report generation, packet
    construction, state change detection, and button/trigger/stick roundtrips
    - Fix controller_state_parse test that had wrong assertions (never ran before)
    - Move state_changed() from free function to ControllerState method
    - Add inactivity sleep timeout (10 min) and battery SAADC reading (XIAO)
    - Rewrite README with features, hardware, build/flash, and project structure
    - Add docs/users_guide.md for non-technical end use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
    [host.rs, lib.rs, main.rs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]
2026-02-19 Sleep after sync timeout when no bond exists
    Without a bond, the device looped indefinitely between sync mode
    and idle. Now enters System Off after 60s sync timeout with no
    pairing. Wake via sync button resets and retries pairing.
    [main.rs]
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2026-02-20 Fix QSPI flash DPD and add startup battery reading
    Replace QSPI peripheral DPD with GPIO bit-bang approach — the QSPI
    peripheral had configuration issues (wrong CINSTRCONF offset, missing
    IFCONFIG0/1, unreliable TASKS_ACTIVATE). Bit-banging CS/SCK/MOSI to
    send the 0xB9 DPD command is simpler and reliable.
    Add initial battery read at startup so the voltage/percentage always
    appears in the RTT log, even when BLE connects too fast to read during
    the wait phase.
    [main.rs, xiao.rs]
2026-02-20 Restore continuous reporting and reduce stick deadzone
    Always send HID reports at ~60Hz regardless of state change — fixes
    sluggish stick feel caused by change-only reporting. Inactivity timer
    still only updates on actual input change.
    Reduce stick deadzone from 10 to 5 (Dreamcast units). The old value
    ate ~8% of half-range; the new value filters jitter while preserving
    more usable stick travel.
    [main.rs]
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2026-02-20 Fix wake from manual sleep by waiting for button release
    Enter System Off only after the sync button is released, so the GPIO
    SENSE LOW condition isn't already met when sleep begins. Previously
    the button was held LOW during sleep entry, preventing wake on next
    press.
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2026-03-17 Fix sync mode while connected, harden GPIO sleep, and open-source prep
    - Fix sync mode: listen for sync signal during active BLE connection,
    explicitly disconnect before entering pairing mode
    - Fix button hold: sync only fires on release (3-10s), holding through
    to 10s goes straight to sleep without clearing the bond
    - GPIO: disconnect all pins at boot (clear bootloader residue) and
    before System Off (catch any configured pins), skip P0.28 at boot
    to avoid momentary boost enable
    - Remove unused constants (P1_BASE, PIN_CNF_OFFSET, WAKE_PIN_NUM)
    - Add "Forget This Device" guidance to user guide
    - Open-source release prep: docs, CI, contributing guide, cleanup
    [dreamcast_vmu_back_cutout.stl, dreamcast_vmu_back_sync_merged_wo_usb_sideout.blend, dreamcast_vmu_back_w_cutout.stl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]
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2026-03-18 Battery improvements, panic logging, RTT feature gate, and cleanup
    - LiPo lookup table: 0% cutoff at 3300mV (measured protection circuit)
    - 8x SAADC oversampling for stable voltage reads
    - Monotonic decrease: battery % never increases unless charging
    - Instant-based battery read timing (replaces countdown subtraction)
    - Flash-based panic handler: writes to 0xFC000, prints on next boot
    - RTT logging gated behind `rtt` feature (DK always on, XIAO opt-in)
    - Remove unused deps: embedded-hal, embedded-hal-02, nb, futures
    - Update docs with RTT feature flag and build instructions
    [gpio_bus.rs, lib.rs, main.rs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]
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2026-03-20 WIP: VMU LCD support with timeslot TX and pixel art
    - Add VMU module: pulsar logo (48x32 1bpp), battery icon (12x7),
    AND-then-OR compositing, 180° rotation for upside-down mount
    - Add SoftDevice Radio Timeslot TX: pre-computed GPIO waveforms
    blasted in interrupt-free timeslot callbacks for clean signals
    - Add Maple Bus LCD write: BLOCK_WRITE with 50-word payload,
    byte-swapped pixel data, location word, fire-and-forget enum
    - VMU learnings doc with protocol details, timing analysis,
    and BLE coexistence findings
    Status: LCD write works (image displays correctly), but timeslot
    TX disrupts BLE connections. Needs RTT investigation for VMU
    presence detection and BLE coexistence work.
    [gpio_bus.rs, host.rs, lib.rs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]
2026-03-20 WIP: VMU LCD visuals with timeslot TX and 3s delay
    - Pulsar logo + battery icon compositing on VMU LCD
    - SoftDevice Radio Timeslot for interrupt-free long TX
    - 3s delay after BLE connect before VMU write attempt
    - Fire-and-forget: enumerate once, write once, no retry
    - Known issue: heavy controller input after VMU write crashes BLE
    [gpio_bus.rs, main.rs, vmu.rs]
2026-03-20 Switch VMU LCD write to direct bit-bang, keep timeslot as reference
    Direct bit-bang TX works for VMU LCD writes without disrupting BLE.
    The SoftDevice Radio Timeslot API caused BLE connection instability
    even with NORMAL priority and session open/close per write.
    The timeslot version is preserved as write_vmu_lcd_timeslot() for
    reference. The simple bit-bang approach matches how controller
    polling already works — SoftDevice interrupts during the ~1.6ms TX
    either don't fire or the VMU tolerates minor timing glitches.
    [gpio_bus.rs, host.rs]
2026-03-20 Update VMU learnings: bit-bang TX resolves BLE coexistence
    Direct bit-bang works — timeslot API was the BLE disruption source.
    Updated next steps to focus on consistency and battery integration.
2026-03-20 Wire battery percent to VMU LCD, restore original recovery path
    - Track vmu_battery_percent from battery reader in poll loop
    - VMU LCD re-writes when battery bar count changes
    - Cooldown after each write attempt prevents rapid retries
    - Controller recovery path unchanged from known working state
    [main.rs]
2026-03-20 Update VMU learnings with recovery findings and DK RTT plan
    - Document controller recovery behavior after VMU writes
    - Backoff is necessary (fixed retry breaks recovery)
    - DEVICE_INFO after VMU write makes things worse
    - Battery updates confirmed working (4→3 bars observed)
    - Next step: RTT session on DK board to diagnose bus state
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2026-03-30 Add rotating pulsar VMU animation with radio notification scheduling
    Use SoftDevice radio notifications (SWI1_EGU1) to schedule VMU LCD
    writes during BLE radio idle windows, avoiding SoftDevice interrupt
    corruption of the ~1.65ms bit-bang TX. Falls back to unscheduled
    writes if radio idle is never signaled.
    Separate content production from the generic VMU writer — producers
    write raw pixels into a framebuffer, the writer composites battery
    overlay and rotation before sending. Any future content source
    (dongle, game icon) just writes to the framebuffer and sets dirty.
    Animation: rotating pulsar with filled cone jets using scanline
    triangle fill. Runs continuously at ~6fps.
    Research doc c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
    [gpio_bus.rs, main.rs, maple.rs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]
2026-05-08 WIP: BLE profile system + wake/sleep refinements
    Profile system:
    - STD profile (PID 0x02E0, MS-gappy layout) and EXT (PID 0x0B20, contiguous)
    - Triple-press toggles + flash persistence at 0xFD000 with V2 magic
    - Profile-driven softdevice + GamepadServer init
    - 32x24 VMU splash glyphs, generated swirl via build.rs
    Wake/sleep:
    - HCI disconnect-reason classification (host-intentional vs lost)
    - Controller-input wake-poll (1.5s base, 5s backoff when no controller)
    - Sync-button short-press WAKE_REQUEST signal
    - had_connection flag: boot reconnects, post-disconnect stays silent
    - Goodbye state machine + 1s hold + System Off (XIAO) / WFI (DK)
    HID hygiene:
    - Wake-fix L1: state_changed deadzone-aw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
    [build.rs, lib.rs, main.rs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]
2026-05-08 Remove controller-input wake-poll
    Boost converter is disabled in Phase 1 on XIAO to save power, which means
    the controller has no 5V — every Maple poll would time out. Cycling boost
    per poll would cost ~0.5 mA continuous (~30% reduction in disconnected
    idle time). Not worth it for the marginal UX gain.
    Sync-button short-press WAKE_REQUEST remains as the wake gesture, matching
    the Xbox Guide / PS button pattern.
    [main.rs]
2026-05-08 Fix goodbye stuck on BYE splash, harden enter_system_off
    The goodbye state machine in Phase 3 waited for vmu_frame_dirty to clear
    before transitioning Wait → Hold → enter_system_off. host.write_vmu_lcd()
    sends the LCD bytes successfully (BYE renders), but its Ack reception is
    a ~150 µs Maple bus read that gets corrupted whenever a BLE radio ISR
    fires during the window. The function returns false even though the LCD
    updated, the dirty flag never clears, and the state machine loops in
    Wait forever.
    Added a 500 ms fallback timeout in Wait. The user has visibly seen BYE
    by then; we don't actually need the Ack to confirm forward progress.
    Also hardened enter_system_off:
    - Spin-wait for P1.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
    [main.rs, xiao.rs]
2026-05-08 Document VMU display, profile system, and updated sync gestures
    User guide:
    - Rewrote sync button section as a 4-row action table covering all
    gestures (short press, 3s hold, 10s hold, triple-press).
    - Added "Profiles" subsection explaining STD vs EXT and when to use each.
    - New "VMU Display" section showing the four splashes (STD, EXT, SYNC,
    BYE) plus the rotating pulsar in-session view, with a note that LCD
    updates cost roughly 5–10% of battery life.
    - Updated LED indicator and troubleshooting entries to reflect the
    profile toggle (replaces the old name-only toggle).
    README:
    - Added VMU display + dual-profile bullets to the features list.
    - Expanded the sync button bullet list t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
2026-06-04 Add BlueRetro QEMU regression harness for issue #2 button mapping
    Move HID_REPORT_DESCRIPTOR_STD/_EXT into maple-protocol so a host build can
    emit them (hid.rs re-exports). Add a pytest harness that feeds our STD
    descriptor and serialized reports to BlueRetro firmware running under QEMU
    and asserts each button maps to the right generic function — reproducing
    the issue #2 mis-map in software, no nRF hardware required.
    - maple-protocol/tests/blueretro_fixtures.rs generates and drift-guards
    tests/blueretro/fixtures.json (runs in scripts/ci.sh)
    - tests/blueretro/pytest_pulsar_dreamcast.py + README
    - .github/workflows/blueretro-pytest.yml (pinned BlueRetro checkout)
2026-06-04 Add D-pad, axes, and EXT-probe tests to BlueRetro harness
    Three more checks against the same QEMU harness, reusing the STD descriptor
    and BlueRetro's own generators (no new fixtures):
    - test_pulsar_std_dpad_mapping: hat switch -> D-pad (hat_to_ld_btns)
    - test_pulsar_std_axes_scaling: sticks/triggers (xbox_axes); pins the 4-byte
    Logical Maximum and verifies Rx/Ry + Z/Rz land on the expected axes, guarding
    the signed -1 stick regression
    - test_pulsar_ext_buttons_probe: xfail-tolerant probe of the EXT profile on
    BlueRetro's generic-HID path (A,B,C,X,Y order vs our contiguous A,B,X,Y)
2026-06-04 Add control/baseline test to BlueRetro harness
    Runs the button-mapping assertions against BlueRetro's own reference Xbox
    descriptor (imported from their suite) before testing ours. Must be green —
    it proves the harness wiring and assertions are correct, so a red STD test
    is a genuine finding about our descriptor rather than a harness bug.
    Refactors the shared button-check into _check_buttons(); control and STD now
    differ only by the descriptor under test.
2026-06-05 Fix STD descriptor to match real Xbox One S BLE (issue #2)
    The harness reproduced issue #2: BlueRetro did not recognize our STD descriptor
    as an Xbox controller and generic-HID parsed the buttons by Usage number, so
    everything from the 3rd button shifted (X read as C, Y as X, Start as RB, ...).
    Make STD Report ID 1 byte-identical to the real Xbox One S BLE descriptor:
    - right stick Rx/Ry -> Z/Rz
    - triggers Generic-Desktop Z/Rz -> Simulation-Controls Brake/Accelerator
    - buttons gappy Usage ranges -> contiguous Button 1-15 + Consumer Record
    Serializer (to_bytes_ms) unchanged — it still emits the gappy wire layout a real
    Xbox sends; once BlueRetro fingerprints the descriptor it applies its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
2026-06-05 Harden BlueRetro control gate and correct to_bytes_ms wire-layout doc
    - Control test: hard-import the BlueRetro reference module instead of
    importorskip, so a missing/renamed module fails the harness gate rather
    than silently skipping it.
    - to_bytes_ms doc: the STD descriptor now advertises a real Xbox One S BLE
    controller that BlueRetro fingerprints by shape (not VID/PID); document
    that the gappy wire layout is intentional and must not be aligned to the
    contiguous Button 1-15 declaration (issue #2).
2026-06-14 Release v0.2.6: issue #5 input-rate fix, VMU LCD display
    Squashed public release (v0.2.2 -> v0.2.6). Internal dev logs and design
    scratchpads (docs/working_logs/, input_quality_testing.md, vmu_game_icons.md)
    are kept private and excluded from this mirror.
    Highlights since v0.2.2:
    - Fix issue #5: fast stick/d-pad rotations no longer drop directions
    (~14Hz -> ~60Hz effective report rate; edge-based Maple decode + poll tuning).
    - VMU LCD display: boot splash + animated pulsar + battery overlay.
    - Pinned-asm Maple RX sampling (~7.9 Msamples/s); hardware-timed PWM/EasyDMA VMU LCD writes.
    - Bond-storage hardening (CRC body, magic-last); power-fail comparator canary.
    [gpio_bus.rs, host.rs, lib.rs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]
2026-06-14 Release v0.2.7: center stick on disconnect (#6), ship VMU LCD in artifacts
    - Fix #6: the analog stick no longer jams to the upper-left corner when the
    controller cable is unplugged mid-use — the neutral/disconnect state now
    centers the stick (was reading the all-zero raw value = left+up).
    - Ship the VMU LCD firmware in the release artifacts for both boards; the
    0.2.6 artifacts were built without it, leaving the VMU display blank.
2026-06-14 Release v0.2.8: codegen-immune controller TX, VMU always-on
    Curated public mirror of the v0.2.8 build. Internal dev logs and design
    Highlights since v0.2.7:
    - Cycle-anchored bit-bang Maple TX: the controller command TX half-bit period
    is now clocked off the DWT cycle counter (155 cycles/half-bit @ 64 MHz)
    instead of a NOP loop whose real duration was an LTO/codegen artifact — an
    unrelated code change could re-inline the TX path and move the wire timing.
    The schedule resyncs to the delivered edge on interrupt overshoot, so a
    stall stretches one half-bit ra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
    [gpio_bus.rs, host.rs, main.rs]
2026-06-22 Release v0.3.0: universal Xbox profile (Windows fix), Guide chord, VMU home glyph
    - BLE host compat: real BLE-Xbox identity (0x045E/0x0B20) + a backed rumble
    Output report (Report ID 3) fixes the Windows 'Bluetooth LE XINPUT' Code 10.
    The Xbox profile now works on macOS, Windows, Linux (xpadneo), Steam, and
    BlueRetro.
    - Generic 'Dreamcast' profile: neutral 0x1209/0xDC01 — a plain generic BLE HID
    gamepad (not controller emulation; only the Bluetooth name is Dreamcast).
    - Guide/Xbox button chord: hold L+R+Start (~300 ms) to send Guide — opens the
    Steam overlay, etc. Native Guide bit on Xbox; Button 11 on the generic profile.
    - VMU: flashes a home glyph when the Guide chord fires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
    [build.rs, lib.rs, main.rs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]
2026-08-10 chore: ignore build products, drop stale references and a third-party model
    The ignore rules cover bootloader build output, KiCad auto-backups, screen
    recordings, and the ad-hoc test dir, so `git status` stays readable and a real
    untracked file stands out.
    Two comments pointed at a documentation path that does not exist in this
    repository. Refer to the measurements by date instead.
    Dreamcast+VMU+Shell.zip was another creator's model carried verbatim, and the
    README asserted CC BY 4.0 over it. The enclosure here does not derive from it —
    it was modelled against Wesk's VMU scans — so the file was never load-bearing.
    Remove it and correct the attribution to state the actual chain, scoping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
2026-08-10 feat(maple): anchor the poll loop and make wire timing codegen-immune
    Identical source could time differently from build to build — the "layout
    lottery". Root cause was phase coupling between the poll loop, the BLE
    connection interval, and the LF clock; a bad binary layout let the Maple
    transaction dwell inside radio events, driving retries up and the effective
    report rate down by up to 30%.
    Two structural fixes, both of which must survive future cleanup:
    - The RX sampling loop is pinned inline asm with an exact encoding at a
    word-aligned address. A misaligned branch target costs +1 fetch cycle per
    iteration on Cortex-M4; over 24,576 samples that is +384 us and the bus misses
    the w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
    [gpio_bus.rs, host.rs, lib.rs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]
2026-08-10 feat(ble): harden host compatibility and connection handling
    The connection interval is the host's to choose — the firmware requests
    8.75-11.25 ms and macOS hands back ~15 ms regardless. Stop treating the request
    as if it were binding and report what was actually negotiated.
    Wire-level dedup: identical consecutive 16-byte payloads are not re-notified,
    which keeps the link quiet without the send-on-change semantics that break Xbox
    HID compatibility. The cache is dropped immediately after every connection ends,
    hoisted out of the disconnect match so an arm added later cannot forget it — a
    newly paired host must never have its first report suppressed against the
    previous host's state.
    Clo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
    [task.rs]
2026-08-10 feat: wire the board contract through the main loop and gestures
    main.rs is board-agnostic — the battery logic branches on the shape of the
    reading, not on which board is compiled in. A percent-only gauge (25% buckets)
    and a millivolt gauge take different paths to the same cutoff, and the two
    thresholds are defined together because they must not drift apart.
    The sync-button hold is a pure state machine in maple-protocol: elapsed
    milliseconds and the controller's Start mirror go in, actions come out, and
    button.rs supplies the clock and performs the side effects rather than
    re-deriving the decision. Sync at 2 s, OTA DFU at 3.5 s with Start held, sleep
    at 7 s. Ten unit tests pin the release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
    [lib.rs, main.rs, vmu.rs]
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2026-08-10 hardware: publish the VMU enclosure models
    Printable shells for a VMU-housed build: front, rear, button plunger, and a
    combined print plate, in two variants for the 703035 and larger cells.
    The Blender scripts that generate them are included. They resolve paths from the
    script's own location, and fall back to bpy.data.filepath because Blender's text
    editor does not set __file__.
    pulsar_pcb.stl is a mesh for fit-checking only — board outline and component
    heights. It is not manufacturing data and no board can be fabricated from it.
    [Pulsar.step, dreamcast_vmu_back_printed_raw.blend, dreamcast_vmu_front_printed_final1.blend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]
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2026-09-01 feat(vmu): show a charging bolt instead of a battery level
    While a charger is attached the pack's terminal voltage is pulled up, so the
    level reads high — a battery that shows full and empties the moment you
    unplug. The bolt replaces the bars rather than adding a state, and the level
    returns as soon as charging stops. The icon empties completely as a critical
    cue. Compile-time asserts keep the bolt inside the outline and mask.
    [vmu.rs]
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2026-09-01 hardware: add the big-cell cable-relief shell and say which family fits which build
    The README named none of the four shell families, so a reader could not tell
    whether PulsarFit_703035 or the loose dreamcast_vmu_*.stl matched what they
    built. The cable-relief variant ships flagged as not yet fit-tested, and exists
    only as STLs — re-running the build scripts reproduces shells without it.
    Validated before publishing: all three STLs non-truncated with no boundary
    edges; the cable-relief front has 29 over-shared edges against the shipping
    big-cell front's 30.
    [pulsar_bigcell.3mf, pulsar_bigcell_cable_relief.3mf, pulsar_vmu_button_plunger.stl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]
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2026-09-29 feat: VMU saves and the host service, 8BitDo adapter support, the link and battery fixes
    - HostService: a vendor GATT service a host uses to draw on the docked
    VMU's LCD and to read and write its 512-byte blocks (docs/host_integration.md).
    ATT MTU raised to 247 so one write carries a whole frame. Writes,
    subscription and notifies need an encrypted link from the bonded host.
    - Saves drain to the VMU behind a card fingerprint: a swapped card ends the
    generation, a torn FAT or root phase is still recognised as the same card,
    and every session-ending gesture (pairing, profile switch, update,
    configuration, sleep) is refused while saves drain, closing write admission
    in the same ste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
    [block_read.rs, block_write.rs, build.rs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]
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

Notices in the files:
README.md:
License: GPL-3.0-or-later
